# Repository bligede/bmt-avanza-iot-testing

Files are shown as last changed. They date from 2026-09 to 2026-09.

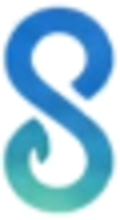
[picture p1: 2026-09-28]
web-argo/assets/mark.png

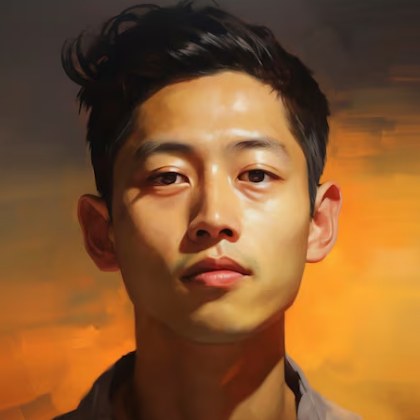
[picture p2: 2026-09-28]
web-argo/assets/driver.jpg

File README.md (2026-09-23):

# bmt-avanza-iot-testing

Bring-up firmware for the **Avanza CAN reading test**. ESP32-S3 + SN65HVD230,
WiFi hotspot, live web dashboard. Built with **PlatformIO**.

Fleet firmware lives in
[bligede/bmt-can-bus-telemetry](https://github.com/bligede/bmt-can-bus-telemetry).
This is a separate, focused diagnostic tool — not a subset of the product.

---

## The one rule

**The device is listen-only, permanently.** It reads the vehicle CAN bus and
never writes to it — no data frames, no remote frames, no ACK, no error frames.

Enforced in three independent places:

| Layer | Mechanism |
|---|---|
| Controller | `TWAI_MODE_LISTEN_ONLY`; `CanManager` refuses to start in any other mode |
| Compiler | `#pragma GCC poison` on the transmit entry points — a call fails to build |
| Release gate | `sh tools/check_listen_only.sh` |

Run the gate before any build that goes near a vehicle.

---

## Where the project documentation lives

`ProjectDocs/` is the handover layer: who decides, what was decided, the
environment map, current state, and what NOT to do. Start at
`ProjectDocs/agent-documentation/00-START-HERE.md`.

It **routes** to `docs/`; it does not duplicate it. The test reports, the
evidence and the procedures stay where they are, and so do the paths that
`project-mdt-tds` references.

---

## What this answers, and what it does not

| Question | |
|---|---|
| Can the device passively read a real vehicle CAN bus? | **this is the point** |
| Does listen-only hold on a live vehicle? | yes |
| Does WiFi hurt CAN acquisition? | measured — see below |
| Does the GNSS module work, and NmeaParser with it? | yes — first run on hardware |
| How hot does the enclosure actually get? | yes — the fleet's open thermal TODO |
| Are the fleet's odometer / SoC / speed CAN IDs found? | **no.** Wrong vehicle |
| Does the 4G + MQTT + TLS uplink work? | **no.** Not present at all |

Three modules get their first hardware run here, all of them on the fleet
project's *NOT TESTED* list: **`NmeaParser`** (21 unit tests, zero executions),
the **bit-banged DHT22 driver** (written from the datasheet, never run), and the
**fan hysteresis**. Retiring them costs nothing extra on this trip.

The thermal panel exists for a specific open question: `FAN_ON_TEMP` and
`FAN_OFF_TEMP` in the fleet firmware are placeholders marked *TODO — VALIDASI
TERMAL*, because nobody has measured an enclosure in a parked car in Bali sun.
The dashboard shows **both** the DHT22 enclosure reading and the SoC die
temperature; the gap between them is the number that decision needs.

> Avanza CAN IDs prove the **reading path**. They are **not** a signal map.
> Nothing found here may be copied into the fleet's `signals.cfg` — Toyota and
> Wuling identifiers have no relationship, and a plausible-looking wrong number
> is the worst failure mode a fleet dataset can have.

An Avanza is a petrol car: **there is no state of charge**, and unlike the fleet
EV it does have standard OBD-II PIDs. Neither fact helps the fleet; both are
recorded so nobody draws the wrong conclusion from an easy result here.

---

## Quick start

### 1. Open in VS Code

Install the **PlatformIO IDE** extension, then `File → Open Folder` on this
repository. PlatformIO reads `platformio.ini` and installs the ESP32 platform on
first build. No libraries to add — this project has **zero third-party
dependencies**.

### 2. Credentials

```sh
cp src/Secrets.h.example src/Secrets.h
```

Fill in the hotspot SSID and password. `src/Secrets.h` is git-ignored.

> **The ESP32-S3 radio is 2.4 GHz only.** A 5 GHz hotspot will never be found,
> and the symptom is an endless `CONNECTING → IDLE` loop. Android: *Hotspot
> settings → AP Band → 2.4 GHz*. iPhone: enable *Maximise Compatibility*.

### 3. Check the board

`platformio.ini` assumes an **8 MB** `esp32-s3-devkitc-1`. For a 4 MB board,
change two lines:

```ini
board_build.partitions  = partitions/avanza_test_4mb.csv
board_upload.flash_size = 4MB
```

### 4. Build, upload, monitor

| | PlatformIO toolbar | Command line |
|---|---|---|
| Build | ✓ | `pio run -e <vehicle>` |
| Upload | → | `pio run -e <vehicle> -t upload` |
| Monitor | 🔌 | `pio device monitor` |

**Pick the vehicle first.** Each vehicle under test has its own env at the end of
`platformio.ini`; the toolbar builds `default_envs`.

| Env | Vehicle | Bitrate | `UNIT_ID` |
|---|---|---|---|
| `hrv` | Honda HR-V 2023 | 500 kbps, measured | `HRV-TEST-01` |
| `gelora-e` | DFSK Gelora E | 500 kbps, **not yet measured** | `GELORAE-TEST-01` |
| `gelora-e-250k` | DFSK Gelora E | 250 kbps | `GELORAE-TEST-01` |

The env sets `UNIT_ID`, which goes into every capture header, and the folder the
identifier names are kept in (`/notes/<UNIT_ID>/`). Identifier numbers repeat
across makes, so one car's names must never appear against another car's IDs.
A build with no vehicle selected stops with an error instead of guessing.

If upload fails: hold **BOOT** (GPIO0), tap **RESET**, release BOOT, retry.

### 5. Verify before going near a vehicle

```sh
sh tools/check_listen_only.sh
```

Must print `LISTEN-ONLY GATE: PASS`. Do not flash a build that fails it.

---

## Wiring

| Function | Pin | Device |
|---|---|---|
| CAN TX | GPIO5 | SN65HVD230 `D` — never driven in listen-only |
| CAN RX | GPIO4 | SN65HVD230 `R` |
| GPS RX | GPIO18 | ← GY-GPS6MV2 TX |
| GPS TX | — | **not connected** — GPIO19 is USB_D− on the ESP32-S3. Firmware only listens to NMEA |
| DHT22 | GPIO15 | DATA |
| Fan | GPIO13 | → 330 Ω → IRLZ44N gate |
| LED red | GPIO21 | via resistor |
| LED green | GPIO47 | via resistor |
| Button | GPIO0 | momentary, active low — **RESERVED**, prints status |

The SN65HVD230 also needs 3V3 and GND from the ESP32.

Everything except CAN is optional. A missing GPS, an unwired DHT22 or no fan
clears its own reading and touches nothing else — CAN acquisition is unaffected.

| OBD-II | To |
|---|---|
| pin 6 | CANH |
| pin 14 | CANL |
| pin 5 | ESP32 GND |
| **pin 16** | **nothing** — power the ESP32 from USB |

LED common cathode to GND.

### The 120 Ω terminator — staged, not removed once

A CAN bus needs 120 Ω at each end, about **60 Ω across CANH–CANL**. Where those
come from changes between bench and vehicle:

| Stage | Termination source | Module's 120 Ω |
|---|---|---|
| **Bench**, two nodes | The two nodes *are* the two ends | **KEEP FITTED** |
| **Vehicle** | The car is already terminated at ~60 Ω | **REMOVE** |

Being listen-only does not exempt the receiver from being a properly terminated
node. Measure ~60 Ω across the bus in **both** cases before powering anything.

---

## Before connecting to the car

Ignition **off**, key removed. Measure OBD-II pin 6 to pin 14:

| Reading | Meaning | Action |
|---|---|---|
| ~60 Ω | CAN present, terminated | proceed |
| ~120 Ω | one terminator | record, proceed |
| **open** | **no CAN on these pins** | **stop** — see below |

An **Avanza Gen 1 (2003–2011)** may use K-line on pins 7/15 and have no CAN on
6/14 at all. The resistance check settles it in thirty seconds; use a different
vehicle rather than debugging firmware that is behaving correctly.

Record the model year.

---

## The failure that wastes an afternoon

**A healthy car can produce zero frames.**

On many vehicles the OBD-II port exposes a *diagnostic* CAN channel that stays
silent until a scan tool sends a request. This device is listen-only and never
sends anything. So a perfectly good Avanza can give you:

```
resistance 6–14 : 60 Ω     ✓ bus present
frames received : 0        ✗
```

That is not a broken device, a wrong bitrate, or bad wiring — it may simply be a
gateway that does not broadcast to the port.

**Prove the device on the bench first**, with a second CAN node transmitting.
Then "no frames" is a fact about the car rather than a mystery about the tool.
The bench test is not optional; it is what makes the vehicle result readable.

---

## Using it

Power up, open the serial monitor at 115200. Once WiFi connects:

```
[WIFI] Connected. IP 192.168.43.101, RSSI -52 dBm
[WIFI] Dashboard: http://192.168.43.101/
```

Open that URL on the phone.

### LED indicators

800 ms cycle. Highest-priority state wins.

**Red means something is broken. Red does NOT mean "waiting".**

| Pattern | Meaning | What to do |
|---|---|---|
| 🔴🟢 alternating | booting | wait ~0.5 s |
| 🔴 **solid** | filesystem dead | LittleFS would not mount |
| 🔴 **fast blink** | **CAN driver failed** | wiring, or `twai_driver_install` failed — check the log |
| 🟢 **heartbeat** (2 short flashes) | **CAN frames arriving** — the goal | nothing, this is success |
| 🟢 steady with a **brief red wink** | GPS is talking but has no fix yet | wait, or get sky view |
| 🟢 **fast blink** | WiFi connecting | wait, or check SSID/2.4 GHz |
| 🟢 **slow blink** | WiFi up, **no CAN frames yet** | normal on a bench with no bus attached |

A bench board with WiFi up and nothing on CANH/CANL shows the **slow green
blink**. That is the correct idle state, not a fault.

### Dashboard

| Panel | What matters |
|---|---|
| **Bus status** | the verdict sentence; `received` climbing; `missed` is the driver's own count of **frames** lost |
| **Identifiers** | every ID on the bus in ID order, latest bytes in **hex with decimal underneath**, bytes that just changed lit, silent IDs dimmed, an empty **Name** field beside each ID, ready to fill in and save — one view, no scrolling |
| **Signal probe** | pick an ID, start byte, width, byte order: the decoded value live, with a sparkline |
| **Health** | is the ESP32 keeping up — queue peaks, stack headroom per task, heap low-water, loop lag, CPU per core |
| **Capture** | frames written, operator markers, and the capture **files, downloadable** |
| **GNSS** | fix, satellites heard, strongest signal — and a sentence naming the fault |
| **Thermal** | DHT22 enclosure temp *and* SoC die temp, fan state |
| **Device** | unit, WiFi, wall clock, and what the status LED is saying |

Type a note into the Identifiers table while testing — "moves with the brake
pedal" — and press Enter. Notes are saved on the device under `/notes/`, **apart
from the captures**: a note is what somebody thinks an identifier is, and that is
kept separate from the evidence (D-015). Every edit is journalled with its time.

The Health verdict reads **Overworked** only on things that precede lost data: a
queue near full, a stack near its end, the heap near empty, frames being lost
right now. CPU load is shown but not trusted for it — see `SystemHealth.h` for why
the figure under-states load on this framework.

### Console

```
help              command list
status            full report
ids               distinct CAN IDs with counts
gps               GNSS fix, ground speed, UTC
env               DHT22 temperature and humidity
fan               fan state and thresholds
fan auto|on|off   fan mode
wifi              WiFi state and dashboard URL
capture file      raw frames to flash (default, on from boot)
capture off
ls                list capture files
cat <path>        print a capture — this is how you pull it off
clearcaptures
restart
```

Capture starts automatically at boot, so a session that only turns out to be
interesting halfway through has still been recorded.

### Pulling and analysing a capture

**Over WiFi (preferred):** the Capture panel lists every file on the device;
click one to download it. Take finished segments — the one marked *writing* still
lacks what sits in RAM. The notes journal is listed there too.

**Over the serial console:**

```
capture off
ls
cat /capture/can-000.log
```

**For the reverse-engineering skill** (`cansub-reverse-engineering`), convert to
webCAN CSV first:

```sh
python tools/capture_to_webcan.py can-003.log can-004.log -o captures/run-002.csv
```

It refuses to put files from two different boots on one timeline, and says so
when a capture has no wall-clock header. Operator markers go to
`run-002.markers.csv`.

For a quick known-value search without the skill:

```sh
python tools/can_find_value.py captures/avanza-....log --value 40 \
    --name speed --tolerance 1 --no-stable
```

The tool searches for a value you read off the dashboard across every plausible
field position, width, endianness and scale. **A candidate is a hypothesis, not
a mapping** — and on an Avanza it is a hypothesis about a Toyota, which the
fleet does not run.

---

## Known risk: WiFi versus CAN acquisition

Disclosed because it is real and unmeasured.

The ESP-IDF WiFi driver runs its own tasks at a **higher priority than the CAN
reader**, and depending on the core build may schedule them on **core 0** — the
core reserved for acquisition.

Mitigations in place: the TWAI hardware FIFO plus a 64-deep driver queue absorb
short preemption; the dashboard is the lowest-priority task on core 1; frames
reach it through a queue on core 1, so the reader only does one non-blocking
enqueue.

**None of that has been measured yet.** The Health panel now measures it — the
CAN driver queue peak, frames lost by the driver, and CPU per core. Treat it as an
acceptance criterion:

- [ ] Health → *Frames lost by driver* stays 0 with the dashboard being polled
- [ ] Health → *CAN driver queue* peak stays well under half
- [ ] `dropped` stays 0
- [ ] a 2-minute window with the dashboard open matches 2 minutes with it closed

If those counters move, record it. That finding matters more than a clean pass.

---

## Layout

```
platformio.ini            build config
src/
  main.cpp                setup + FreeRTOS tasks
  Config.h                every tunable
  Secrets.h.example       copy to Secrets.h
  CanBusSafety.h          the compile-time transmit ban
  CanManager.*            TWAI receive, listen-only locked
  GpsManager.* NmeaParser.*   GNSS fix, ground speed, UTC
  EnvironmentManager.*    DHT22 temperature and humidity
  FanManager.*            fan with hysteresis and dwell
  ButtonManager.*         GPIO0, reserved
  RawCanLogger.*          capture to serial and/or LittleFS
  WifiManager.*           non-blocking WiFi state machine
  WebDashboard.*          HTTP routes only
  StateJson.*             the JSON documents the page reads
  JsonWriter.h            bounded JSON writer, zero dependencies
  FrameRing.*             last frames, for /api/frames
  NotesStore.*            identifier notes, kept apart from captures
  SystemHealth.*          heap, stacks, queues, loop lag, CPU per core
  generated/WebAssets.h   GENERATED from web/ at build time — do not edit
  SerialConsole.*         technician console
  StatusLed.*             non-blocking LED patterns
  WatchdogManager.*       10 s task watchdog
  Logger.*                levelled console
web/                      the dashboard: index.html, app.css, app.js
hardware/                 PCB rev A: generator, KiCad schematic, BOM, netlist, verifier
partitions/               flash layouts
tools/
  check_listen_only.sh    release gate
  embed_web.py            web/ -> gzipped header, runs before every build
  capture_to_webcan.py    capture files -> webCAN CSV for the RE skill
  can_find_value.py       known-value search over a capture
captures/                 raw logs (git-ignored)
docs/RUN-PROCEDURE.md     how to run a controlled drive
docs/PHASE-2-DASHBOARD.md phase-2 plan, CEO questions, RE workflow
docs/evidence/            test artifacts
```

`CanBusSafety`, `Logger`, `StatusLed`, `WatchdogManager` and `WifiManager` are
copied from `bmt-can-bus-telemetry@7586b27` unmodified.

**Two are no longer identical, and this says so rather than pretend otherwise.**
The rule used to be "fix it in the fleet repo and re-copy". That repo is under a
feature freeze (its D-006), so both changes were made here and must be ported
back when the freeze lifts:

| File | Diverged in | What changed | Why |
|---|---|---|---|
| `RawCanLogger` | `fd386ba` | 4 KB RAM write buffer; segment header with unit, firmware, bitrate, boot epoch; `mark()`; queue-drop count | the writer fell behind the bus at ~1,300 frames/s (review F-05) |
| `CanManager` | Phase 2 dashboard | per-ID latest payload under a seqlock (`survey`, `seenIdSnapshot`); `driverCounters()` exposing the TWAI driver's own frame counts | the monitor table needs payloads; "missed" was counting alert events, not frames (review F-02) |

The listen-only mechanism itself is untouched in both: `TWAI_MODE_LISTEN_ONLY`,
the poison pragma and the release gate are exactly as in the fleet firmware.

---

## Evidence

Raw evidence is immutable after a test. `serial-log.txt` is the primary source;
`result.md` carries the interpretation and may be revised.

Save the **whole** serial session, from the first boot line — not just the
interesting part. Reset reason, init order, warnings, heap and startup timing
are what answer "was our hardware ever healthy?" when a later test goes wrong.

Record failures too. A folder saying FAIL with the log attached is worth more
than a missing one.

---

## Legal boundary

This device is **not** a legal measuring instrument. Its output must never be
used to calculate passenger fares.

## Classification

Internal — PT Bali Mikro Teknologi.

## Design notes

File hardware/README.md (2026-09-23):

# PCB BMT CAN logger, rev A

Satu papan untuk dua peran, dirakit dan disolder sendiri:

| Peran | Yang dipasang |
|---|---|
| **Perangkat uji** | semua, **kecuali** bagian bertanda `FLEET` |
| **Unit armada** | semua, termasuk bagian modem A7670C |

**Status: rancangan, belum pernah diproduksi.** Rangkaian sudah diperiksa secara otomatis
(lihat §7), tetapi berkasnya belum pernah dibuka di KiCad maupun EasyEDA. Keduanya belum
terpasang di mesin tempat berkas ini dibuat. Sebelum memesan PCB, kerjakan dulu daftar
di §8.

---

## 1. Berkas

| Berkas | Isi |
|---|---|
| `gen_schematic.py` | **sumber kebenaran**: seluruh rangkaian sebagai data. Ubah di sini, bukan di berkas hasil |
| `bmt-can-logger.kicad_sch` | schematic KiCad 7 hasil generator, untuk diimpor ke EasyEDA |
| `bmt-can-logger.kicad_pro` | berkas proyek minimal supaya KiCad membukanya sebagai proyek |
| `netlist.csv` | 37 net: nama net → `REF.pin`. Cadangan kalau impor gagal |
| `bom.csv` | daftar belanja: kolom `fit` = `ALL` atau `FLEET` |
| `schematic-preview.svg` | gambar schematic, cukup dibuka di browser |
| `verify_schematic.py` | membaca ulang `.kicad_sch` dan membuktikan isinya |
| `render_preview.py` | membuat `schematic-preview.svg` |

Setelah mengubah rangkaian:

```
python gen_schematic.py && python verify_schematic.py && python render_preview.py
```

---

## 2. Blok rangkaian

```
 12 V ACC ─ J1 ─ F1 PTC ─┬─ D1 1N5822 ─ VIN_P ─┬─ U1 LM2576HV-5.0 ─ +5V ─┬─ D3 ─ DevKit 5V
 (fuse tap, 3 A)         │                     │                         ├─ U3 VCC (CAN)
                         D2 1.5KE27A           │                         ├─ GPS
                         (surge / polaritas)   │                         └─ kipas (JP3)
                                               └─ U2 LM2576HV-ADJ ─ +4V0 ─ JP1 ─ modem   [FLEET]

 OBD-II 6/14/5 ─ J2 ─ D4 ESD ─ U3 TJA1051T/3 (S = HIGH → Silent) ─ RXD ─ GPIO4
                         └ R5 120 R ─ JP2 (bench saja)

 DevKit 3V3 ─ U3 VIO, DHT22, pull-up        GPIO18 ← GPS    GPIO15 ↔ DHT22
 GPIO13 → Q1 kipas    GPIO21/47 → LED     GPIO0 ← tombol
 GPIO16/17 ↔ Q3/Q4 (1,8 V ↔ 3,3 V) ↔ modem    GPIO14 → Q2 → PWRKEY     [FLEET]
```

Semua GPIO sama dengan firmware yang sudah jalan. **Firmware uji tidak perlu diubah.**

---

## 3. Keputusan rancangan dan alasannya

| Keputusan | Alasan |
|---|---|
| **TJA1051T/3, pin S diikat ke 3V3** (bukan SN65HVD230) | Pada mode Silent, pemancar transceiver **mati di dalam chip** (datasheet NXP §7.1.2). Tidak ada jumper, tidak ada GPIO, tidak ada bug firmware yang bisa menyalakannya. Ini lapis keempat jaminan listen-only, dan satu-satunya yang berupa hardware. SN65HVD230 tidak punya mode diam |
| **J2 hanya punya 3 kutub: CANH, CANL, GND** | OBD-II pin 16 tidak boleh disambung (fleet `01-PINOUT`, Blueprint §5.2). Konektornya tidak punya tempat untuk pin 16, jadi tidak ada yang bisa salah sambung |
| **Catu dari fuse tap ACC** lewat J1, sekring blade 3 A di kabel | Sumber terpisah dengan sekring dan proteksi sendiri, sesuai aturan pin 16. ACC mati saat kunci dicabut, jadi alat tidak menguras aki saat parkir (F-15) |
| F1 PTC 1,6 A / 72 V + D2 TVS 1.5KE27A + D1 Schottky | Lonjakan tegangan dijepit maksimum 37,5 V. Kalau polaritas terbalik, D2 menghantar sehingga F1 memutus, dan D1 memblokir |
| **LM2576HV** (TO-220, input sampai 60 V) | Kaki besar, mudah disolder, dan tahan di atas batas jepit TVS 37,5 V. Modul buck murah (MP1584 maks 28 V) tidak tahan |
| **D3** antara +5V dan pin 5V DevKit | Espressif menyebut catu USB dan catu pin 5V *saling eksklusif*. D3 mencegah 5 V dari USB laptop mengalir balik ke papan saat keduanya tersambung |
| Modem lewat **Q3/Q4 BSS138** | UART A7670 bekerja di **1,8 V** (manual hardware SIMCom). Menyambungnya langsung ke GPIO 3,3 V akan merusaknya |
| **C6 2200 µF** tepat di J6 | Modem menarik hingga 2 A saat memancar. Tanpa kapasitor ini modem me-reset sendiri (fleet `01-PINOUT`) |
| **JP1** memilih catu modem 4,0 V atau 12 V | Modul A7670C polos butuh VBAT 3,4–4,2 V. Papan breakout umumnya punya regulator sendiri dan butuh 5–12 V. Belum pasti papan mana yang dibeli |
| Semua komponen THT, kecuali U3 (SOIC-8), D4, Q3, Q4 (SOT-23) | Disolder tangan. SOIC-8 dan SOT-23 masih bisa disolder dengan solder biasa. Tidak ada versi THT dari TJA1051 maupun PESD2CAN |
| IRLZ44N dan R 330 Ω untuk kipas | Sama dengan prototipe yang sudah terbukti jalan |

---

## 4. Membawanya ke EasyEDA

Pakai **EasyEDA Pro** (pro.easyeda.com), login dengan akun Google Anda.

1. File → Import → **KiCad**. Pilih `bmt-can-logger.kicad_sch`, atau zip seluruh folder
   `hardware/` lalu impor zip-nya.
2. Periksa hasilnya terhadap `schematic-preview.svg`: jumlah komponen **61**, jumlah net
   **37**.
3. **Footprint.** Nama footprint di schematic memakai nama pustaka KiCad. EasyEDA bisa saja
   tidak mengenalinya. Kalau kosong, pasang footprint per komponen dari kolom `footprint`
   di `bom.csv`. Cara paling cepat: cari part-nya di pustaka LCSC EasyEDA dengan nama MPN,
   misalnya `TJA1051T/3`, `LM2576HVT-5.0`, `1N5822`.
4. Design → Update/Convert to PCB.

**Kalau impor gagal:** gambar ulang schematic di EasyEDA dari `netlist.csv`. Isinya 37
baris, masing-masing satu net dengan semua pin yang tersambung. Kemungkinan besar
pekerjaannya satu sampai dua jam.

Proses impor ini **belum pernah dicoba**. Kalau ada pesan error, kirimkan pesannya ke saya.

---

## 5. Aturan tata letak PCB

**Papan:** 2 lapis, 1,6 mm, tembaga 1 oz (2 oz lebih baik untuk jalur modem). Sekitar
100 × 80 mm. Empat lubang M3 di sudut, 4 mm dari tepi.

| Bagian | Aturan |
|---|---|
| **Soket DevKit J10/J11** | jarak antar-baris **22,86 mm (900 mil)** dari pusat ke pusat, pitch 2,54. Angka ini hasil hitungan dari gambar dimensi Espressif, jadi **ukur dengan jangka sorong di DevKit Anda sebelum memesan** |
| **Antena ESP32** | ujung antena DevKit (sisi yang berlawanan dengan USB) harus menjorok keluar tepi PCB, atau area di bawahnya bebas tembaga di kedua lapis |
| **Buck U1/U2** | kapasitor input, U, dioda catch, dan L dirapatkan. Loop dioda catch dibuat sekecil mungkin. Letakkan jauh dari GPS dan antena |
| **Lebar jalur** | 12 V input dan jalur modem (+4V0, MODEM_PWR, GND-nya) ≥ 1,5 mm. +5V ≥ 1,0 mm. Sinyal 0,3 mm |
| **CAN** | CANH/CANL dirutekan berpasangan dan pendek: J2 → D4 → U3. D4 di dekat J2 |
| **U3** | C8 di pin 3 (VCC), C9 di pin 5 (VIO), masing-masing kurang dari 5 mm |
| **Modem** | C6 menempel pada J6. Jalur GND modem langsung ke pour GND, bukan lewat jalur tipis |
| **GND** | pour di kedua lapis, dijahit via setiap ±10 mm |
| **Silkscreen** | `JP2: OPEN DI MOBIL` · `J2: 6=CANH 14=CANL 5=GND, TANPA PIN 16` · polaritas J1 `+12V ACC / GND` · `JP5: OPEN` · penanda `FLEET` di komponen modem |

---

## 6. Menyolder dan menguji, tanpa mobil dulu

**Catatan penting:** transceiver CAN mendapat 5 V dari buck, bukan dari USB. **USB saja
tidak cukup.** Di meja kerja pun papan butuh 12 V, dari power supply bench.

Urutan menyolder: yang paling pendek dulu. Resistor dan dioda, lalu U3, D4, Q3, Q4 (SMD),
lalu soket, kapasitor, konektor, U1/U2, dan terakhir kapasitor elektrolit besar.

Pengujian bertahap. Pakai power supply bench **12 V dengan batas arus 300 mA**, dan
**DevKit belum dipasang**:

| # | Uji | Lulus kalau |
|---|---|---|
| 1 | arus diam tanpa DevKit | < 30 mA |
| 2 | TP1 (VIN_P) | ± 11,5 V (12 V dikurangi drop D1) |
| 3 | TP3 (+5V) | 4,8–5,2 V |
| 4 | tanpa DevKit, ukur J4 pin 1 | 0 V. 3V3 berasal dari DevKit, jadi ini normal |
| 5 | pasang DevKit, nyalakan | J4 pin 1 = 3,3 V. Firmware boot, dashboard muncul |
| 6 | colok USB laptop bersamaan | tetap stabil. TP3 tidak naik |
| 7 | bench CAN dua node, **JP2 tertutup** | frame diterima seperti di prototipe |
| 8 | bench CAN, node pengirim hanya punya papan ini sebagai lawan | node pengirim melaporkan **ACK error**. Itu **bukti** pemancar U3 memang mati: papan ini tidak bisa mengakui frame |
| 9 | **[FLEET]** JP1 di posisi 1-2, **modem belum dipasang** | TP4 = 3,85–4,05 V. **Jangan lanjut kalau di atas 4,2 V** |
| 10 | **[FLEET]** pasang modem, JP5 OPEN | modem menyala lewat PWRKEY (GPIO14) atau tombol di papannya |

Baru setelah semuanya lulus: ke mobil. Ikuti `docs/RUN-PROCEDURE.md`. Ukur hambatan
OBD 6–14 dengan kunci kontak mati, dan **buka JP2**.

---

## 7. Apa yang sudah dibuktikan, dan dengan cara apa

`verify_schematic.py` tidak memakai generator sama sekali. Ia mem-parse `.kicad_sch`
sendiri, membangun ulang semua sambungan dari koordinat (ujung pin, kawat, label,
tanda no-connect), lalu:

- mencocokkan hasilnya dengan `netlist.csv`: **187 pin, 160 tersambung, 27 sengaja
  tidak dipakai**;
- gagal kalau ada pin yang tidak tersambung sekaligus tidak ditandai, atau net yang
  hanya punya satu sambungan;
- memeriksa 12 aturan keselamatan satu per satu, antara lain: U3 pin S di 3V3; J2 tidak
  menyentuh jalur catu apa pun; GPIO19/20 (USB) kosong; modem hanya dicatu lewat JP1.

Pemeriksa itu sendiri sudah diuji dengan tiga kesalahan yang disengaja: label yang salah,
tanda no-connect yang hilang, dan kawat yang bergeser 1,27 mm. **Ketiganya tertangkap.**

Fakta datasheet yang dipakai sudah dicocokkan dengan sumber pabrikan: pinout DevKitC-1
dan jarak barisnya (Espressif), TJA1051 (NXP), LM2576HV (TI), MF-RX160/72 (Bourns),
1.5KE27A (Littelfuse), PESD2CAN (Nexperia), dan A7670 (manual hardware SIMCom, dari salinan
Waveshare).

**Yang belum dibuktikan:** berkas ini belum pernah dibuka di KiCad atau EasyEDA, belum ada
ERC dari tool EDA, dan belum ada PCB yang dibuat.

---

## 8. Wajib dicek sebelum memesan PCB

1. **Papan modem yang akan dibeli.** Cocokkan urutan pin J6 dengan papan itu, lalu
   tentukan posisi JP1 (4 V untuk VBAT modul polos, atau 12 V untuk breakout yang punya
   regulator) dan JP4 (tutup hanya kalau UART papannya 3,3 V dan tidak punya pin VREF).
   Ubah `J6` di `gen_schematic.py` bila perlu, lalu jalankan ulang generator.
2. **Jarak baris soket DevKit**: ukur DevKit Anda. Nilai 22,86 mm adalah hasil hitungan.
3. **Urutan kaki LED dua warna** yang dibeli. Rancangan ini menganggap R–K–G, dengan
   katoda di tengah.
4. **Tegangan kipas**: posisi JP3 menentukan 5 V atau 12 V.
5. **Induktor L1/L2**: 100 µH dengan arus saturasi ≥ 3 A. Ukur diameter dan jarak kakinya,
   lalu pilih footprint yang cocok. Kolom footprint di BOM sengaja dikosongkan untuk
   komponen ini.
6. **JP5 (AUTO-ON) tetap OPEN** sampai terbukti di modul yang sebenarnya. Manual A7670
   tidak menjamin PWRKEY boleh diikat ke GND terus-menerus.

## 10. Yang harus masuk rev B: slot microSD

Pengujian 22 Sep 2026 menunjukkan alat **kehilangan frame justru saat merekam**:
4,9 % di Gelora E, 22 sampai 26 % di Honda HR-V. Sebabnya bukan kecepatan CPU,
melainkan letak rutin interupsi CAN di flash. Saat flash ditulis, cache instruksi
mati, interupsi berhenti, dan FIFO controller meluap. Rinciannya di
[`docs/evidence/00-umum/frame-loss.md`](../docs/evidence/00-umum/frame-loss.md).

Menulis ke **kartu microSD lewat SPI tidak menyentuh flash internal**, jadi
interupsi tetap jalan. Tambahan yang diperlukan di rev B:

| Bagian | Keterangan |
|---|---|
| Soket microSD | mode SPI sudah cukup |
| Empat GPIO | MISO, MOSI, SCK, CS. Masih banyak yang bebas di header DevKit |
| Pull-up 10 kΩ pada CS dan MISO | mencegah pin mengambang saat kartu belum siap |
| Kapasitor 10 µF dekat soket | kartu SD menarik arus berdenyut saat menulis |

Nilai tambahnya ganda: kehilangan frame hilang, dan batas rekaman 12 MB naik
menjadi sebesar kartunya.

---

## 9. Dampak ke firmware dan repo armada

- **Firmware uji:** tidak ada perubahan. Semua pin sama.
- **Firmware armada (dibekukan, D-006):** tidak wajib diubah. `MODEM_PWRKEY_PIN` bisa
  menjadi `14` kelak, kalau PWRKEY dikendalikan lewat Q2. Dokumen armada `01-PINOUT`
  masih menyebut SN65HVD230. Transceiver di papan ini berbeda, tetapi driver TWAI tidak
  terpengaruh. Catat perbedaan ini saat freeze dibuka.
- **Batas yang tidak ikut berubah:** papan ini tetap listen-only. Mode Silent di U3
  melengkapi mode `TWAI_MODE_LISTEN_ONLY` di firmware, bukan menggantikannya.

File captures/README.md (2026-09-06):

# captures/

Raw CAN captures pulled off the device. The `.log` files themselves are
git-ignored — they are large and per-vehicle. What belongs in git is the
finding, not the raw bus traffic.

## Naming

```
avanza-<year>-<plate-or-vin6>-<yyyymmdd>-<hhmm>-<what>.log
```

Example:

```
avanza-2016-B1234XY-20260824-1030-ignition-on-stationary.log
avanza-2016-B1234XY-20260824-1105-driving-40kmh.log
```

Put the observed dashboard reading in the filename. A capture whose dashboard
value nobody wrote down is nearly worthless later.

## Pulling one off the device

```
capture off
ls
cat /capture/can-000.log
```

Save the console output here.

## Searching one

```sh
python ../tools/can_find_value.py <file> --value 40 --name speed \
    --tolerance 1 --no-stable
```

Remember: an Avanza candidate is a hypothesis about a **Toyota**. The fleet runs
a Wuling EV. Nothing found here transfers.

## Safety

Capturing while driving is a **two-person** job. One drives, one operates.

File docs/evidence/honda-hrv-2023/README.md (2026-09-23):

# Honda HR-V 2023

Mobil penumpang bermesin bensin. Kendaraan uji pertama, dipakai untuk membuktikan bahwa
alat ini bisa membaca bus kendaraan sungguhan.

| | |
|---|---|
| Env PlatformIO | `hrv` |
| UNIT_ID | `HRV-TEST-01` |
| Bitrate | **500 kbps**, terukur |
| Bentuk identifier | 11-bit standard |
| Kepadatan bus | sekitar 1.000 frame per detik, jauh lebih padat daripada Gelora E |

## Sesi

| Run | Tanggal | Kondisi | Isi | Berkas |
|---|---|---|---|---|
| `hrv-001` | 8 Sep 2026 | kendaraan hidup | 194.219 frame, 40 identifier | [hrv-001.md](hrv-001.md) |

Kandidat sinyalnya terpisah di [hrv-001-candidates.md](hrv-001-candidates.md), karena
kandidat adalah tafsiran dan harus bisa direvisi tanpa menyentuh dokumen asal-usulnya.

Rekamannya ditarik 20 September 2026 dan keutuhannya diperiksa: 34 berkas, seluruh 34
sidik jari SHA-256 cocok, dan dua kali unduh ulang menghasilkan berkas yang identik.

## Status pemetaan

**Kandidat, belum satu pun terbukti.** Seluruh nilai diambil tanpa sesi sambil berjalan,
jadi statusnya sama persis dengan status Gelora E sebelum 23 September: cocok di atas
kertas, belum pernah diadu dengan nilai yang bergerak.

Untuk menaikkannya, kendaraan ini butuh satu kali uji jalan mengikuti
`docs/PROSEDUR-TEST-JALAN.md`.

## Yang perlu diperhatikan kalau sesi berikutnya jadi

Bus HR-V sekitar 1.000 frame per detik, jadi kehilangan frame saat merekam ke flash
internal mencapai **22 sampai 26 persen**, jauh lebih buruk daripada 14,8 % pada Gelora
E. Sesi berikutnya **wajib** memakai aliran WiFi dengan perekaman flash dijeda. Lihat
[../00-umum/frame-loss.md](../00-umum/frame-loss.md).

## Batas pemakaian

HR-V adalah mobil bensin. **Tidak ada state of charge**, dan tidak ada satu pun besaran
baterai traksi. Armada memakai kendaraan listrik Wuling, jadi identifier di sini tidak
punya hubungan apa pun dengan armada. Yang dibuktikan kendaraan ini adalah **jalur
bacanya**, bukan peta sinyalnya.

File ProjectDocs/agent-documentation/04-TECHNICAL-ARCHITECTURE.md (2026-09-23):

# 04: Arsitektur teknis

## Peta environment dan cara menjalankan

Project ini tidak punya environment server. Yang setara dengan "environment" di sini
adalah **kendaraan yang sedang diuji**, karena identitas kendaraan ditetapkan saat build
(D-002).

| Env PlatformIO | Kendaraan | Bitrate | UNIT_ID |
|---|---|---|---|
| `hrv` | Honda HR-V 2023 | 500 kbps | `HRV-TEST-01` |
| `gelora-e` | DFSK Gelora E | 500 kbps | `GELORAE-TEST-01` |
| `gelora-e-250k` | DFSK Gelora E | 250 kbps, yang benar | `GELORAE-TEST-01` |

`default_envs` di `platformio.ini` menentukan mana yang dipakai kalau `-e` tidak
disebutkan. Nilainya sekarang `gelora-e`.

```
pio run -e gelora-e-250k                 build
pio run -e gelora-e-250k -t upload       flash lewat USB
pio device monitor                       serial, 115200
sh tools/check_listen_only.sh            gate rilis, jalankan sebelum ke kendaraan
```

Pembaruan firmware **hanya lewat USB**. OTA dibatalkan, lihat D-004.

### Port dan alamat saat alat menyala

| Apa | Di mana |
|---|---|
| Dashboard web | port 80, di alamat IP yang dicetak alat ke serial saat boot |
| Aliran frame langsung | port 3333, TCP, satu penerima pada satu waktu |
| Serial | 115200, tanpa filter |

Alamat IP alat **berubah tiap jaringan**. Pada sesi 22 Sep alamatnya `192.168.100.41`,
pada sesi 23 Sep lewat hotspot HP alamatnya `10.215.81.4`. Jangan menghafal alamat, baca
dari serial atau dari header dashboard.

### Endpoint dashboard

| Endpoint | Guna |
|---|---|
| `GET /api/state` | seluruh status alat, termasuk penghitung frame hilang |
| `GET /api/frames` | frame terakhir yang terlihat |
| `GET /api/captures`, `/api/capture` | daftar dan isi berkas rekaman |
| `POST /api/note`, `GET /api/notes` | nama untuk sebuah identifier, disimpan terpisah dari rekaman |
| `POST /api/mark` | menandai bahwa sesuatu terjadi pada suatu saat |
| `POST /api/sink` | menjeda atau melanjutkan perekaman ke flash |
| `POST /api/clear` | menghapus rekaman, wajib menyertakan UNIT_ID sebagai konfirmasi |

### Lokasi rahasia

Kredensial WiFi ada di **`src/Secrets.h`**, yang di-gitignore dan tidak pernah
di-commit. Templat tanpa nilai ada di `src/Secrets.h.example` dan berisi dua nama:
`WIFI_SSID` dan `WIFI_PASS`.

Jangan menulis kredensial ke `ProjectDocs/`, ke `docs/`, ke pesan commit, atau ke konsol
serial. Token GitHub pernah bocor ke keluaran terminal pada 22 Sep 2026 karena kutip
perintah yang keliru di PowerShell, dan token itu harus dicabut. Kejadian itu tercatat di
`09-TEMUAN-EVALUASI-PROSES.md`.

## Perangkat keras

| Bagian | Pilihan |
|---|---|
| Papan | ESP32-S3-DevKitC-1 N16R8 |
| Transceiver CAN | SN65HVD230 |
| Sambungan kendaraan | kabel ke konektor OBD-II, pin 6 dan 14 |
| Sensor tambahan | GNSS, DHT22, kipas, LED, tombol |
| Framework | arduino-esp32 2.0.17 lewat PlatformIO |

Rancangan papan ada di `hardware/`, dibangkitkan dari satu berkas sumber tunggal
`hardware/gen_schematic.py` dan diperiksa ulang oleh `hardware/verify_schematic.py`.

Unit armada menambahkan modem A7670C. Itu **bukan** bagian dari alat uji ini.

## Pembagian tugas di dalam firmware

| Inti | Tugas |
|---|---|
| Core 0 | pembaca CAN, satu-satunya tugas di sana |
| Core 1 | penyimpanan, WiFi, dashboard, sensor, housekeeping |

Pemisahan itu disengaja: pembaca CAN tidak boleh menunggu apa pun. Aliran frame ke
laptop dipanggil dari tugas penyimpanan saja, satu pemilik, karena versi pertama yang
memanggilnya dari dua tugas membuat alat reboot begitu bus ramai.

## Organisasi kode

| Lokasi | Isi |
|---|---|
| `src/` | firmware. `CanManager`, `RawCanLogger`, `FrameStream`, `WebDashboard`, `NotesStore`, `WifiManager` |
| `web/` | sumber dashboard, ditanam ke firmware oleh `tools/embed_web.py` saat build |
| `tools/` | program bantu di laptop, Python dan satu skrip shell |
| `hardware/` | pembangkit dan pemeriksa skematik |
| `docs/` | prosedur, laporan pengujian, dan bukti |
| `captures/` | rekaman mentah, tidak ikut repositori |
| `partitions/` | tata letak partisi flash |

### Jalur data dan berkas

```
kendaraan (OBD-II pin 6/14)
   -> transceiver -> controller TWAI, listen-only
   -> antrean di RAM
   -> salah satu dari dua tujuan:
        a. flash internal -> captures/ di laptop lewat tools/fetch_captures.py
        b. TCP port 3333 -> langsung ke captures/ lewat tools/stream_capture.py
   -> tools/capture_to_webcan.py  -> CSV untuk analisis
```

Jalur (a) kehilangan sekitar 15 % frame dan dibatasi 12 MB. Jalur (b) tidak kehilangan
apa pun di sisi alat, tetapi bergantung pada kualitas WiFi. Lihat D-003.

### Aturan penempatan berkas

```
kode->src/ dan tools/ · masukan->captures/ · hasil analisis->docs/evidence/ · build->.pio/ (gitignored)
```

Berkas rekaman tidak pernah berada satu folder dengan program yang membacanya, dan tidak
pernah disunting setelah tes.

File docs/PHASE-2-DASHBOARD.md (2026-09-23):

# Fase 2 — dashboard web untuk memecahkan ID ECU

Rencana dua minggu dan catatan apa yang sudah dibangun. Mulai 13 September 2026.

## Masukan CEO BMT (dicatat apa adanya)

> tambahkan satu kolom input sebagai catatan saat nanti testing (diisi pada saat testing
> sebagai note dalam mengenali ID yang dikeluarkan oleh ECU)
> apa butuh library tinygsm? buat kode yang clean architectur, maintenable, modular
> tampilkan penggunaan memory internal di esp32 (mengetahui apa esp32 dalam performa yang
> baik ataukan overwork?)
> interface lcd apa bisa mengoutputkan html?
> apa bisa esp32 berkomunikasi dengan payment gateway?
> cari hmi android yang kompatibel dengan esp32
> fase 2 minngu kedepan, fokus di aplikasi via dashboard web, tampilkan dari data hex ke
> desimal, tabel jangan discroll agar mudah memantau data keseluruhan dalam 1 tampilan
> gunakan reverse engineering skill untuk ememcahkan kode id dan nilali hes dari ecu

---

## 1. Yang sudah dibangun

### Tabel identifier — satu tampilan, tanpa scroll

- Setiap ID di bus satu baris, **urut ID** — tidak berpindah-pindah saat hitungan berubah,
  jadi mata hafal letaknya.
- Byte 0–7 ditampilkan **hex di atas, desimal di bawah**.
- Byte yang berubah dalam 2 detik terakhir **menyala hijau**. Byte pencacah bergulir
  (biasanya byte terakhir) akan menyala terus — itu justru cara mengenalinya.
- ID yang diam lebih dari 2 detik **diredupkan**.
- Laju per ID dalam Hz, dihitung di jendela ±3 detik supaya ID 1 Hz tidak meloncat 0–2.
- Di layar ≥1280 px tabel dibagi **dua kolom berdampingan**: 40 ID muat dalam satu layar
  1440 px. Di HP tabel bisa digeser ke samping di dalam panelnya, tidak pernah atas-bawah.

### Kolom nama per ID, tepat di sebelah ID

- Kolom **Name** kosong dan siap diisi, letaknya persis di kanan kolom ID, sebelum Hz dan
  byte, sehingga terbaca berpasangan dengan ID-nya.
- Ketik di baris ID-nya, tekan Enter. Tersimpan di perangkat, bingkai hijau = tersimpan,
  merah = gagal (arahkan kursor untuk alasannya).
- Perangkat mengembalikan teks yang **benar-benar disimpan** (dipangkas, maks 60 byte
  UTF-8), dan kolom menampilkan itu — catatan tidak pernah tampak tersimpan dalam bentuk
  yang tidak disimpan.
- Disimpan di `/notes/ids.tsv`, dan setiap perubahan dicatat di `/notes/journal.log`
  beserta waktunya.
- **Sengaja tidak ditulis ke berkas capture.** Catatan adalah tafsiran, bukan bukti;
  keduanya dipisah (D-015). Tebakan yang salah bisa dikoreksi tanpa menyentuh rekaman run.

### Panel Health — ESP32 sehat atau kewalahan?

| Meter | Artinya |
|---|---|
| CAN driver queue | antrean frame di driver TWAI, puncak sejak boot |
| Capture queue | antrean frame menunggu penulis flash, puncak sejak boot |
| Frames lost by driver | `rx_missed_count` + `rx_overrun_count` — **frame**, bukan kejadian alert |
| Task stacks | tiap task: seberapa dekat pernah ke ujung stack-nya |
| Heap in use / low-water | pemakaian heap sekarang, dan titik terendahnya sejak boot |
| Loop lag | housekeeping tidur 50 ms; berapa lama jeda nyatanya |
| Core 0 / Core 1 | beban CPU per core, **perkiraan** |
| Flash filesystem, firmware image | ruang tersisa |

Verdict **Healthy / Tight / Overworked** hanya memakai angka yang bergerak *sebelum* data
hilang. Beban CPU ditampilkan tapi tidak dipakai untuk verdict: framework ini
(arduino-esp32 2.0.17) tidak menyertakan FreeRTOS run-time stats di varian sdkconfig mana
pun, jadi beban diukur lewat idle hook per core — dan cara itu **meremehkan** beban.

Kerugian yang terjadi *sekarang* dibedakan dari yang terjadi *tadi*: satu kejadian di
awal boot tidak membuat verdict merah selamanya.

### Berkas capture bisa diunduh lewat WiFi

Panel Capture menampilkan semua berkas di perangkat; klik untuk mengunduh. Tidak perlu
lagi `cat` lewat konsol serial di port FTDI.

### Arsitektur yang lebih rapi

`WebDashboard.cpp` dulu 1.084 baris: HTML, CSS, JavaScript, semua penyusun JSON, dan rute
dalam satu berkas. Mengubah satu kolom tabel berarti mengedit HTML di dalam string C++.

| Modul | Satu tanggung jawab |
|---|---|
| `web/index.html`, `app.css`, `app.js` | halaman, sebagai berkas web biasa |
| `tools/embed_web.py` | web/ → header gzip, otomatis sebelum setiap build |
| `WebDashboard` | rute HTTP saja |
| `StateJson` | bentuk dokumen JSON |
| `JsonWriter` | penulis JSON berbatas, nol dependensi |
| `NotesStore` | catatan per ID |
| `SystemHealth` | memori, stack, antrean, CPU |
| `FrameRing` | jejak frame mentah untuk `/api/frames` |

Halaman kini 57,8 KB → **19,5 KB gzip** di flash. Build tanpa warning pada `-Wall -Wextra`.

---

## 2. Dua koreksi yang ikut ditemukan

**"missed" menghitung kejadian, bukan frame** (review F-02). Angka lama menghitung alert
`RX_QUEUE_FULL`; satu alert bisa berarti banyak frame hilang. Driver TWAI punya penghitung
frame sendiri (`rx_missed_count`, `rx_overrun_count`), dan itulah yang sekarang ditampilkan
sebagai *missed*.

**Klaim "disalin tanpa perubahan" di README sudah tidak benar.** `RawCanLogger` diubah di
`fd386ba`, `CanManager` di fase ini. Repo armada sedang dibekukan, jadi keduanya tidak bisa
"diperbaiki di sana lalu disalin ulang". README sekarang menyatakan divergensinya dan apa
yang harus dipindahkan balik.

---

## 3. Alur memecahkan ID dengan skill reverse engineering

Skill `cansub-reverse-engineering` membaca **webCAN CSV** dan menyelaraskan rujukan lewat
epoch timestamp.

```
1. Unduh segmen capture yang sudah selesai dari panel Capture
2. python tools/capture_to_webcan.py can-003.log can-004.log -o captures/run-002.csv
3. Serahkan run-002.csv ke skill:
     survey     -> ID mana yang bergerak, byte mana pencacah/checksum
     correlate  -> dibutuhkan RUJUKAN (lihat di bawah)
     bitsearch  -> start bit, panjang, endianness
     build_dbc  -> skala, offset, jadi DBC
     verify
```

**Survei bisa langsung jalan** pada rekaman apa pun. **Korelasi butuh rujukan** — deret
nilai fisik yang diketahui pada waktu yang sama:

| Rujukan | Status |
|---|---|
| Kecepatan GNSS | antena mati |
| PID OBD-II | tidak mungkin — butuh mengirim request, melanggar listen-only |
| **Video panel instrumen** (mode VISION skill) | **jalur utama** — wajib direkam di run berikutnya |

### Soal foto panel instrumen HR-V (8 Sep): angka mana yang terekam?

**Terjawab pada 20 Sep 2026.** Rekaman penuh ditarik dari flash perangkat lewat WiFi
sebelum perangkat di-flash ulang: 34 berkas, 8,8 MB, satu run utuh 3 menit 23 detik.

| Angka di panel | Hasil |
|---|---|
| Odometer **069620 km** | `0x294`, byte 3-5 big-endian, di 100% frame ID itu |
| Suhu luar **29 °C** | `0x324`, byte 0, dengan rumus `°C = nilai - 40` |
| Trip A **1459,6 km** | tidak ada di bus ini |

Perkiraan lama bahwa rekaman hanya memuat "sekitar separuh frame" ternyata terlalu
pesimistis: ID berperiode 10 ms tercatat 78 Hz, bukan 100 Hz, jadi kehilangannya sekitar
22 sampai 26 persen dan merata di semua ID.

Rinciannya: [`docs/evidence/honda-hrv-2023/hrv-001.md`](evidence/honda-hrv-2023/hrv-001.md) untuk asal-usul dan
keutuhan data, [`hrv-001-candidates.md`](evidence/honda-hrv-2023/hrv-001-candidates.md) untuk kandidat
sinyal dan cara membuktikannya. Keduanya masih hipotesis sampai diuji sambil kendaraan
bergerak.

---

## 4. Jawaban untuk pertanyaan CEO

### Perlu TinyGSM?

**Tidak.** Modul A7670C punya stack MQTT, HTTP, dan TLS sendiri; firmware armada memakainya
lewat perintah AT, tanpa pustaka. Dukungan A76xx di TinyGSM upstream juga tidak sematang
SIM7600. Arsitektur berlapis yang diminta sudah dipakai di sana — transport AT terpisah dari
protokol — dan kini diterapkan di lapisan web firmware uji.

### Bisakah LCD menampilkan HTML?

**Panel ESP32-S3 + LVGL: tidak.** Tidak ada mesin browser; LVGL menggambar widget sendiri,
jadi seluruh tampilan harus ditulis ulang dalam C.

**HMI Android: ya.** WebView menampilkan dashboard yang sudah ada **tanpa ditulis ulang**.
Itu argumen terkuat untuk jalur Android.

### Bisakah ESP32 berkomunikasi dengan payment gateway?

**Bisa secara teknis, dan jangan dilakukan.** API payment gateway diautentikasi dengan
*server key*. Kunci yang disimpan di perangkat dalam mobil bisa dibaca dari flash, dan siapa
pun yang memilikinya bisa membuat transaksi atau refund atas nama BMT.

Susunan yang benar: **perangkat → server TDS → payment gateway.** Server memegang kunci dan
membuat QRIS dinamis; perangkat hanya menampilkan QR dan menerima status "sudah dibayar" dari
server. Webhook dari gateway juga harus diterima server publik — perangkat di kendaraan tidak
bisa menerimanya. Pembayaran kartu butuh perangkat bersertifikasi, bukan rakitan.

### HMI Android yang kompatibel dengan ESP32

Ada kategori produk yang namanya persis sama dengan proyek ini: **MDT Android untuk armada**.

| Produk | Yang relevan |
|---|---|
| [Waysion V7S](https://www.waysion.com/v7s-rugged-android-tablet/) | Android 14, **9–36 V DC**, **sensor ACC kontak**, RS232, RS485, dual CAN, IP65 |
| [Topicon MDT765](https://www.topicon.hk/products-detail/en/mobile-data-terminal-mdt765.html) | MDT 7" untuk bus/truk, RS232, IP67 |
| [PaceBlade MDT-770](https://www.paceblade.eu/paceblade-mdt-770) | 7", input 12 V, NFC, WiFi ac |
| [K71 (Kcosit)](https://www.kcosit.com/In-Vehicle-Tablet-Fleet-Management-p4243217.html) | i.MX 8M Mini, 1280×800, RS232, CAN, IP67 |
| [DWIN DMG12800T070_34WTC](https://www.dwin-global.com/7-inch-android-intelligent-display-model-dmg12800t070-34wtc-product/) | layar pintar Android 7" industri, dari produsen layar serial |

Panel industri umum seperti [Geekland 7" Android](https://geekland.co/product/7-android-poe-industrial-panel-pc-hmi-with-rs232-485/)
juga ada, tapi dirancang untuk dinding dengan PoE — bukan untuk catu daya kendaraan.

**Cara menyambungkannya ke ESP32:**

- **WiFi** — paling sederhana. MDT membuka dashboard perangkat di WebView. Nol kode baru.
- **RS232** — **jangan disambung langsung ke GPIO ESP32.** RS232 berayun ±12 V; ESP32 hanya
  tahan 3,3 V. Wajib lewat transceiver seperti MAX3232.
- **RS485** — lewat transceiver 3,3 V seperti SP3485.

Sensor ACC kontak di kelas produk ini sekaligus menjawab temuan F-15 (kuras aki saat
parkir): layar ikut mati bersama kunci kontak.

**Ini membuka ulang D-005** di `project-mdt-tds`, yang mengunci panel ESP32-S3 + LVGL.
Keputusannya ada di CEO. Rekomendasi saya: arah CEO — HTML, HMI Android, pembayaran —
lebih cocok dengan MDT Android daripada panel LVGL. Harganya lebih mahal per unit, tetapi
memberi tampilan HTML tanpa tulis ulang, catu 9–36 V, sensor kontak, IP65, dan 4G/GPS/NFC
bawaan. Satu syarat tetap berlaku: **perekam CAN tetap perangkat terpisah** (D-001),
walaupun MDT-nya punya port CAN sendiri — jaminan listen-only hidup di perekam.

---

## 5. Rencana dua minggu

| Minggu | Pekerjaan | Selesai kalau |
|---|---|---|
| 1 | Flash firmware fase 2; verifikasi di bench | Health = Healthy dengan dashboard terbuka; `Frames lost by driver` tetap 0 |
| 1 | Tarik capture HR-V lama dari flash, konversi, jalankan survei skill | daftar ID dengan pencacah/checksum teridentifikasi |
| 1 | Cari odometer 69620 km di capture penuh | ketemu, atau tercatat "tidak ada di bus pin 6/14" |
| 2 | Run terkendali HR-V sesuai `docs/RUN-PROCEDURE.md`, **dengan video kluster** | capture + video + catatan per ID terkumpul |
| 2 | Korelasi kecepatan dan RPM lewat mode VISION skill | kandidat sinyal dengan start bit, panjang, skala, offset |
| 2 | Keputusan CEO: MDT Android atau panel ESP32-S3 | dicatat sebagai keputusan di `project-mdt-tds` |

Yang **tidak** ada di rencana ini: memasukkan ID apa pun ke `signals.cfg` armada. Kandidat
dari HR-V adalah hipotesis tentang Honda sampai divalidasi terhadap rujukan independen, dan
armada bukan Honda.

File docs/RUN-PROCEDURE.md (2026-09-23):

# Capture run procedure — CAN bring-up

Applies to the diagnostic firmware in this repository, listen-only, on any vehicle
whose CAN bus is confirmed present at OBD-II pins 6 and 14 (60 ohm across them).

This is a PER-VEHICLE procedure, and it repeats. Every new vehicle type gets its own
run, its own UNIT_ID, and its own signal profile. Nothing carries across: an identifier
decoded on one vehicle means nothing on another.

Written after the first successful bus contact on a Honda HR-V 2023,
8 September 2026: 40 identifiers, 900–1,282 frames/s, 0 dropped, 0 missed.

---

## 1. Why this is scripted, and not just a drive

A recording of somebody driving normally is close to useless. Forty identifiers
change at once, every byte moves, and nothing in the file says which change
belongs to which cause. You end up with a large correlated mess.

What makes a capture analysable is the opposite: **one thing changes, everything
else stays still, and you know exactly when.** Blueprint §9.1's known-value
method needs a value you can state with certainty and a window in which it was
true. The whole procedure below exists to manufacture those windows.

Three rules follow from that, and they matter more than the phase list:

1. **Separate every action with about ten seconds of doing nothing.** The quiet
   gap is what makes the changed bytes stand out from the counters.
2. **Hold values, do not sweep through them.** A speed held at 40 km/h for ten
   seconds is trivial to find. A speed sweeping past 40 km/h is not.
3. **Say what you are doing, out loud, on camera.** The video is the annotation
   track. Without it the capture is unlabelled data.

---

## 2. Clear these before the run

The run is wasted if any of these is still open.

- [ ] **Capture writer keeps up.** The Capture panel must NOT show *"Written is
      behind received"*, and `Dropped before writing` must read 0. Fixed on
      9 Sep 2026 (frames staged in a 4 KB buffer, queue 256 -> 1024), but
      **verify it on the actual bus before trusting it** — the fix has not yet
      met 1,300 frames/s in a vehicle.
- [ ] **The firmware was flashed with this vehicle's env** (`pio run -e gelora-e
      -t upload`, for example). The dashboard header shows the `UNIT_ID`; check it
      names the vehicle in front of you before the run starts, never after
      (D-015). It goes into every capture header and selects the notes folder.
- [ ] **Flash has room for the run.** Since 22 Sep a new boot continues after
      the highest existing segment instead of reopening `can-000`, and capture
      stops cleanly when the flash runs out instead of failing mid-write. So old
      files no longer corrupt a new run, but they still take its space: the
      HR-V run of 8 Sep filled 8.8 MB in 3.4 min (about 43 kB/s). Once the old
      captures are archived off the laptop too, run `clearcaptures` on the
      serial console. The capture budget is logged at boot.
- [ ] **Old captures archived and verified.** The HR-V run was pulled on 20 Sep
      (`docs/evidence/honda-hrv-2023/hrv-001.md`): 34 files, all 34 SHA-256 digests matched the
      device. Pull with `tools/fetch_captures.py` over WiFi. **Never through the
      serial console** — it corrupted a first attempt, returning files larger than
      the originals, padded with zero bytes.
- [ ] **Vehicle change is logged** in `03-DECISIONS-LOG.md` and accepted by the
      Project Leader. The Avanza 2009 has no CAN at OBD-II (pins 6↔14 measured
      open, drifting ~22.5 kΩ); the test vehicle is now a Honda HR-V 2023.
- [ ] **Battery/power for the device** is sorted for the full run length.

### GNSS is currently unavailable

The module streams valid NMEA but hears no satellites — `Sky: in view / heard`
reads `0 / 0`. That is the antenna, and it means **the vehicle's own speed
signal has no independent reference on board**, which is exactly what §9.1 asks
for.

Substitute for it, do not skip it:

- Run a **GPS logger app on a second phone**, exporting timestamped speed.
- And/or **film the instrument cluster**, which gives speed, tachometer,
  odometer and fuel on one synchronised track.

Filming the cluster is the stronger of the two and is required regardless.

**And the video is now machine-readable.** The `cansub-reverse-engineering` skill
installed on 9 Sep 2026 has a VISION mode that OCRs an instrument-cluster video into a
reference series, then correlates it against the CAN log to find the ID, start bit,
length, endianness, scale and offset. That turns the cluster video from an annotation
track a human reads into the reference signal the search runs against — which matters
more than usual while the GNSS antenna is dead. Frame the cluster so the speedometer
digits are legible and stay in frame; a shaky or glare-washed video costs the whole run.

---

## 3. People, and why two are needed

| Role | Does |
|---|---|
| **Driver** | Drives. Nothing else. Does not touch the phone. |
| **Operator** | Films the cluster, calls each action aloud, watches the dashboard, keeps the run sheet. |

Do not attempt this alone. Phases A–D can be done stationary by one person;
phase E cannot.

**Equipment:** device powered and connected to the phone hotspot; dashboard open
on the operator's phone; a second phone filming the instrument cluster; a written
run sheet; a pen.

---

## 4. The sync marker — do this first, every run

The capture timestamps are `millis()` since boot. The video is wall clock. They
have to be tied together or the annotation cannot be applied.

**With the camera already rolling and pointed at the cluster:**

> Press the brake pedal five times, fast and distinctly.

That produces an unmistakable five-pulse signature in the data and an
unmistakable five-flash of the brake lamp on the video. It is the clapperboard.
Every later timestamp is measured from it.

Say the wall-clock time aloud as you do it.

---

## 5. Phases

Announce each action aloud before doing it. Wait the stated gap afterwards.

### A — Resting baseline. Ignition ON, engine OFF. 60 s.

Do **absolutely nothing**. No touching anything.

This is the most valuable minute of the run and the easiest to skip. Everything
that changes here changes on its own: heartbeats, rolling counters, alive
signals. Later, anything that moved during phase A can be **ruled out** as a
candidate for a signal you care about. Without this you will chase counters for
hours.

### B — Isolated discrete actions. Engine OFF. 10 s gap after each.

Each of these flips one thing, and is trivial to spot in a diff:

1. Steering wheel fully left → return to centre
2. Steering wheel fully right → return to centre
3. Brake pedal: three distinct presses
4. Headlights on → off
5. Left indicator on → off
6. Right indicator on → off
7. Driver door open → close
8. Driver seatbelt unbuckle → buckle
9. Parking brake engage → release

### C — Engine start. Idle, stationary. 60 s.

Start the engine and leave it idling, untouched.

Expect new identifiers to appear and the identifier count to rise. Note the new
count on the run sheet.

### D — Throttle without motion. Transmission in P or N. 10 s gap after each.

1. Raise to ~2,000 rpm, hold 5 s, release
2. Raise to ~3,000 rpm, hold 5 s, release
3. Raise to ~4,000 rpm, hold 5 s, release

Read the tachometer aloud at each hold. RPM is an analogue value you can state
precisely, the vehicle is not moving, and almost nothing else is changing — the
best conditions in the whole run for solving a 16-bit scaled field.

### E — Speed plateaus. On a quiet road. This is the core of the run.

Hold each speed steady for a full **10 seconds** and call it aloud.

| Step | Target | Hold |
|---|---|---|
| 1 | 20 km/h | 10 s |
| 2 | 0 (stopped) | 10 s |
| 3 | 40 km/h | 10 s |
| 4 | 0 (stopped) | 10 s |
| 5 | 60 km/h | 10 s |
| 6 | 0 (stopped) | 10 s |

Three separate plateaus is deliberate. Two known points are the minimum needed
to solve a candidate for both scale and offset; the third one checks the answer
rather than fitting it. Stopping fully between them gives a clean zero, which
pins the offset directly.

If the road allows only lower speeds, use 20 / 30 / 40. Spacing matters more
than the absolute numbers.

### F — Odometer leg.

1. Photograph the odometer. Read it aloud.
2. Drive a measured distance — 2 km is what §9.1 suggests.
3. Stop. Photograph the odometer again. Read it aloud.

The before and after readings are two known values of the same field, taken far
enough apart that no counter can imitate the difference.

### G — Close out.

1. Engine off, ignition off, camera still rolling for 10 s.
2. Stop the video.
3. Note the final frame count, identifier count, dropped, missed and bus errors
   from the dashboard, and photograph that panel.
4. Pull the capture file off the device before powering down.

---

## 6. Evidence handling

Per D-015: **raw evidence is not edited after a test, and failures are never
deleted.** A run that went wrong is still evidence — it is labelled as such, not
discarded.

Each run gets its own directory under `docs/evidence/`:

```
docs/evidence/RUN-00N/
  serial-log.txt        raw, immutable
  can-0NN.log           the capture pulled off flash
  cluster.mp4           the instrument-cluster video
  gps-track.gpx         phone GPS log, if used
  run-sheet.md          times, actions, observed values
  dashboard-end.jpg     final counters
  NOTES.md              engineer interpretation — SEPARATE from the raw files
```

**Raw evidence ≠ engineer interpretation.** Interpretation goes in `NOTES.md`
and nowhere else.

The device restarted between the two photographs taken on 8 September — the
identifier counts decreased, which only a reboot can do. Those are therefore two
separate runs, not one, and must be recorded as such.

### Run sheet template

```
RUN-00N   vehicle: Honda HR-V 2023   date: ____  start (wall clock): ____
device UNIT_ID: ______   firmware: ______   bitrate: 500 kbps

sync marker (5 brake presses) at wall clock: ______

phase  t+      action                          observed value
A      00:00   resting baseline, 60 s          IDs seen: ___
B      01:00   steering full left              -
B      01:15   steering full right             -
...
D      __:__   hold 2000 rpm                   tacho reads: ____
E      __:__   hold 20 km/h                    speedo reads: ____
F      __:__   odometer before                 ____ km
F      __:__   odometer after                  ____ km

end: received ____  identifiers ____  dropped ____  missed ____  bus errors ____
capture file: ____  size ____  written vs received: ____
```

---

## 7. After the run

Order matters — §9.1 puts speed first, because it is the only signal with an
independent reference, and a correct speed decode simultaneously proves the
wiring and the bitrate.

1. **Speed**, using the phase E plateaus. Search for the plateau values.
   Cross-check against the video and the phone GPS track.
2. **RPM**, using the phase D holds.
3. **Odometer**, using `tools/match_dashboard.py` with the phase F readings. It
   tries every byte position, width, endianness and 12-bit field across all
   identifiers at once:

   ```
   python tools/match_dashboard.py captures/<run> --value <km on the cluster>        --scales 1 0.1 0.01 --label "odometer km"
   ```

   **Two candidates are already waiting for this run to confirm or kill them**
   (`docs/evidence/honda-hrv-2023/hrv-001-candidates.md`):

   | Candidate | Confirmed if |
   |---|---|
   | `0x294` bytes 3-5 big-endian = odometer km | it rises by exactly 2 over the 2 km leg |
   | `0x324` byte 0 minus 40 = outside temperature °C | it tracks the cluster between a cool morning and a hot afternoon |

   Both were matched against a stationary capture, where nothing moved. A field
   that merely held the right number proves nothing until it moves with it.
4. **Discrete signals** from phase B, by diffing the quiet gaps against the
   action windows.

A candidate is not a signal until it has been confirmed against a second,
independent observation. Until then it is a hypothesis.

**No identifier discovered here goes into the fleet `signals.cfg` without that
confirmation.** These are Honda identifiers on a test vehicle; the fleet is a
different platform entirely.

### Name the identifiers while you are in the car

The dashboard's identifier table carries an empty **Name** field immediately right
of each ID. Fill it in during the run, the moment something is noticed: "moves
with the brake pedal", "climbs with speed". Press Enter and it is stored on the
device, in `/notes/<UNIT_ID>/ids.tsv`, with every change journalled to
`/notes/<UNIT_ID>/journal.log`. Each vehicle has its own folder: a name typed
against `0x294` on the HR-V does not appear against `0x294` on another car.

Notes are deliberately kept out of the capture files (D-015): a note is what
somebody thinks an identifier is, the capture is what the bus actually said. A
wrong guess is corrected without touching the evidence.

### The live probe

The signal probe is flashed and live on the device, so a second short drive can
confirm a candidate in the car rather than at a desk: select the identifier, set the start
byte, width and byte order, and watch the number while the driver calls out the
speedometer. It samples rather than captures, so the file on flash remains the
record — but it turns a one-hour desk loop into a ten-second one.

---

---

## 7b. DFSK Gelora E: what is different about an electric van

Everything above still applies. These are the additions.

**Before connecting**

- **Flash the `gelora-e` env.** The header must read `GELORAE-TEST-01`.
- **Vehicle fully OFF, not READY**, when connecting and disconnecting. On an EV,
  "engine off" is not a state; READY is the equivalent of a running engine.
- **Never go near the orange high-voltage cabling.** The OBD-II port is on the
  12 V side and is all this test touches.
- **Measure pins 6-14 with the vehicle off**, as always: about 60 ohm means a bus
  is there. Also measure **3-11 and 12-13**, only with the meter. Some makes put
  a second CAN bus on those pins. This harness reads 6/14 only, but knowing a
  second bus exists changes what to try next.

**Bitrate**

**Measured on 22 Sep 2026: the Gelora E runs at 250 kbps**, so flash
`gelora-e-250k`. At 500 kbps it produced 1,579,745 bus errors in 378 s and not
one frame, which is exactly what the dashboard's "Wrong bitrate, most likely"
is there to catch. Its identifiers are all 29-bit extended, J1939-style.
Results: [`docs/evidence/dfsk-gelora-e/gelora-001.md`](evidence/dfsk-gelora-e/gelora-001.md).

**The OBD port may be silent, and that is a finding**

Many recent vehicles put a gateway between the OBD-II port and the internal
buses, and the gateway only answers a diagnostic request. This device never
sends one: it is listen-only, permanently. If the port is silent with the
vehicle READY, record the silence with photos and the 6-14 resistance, and stop.
Do not look for a way to make the device transmit.

**What to film on the cluster, beyond the odometer**

An EV cluster carries the signals the fleet actually needs, which the HR-V
could not show:

| Reading | Why it matters |
|---|---|
| **Battery %** (SoC) | first in the fleet's signal order (Speed, SoC, Odometer, Ignition) |
| Range estimate, km | moves with SoC; a second reference for it |
| **READY** lamp, gear P/R/N/D | the EV equivalent of ignition |
| Speed | the only signal with a GNSS cross-check, once the antenna works |
| Power / regen gauge, if shown | a signed value: negative while regenerating |

Film the cluster for the **whole** run, starting with the sync marker (§4).
Without that video every candidate stays a guess.

**This is still not the fleet vehicle.** The fleet runs Wuling EVs. Whatever is
found on the Gelora E is a fact about DFSK, and goes nowhere near the fleet
`signals.cfg`.

## 8. Safety

- The device is **listen-only**, enforced three ways and verified by
  `tools/check_listen_only.sh` on every build. It cannot transmit to the bus.
- The **driver drives**. Phone, dashboard and run sheet belong to the operator.
- Phases A–D belong in a stationary parking space. Only phase E and F need road.
- Route the OBD-II cable so it cannot reach the pedals.
- Abort the run rather than chase a number. The capture can be repeated; the
  vehicle and the people in it cannot.

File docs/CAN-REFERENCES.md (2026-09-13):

# Rujukan CAN, dan apa yang berubah karenanya

Sumber: masukan rekan-rekan BMT, 8–9 September 2026, setelah sesi bring-up pertama.
Berkas mentahnya di `feedback/`.

Berkas ini bukan daftar tautan. Bagian yang penting adalah kolom terakhir setiap tabel:
**apa yang berubah di kode kita**. Rujukan yang tidak mengubah apa pun dicatat sebagai
rujukan saja, dan dikatakan begitu.

---

## 1. Dekode bus

| Rujukan | Isi | Untuk kita |
|---|---|---|
| [opendbc](https://github.com/commaai/opendbc) | kumpulan DBC + parser + API per merek | rujukan utama bentuk akhir; **tidak ada Wuling/SGMW** |
| [cantools](https://github.com/eerimoq/cantools) | parse DBC, decode frame jadi nilai fisik | dipakai di laptop untuk validasi sebelum logika masuk firmware |
| [awesome-automotive-can-id](https://github.com/iDoka/awesome-automotive-can-id) | indeks CAN ID + payload per merek | **Wuling, Baojun, SGMW belum ada di daftarnya** |
| [awesome-canbus](https://github.com/iDoka/awesome-canbus) | indeks tool, hardware, dokumentasi format DBC | rujukan |

**Konsekuensi yang harus disadari sejak sekarang.** Kalau armada Baswara berbasis Wuling
atau SGMW, tidak ada DBC rujukan yang bisa dipinjam. Kita membangunnya dari nol, dan
itu bukan kemunduran — hanya perlu masuk perkiraan waktu sejak awal, bukan ditemukan di
tengah jalan.

## 2. Membongkar sendiri

[can-bus-reverse-engineering-skills](https://github.com/CSS-Electronics/can-bus-reverse-engineering-skills)
(CSS Electronics, MIT) — alur kerja dari log CAN mentah ke DBC: cari CAN ID, start bit,
panjang, endianness, scale, offset, lalu verifikasi.

**Sudah dipasang sebagai skill Claude** di mesin ini, 9 Sep 2026, tiga skill:
`cansub-knowledge`, `cansub-reverse-engineering`, `combine-dbc`.

Tiga mode kerjanya, dan yang ketiga mengubah nilai prosedur run kita:

- **OFFLINE** — decode dari log yang sudah ada, memakai rujukan yang bisa didekode
  terpisah: PID OBD-II, atau kecepatan GNSS.
- **LIVE** — tangkap dari antarmuka CANsub dengan rujukan yang disuplai manusia.
- **VISION** — log CAN plus **video panel instrumen**, lalu skrip OCR lokal mengubah
  angka di layar jadi deret rujukan.

Mode VISION itu penting. `docs/RUN-PROCEDURE.md` sudah mewajibkan merekam video kluster
instrumen sebagai trek anotasi yang dibaca manusia. Ternyata video itu bisa dibaca mesin
juga, dan berubah dari catatan pendukung menjadi **sumber rujukan utama** — terutama
selagi antena GNSS mati dan kecepatan belum punya pembanding independen di perangkat.

Alurnya sejalan dengan `docs/RUN-PROCEDURE.md` dan dengan `tools/can_find_value.py`.

## 3. Kasus Wuling / SGMW

| Rujukan | Catatan |
|---|---|
| [opendbc-byd](https://github.com/BYDcar/opendbc-byd) | bukan Wuling, tapi contoh bentuk akhir yang dituju |
| [Utas XDA Wuling/Baojun/MG/SGMW](https://xdaforums.com/t/hacking-wip-wuling-baojun-mg-sgmw-vehicles.4714034/) | fokus head unit Android, bukan DBC — komunitas terdekat yang ada |

**Catatan penulis opendbc-byd yang layak dijadikan ekspektasi:** replay `candump` tidak
direspons kendaraan, kemungkinan port OBD-II difilter.

Itu sejalan dengan temuan kita sendiri pada Avanza 2009: pin 6↔14 terukur terbuka
(~22,5 kΩ, merayap), tidak ada CAN di OBD-II sama sekali. **Port OBD-II bukan jaminan
akses ke bus internal**, dan itu berlaku baik untuk membaca maupun menulis.

---

## 4. Jebakan decoding — dan status kita di masing-masing

Ini bagian yang paling berharga dari seluruh masukan. Tabelnya dibaca sebagai daftar
periksa, bukan bacaan.

| Jebakan | Isi | Status kita |
|---|---|---|
| **Byte order** | keliru Intel lawan Motorola menghasilkan angka yang **terlihat masuk akal tapi salah**, bukan crash | probe punya pilihan big/little-endian ✓ |
| **Signed value** | two's complement; dibaca unsigned, −5 jadi 251 | probe punya kotak centang `signed` ✓ |
| **Multiplexed signal** | satu CAN ID membawa isi berbeda tergantung nilai byte multiplexor | **BELUM DITANGANI** — lihat di bawah |
| **Timestamp** | ambil saat frame diterima kernel, bukan saat JSON sampai di browser | `rx_millis` diambil di task penerima ✓ |
| **Rate** | mendorong ribuan frame/detik ke WebSocket membekukan tab; agregasi di gateway, 10–30 Hz untuk tampilan, full-rate ke disk | halaman polling 2 Hz, kirim 60 frame terakhir; full-rate ke flash ✓ |
| **Keamanan** | CAN tanpa autentikasi; kalau gateway bisa menulis, siapa pun yang menembus web app bisa menulis ke bus | listen-only tiga lapis + gate build ✓, **pemutusan TX fisik belum** (F-13) |

### Byte order: kita sudah pernah kena kelas cacat ini

"Angka yang terlihat masuk akal tapi salah, bukan crash" persis menggambarkan bug DHT22
pada 9 Sep 2026: frame `04 E0 02 73 59` **lolos checksum** dan terbaca 124,0 %RH serta
62,9 °C, karena tertangkap tergeser satu bit.

Pelajarannya sama untuk CAN: **pemeriksaan struktural yang lolos tidak membuktikan
penafsirannya benar.** Kandidat sinyal butuh pemeriksaan kewajaran yang terpisah dari
pemeriksaan integritas, dan validasi terhadap pengamatan independen.

### Multiplexed signal: celah nyata di pengintai sinyal

Pengintai sinyal di dashboard mengasumsikan satu CAN ID selalu membawa tata letak yang
sama. Kalau ID yang diintai ternyata multiplexed, angkanya akan **berubah-ubah tanpa pola
yang masuk akal** — dan itu akan terbaca sebagai "byte ini bukan sinyalnya", padahal
sinyalnya ada dan cuma muncul saat byte multiplexor bernilai tertentu.

Gejala yang membedakan: nilai melompat antara beberapa rentang yang berbeda jauh, bukan
bergerak halus. Kalau itu terlihat, curigai multiplexing dan pindah ke `cantools` di
laptop — parser manual umumnya tidak menanganinya.

Belum diperbaiki. Dicatat supaya tidak salah didiagnosis saat muncul.

---

## 5. Bentuk sistem: decode sekali di gateway

Prinsip dari masukan yang sama, dan ini mengikat rancangan MDT-TDS:

> Browser tidak punya akses ke CAN, dan tidak akan pernah punya. Polanya selalu: gateway
> membaca frame, mengubahnya jadi JSON, lalu mendorongnya. Klien web dan Flutter cuma dua
> ujung yang identik.

Dan peringatan yang menyertainya: **jangan menduplikasi decoding DBC di klien.** Decode
sekali di gateway, sisakan klien sebagai penerima. Mem-parsing bit di dua bahasa berarti
dua tempat untuk salah membaca byte order, dan bugnya tidak akan muncul sampai ada sinyal
Motorola.

Yang dikirim ke klien adalah nilai yang sudah jadi:

```json
{"ts": 1757310000.412, "msg": "EngineData", "sig": {"rpm": 1520.5, "coolant": 87}}
```

Hex mentah disimpan untuk satu tampilan debug terpisah, bukan dijadikan format utama.

**Berlaku langsung untuk MDT:** panel ESP32-S3 tidak mendekode apa pun. Ia menerima nilai
jadi. Dicatat sebagai D-006 di `project-mdt-tds`.

**Koreksi 12 Sep 2026 (D-008 di `project-mdt-tds`):** untuk telemetri hidup, "gateway" di
sistem kita adalah **perangkat di kendaraan itu sendiri**, bukan server. Frame mentah sekitar
400 kali lebih besar daripada nilai terdekode dan tidak bisa dialirkan lewat seluler, jadi
perangkat mendekode memakai profil `signals.cfg` yang dihasilkan dari pustaka DBC di server,
sedangkan server mendekode frame mentah dari rekaman massal. Dua decoder itu dijaga uji
golden-file. Prinsip bahwa klien tidak mendekode tetap berlaku utuh.

---

## 6. Perangkat keras: Raspberry Pi + SocketCAN

Masukan menyebut Raspberry Pi plus SocketCAN sebagai yang paling umum di production
kecil, dengan `ip link set can0 up type can bitrate 500000`, lalu `candump` dan
`cansniffer`.

**Kita tidak pindah.** Alat yang ada sudah membaca 40 identifier pada 1.282 frame/detik
dengan nol dropped dan nol missed di kendaraan sungguhan. Tidak ada masalah yang
diselesaikan dengan berpindah platform, dan berpindah berarti membuang jaminan
listen-only yang sudah ditegakkan tiga lapis plus gate build.

Yang layak dipinjam bukan perangkat kerasnya melainkan perkakasnya: keluaran kita
sebaiknya bisa dikonversi ke format `candump` supaya `python-can`, `cantools`, dan
SavvyCAN bisa membacanya langsung.

Satu catatan operasional dari sana yang berlaku untuk kita juga: **bitrate salah membuat
interface masuk bus-off, dan keluarannya terlihat kosong — bukan error yang jelas.**
Persis kelas cacat yang sama dengan tabel identifier yang kehilangan 47 persen data tanpa
tanda apa pun.

---

## 7. Alat ini untuk banyak jenis kendaraan, bukan hanya Baswara

Arahan operator, 9 Sep 2026. Ini mengubah beberapa hal yang sebelumnya aman diasumsikan.

### Bitrate bukan lagi konstanta yang bisa diabaikan

`CAN_DEFAULT_BITRATE` ditetapkan saat kompilasi, dengan komentar di `Config.h` yang
berbunyi *"Decide on the bench, flash once."* Itu masuk akal untuk satu armada. Untuk alat
yang akan bertemu banyak kendaraan, ia jadi jebakan: kebanyakan mobil 500 kbps, tetapi
banyak kendaraan lama dan bus bodi memakai 250 kbps.

**Yang sudah diperbaiki (9 Sep 2026):** dashboard kini membedakan keduanya. Bus error yang
naik sementara tidak ada frame yang terdekode adalah tanda khas **bitrate salah** —
controller mendengar transisi yang tidak bisa ia bingkai. Nol frame dengan nol bus error
berarti tidak ada yang tersambung. Sebelum ini keduanya terbaca sama persis: *"No frames
yet"*, dan kendaraan 250 kbps tampak identik dengan konektor yang tidak dicolok.

**Yang belum diputuskan:** apakah bitrate boleh diganti saat berjalan, atau tetap
flash-per-kendaraan. Komentar di `Config.h` melarang penggantian runtime dengan alasan
yang belum saya verifikasi. Ini keputusan, bukan pekerjaan — jangan diubah sepihak.

### Identifikasi kendaraan tanpa melanggar listen-only

Alat multi-kendaraan harus tahu ia sedang menempel di kendaraan apa, supaya profil sinyal
yang benar dipakai. Tiga jalan, dan hanya dua yang boleh:

| Cara | Bisa dipakai? |
|---|---|
| Ditetapkan manual per unit (`UNIT_ID` + profil) | ya, sudah ada sebagian |
| **Sidik jari CAN** — himpunan identifier dan DLC yang terlihat | ya, dan **pasif** |
| Baca VIN lewat OBD-II | **tidak** — butuh mengirim request, melanggar listen-only |

Sidik jari CAN adalah cara openpilot mengenali kendaraan, dan cocok sempurna dengan alat
yang hanya mendengar: himpunan identifier pada sebuah bus cukup khas untuk membedakan
model. Kita sudah merekam himpunan itu — `unique_ids_seen` beserta tabel identifier —
jadi bahannya ada, tinggal disimpan sebagai profil.

### Prosedur run jadi berulang, bukan sekali

`docs/RUN-PROCEDURE.md` ditulis untuk satu kendaraan uji. Dengan cakupan baru, ia menjadi
**prosedur per kendaraan**: setiap jenis kendaraan baru butuh run-nya sendiri, dengan
`UNIT_ID` dan header capture yang menyebut kendaraan itu, dan hasilnya jadi profil
tersendiri.

### Satu risiko yang sekarang punya nama

Identifier dari satu kendaraan **tidak boleh bocor ke profil kendaraan lain**. `0x1A6` di
Honda HR-V tidak berarti apa-apa di Wuling. Aturan lama berbunyi "jangan mengarang CAN
ID"; aturan itu sekarang bertambah: **jangan memakai ulang ID lintas kendaraan.** Setiap
profil berdiri sendiri sampai divalidasi sendiri.

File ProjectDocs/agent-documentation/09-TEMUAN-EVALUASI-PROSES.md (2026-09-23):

# 09: Temuan dan evaluasi proses

Diisi **saat temuan muncul**, bukan di akhir project.

**Aturan penanda panen.** Tiap entri baru diakhiri `[belum dipanen]`. Penanda itu antrean,
bukan hiasan: panen mengubahnya jadi `[dipanen -> <tujuan>, YYYY-MM-DD]` setelah rutenya
selesai. Isi entri **tidak pernah disunting** saat ditandai, penanda hanya ditambahkan.

---

## A. Temuan proses

**A-1. Bug yang hanya muncul di kendaraan sungguhan.** Aliran frame lewat WiFi lolos
seluruh pengujian di meja, lalu membuat alat reboot detik itu juga saat bus kendaraan
ramai. Penyebabnya dua tugas memindahkan buffer yang sama. Di meja bus terlalu sepi untuk
memunculkannya. Pelajarannya: untuk kode yang menyentuh jalur akuisisi, pengujian di meja
adalah penyaring, bukan bukti. `[belum dipanen]`

**A-2. Penghitung yang tidak bisa menunjukkan kegagalan yang seharusnya ia tangkap.**
Layar perekam di laptop menampilkan "drops 0" sepanjang satu sesi yang sebenarnya
kehilangan 3.090 frame, karena penghitung itu hanya melihat putus sambungan di sisi
laptop. Pelajarannya: setiap penghitung harus diuji dengan pertanyaan "kalau hal yang
ingin kutangkap terjadi, apakah angka ini bergerak?" `[belum dipanen]`

**A-3. Bukti lebih kuat kalau tidak melibatkan manusia.** Satuan kecepatan diputuskan
dengan mengadu kecepatan terhadap odometer di bus yang sama, dan itu selesai dalam satu
perhitungan. Dua puluh tiga laporan kecepatan yang diketik pengemudi sambil menyetir
hanya mencapai korelasi 0,72 dan tidak memutuskan apa pun. `[belum dipanen]`

**A-4. Rujukan keputusan tanpa nama repositori.** Tiga repo BMT masing-masing punya deret
`D-XXX`, dan `D-006` sudah berarti dua hal berbeda. Rujukan di dalam kode repo ini
sebagian besar menyebut nomor telanjang. Aturannya sudah ditulis di `03-DECISIONS-LOG.md`,
tetapi rujukan lama belum diperbaiki. `[belum dipanen]`

**A-5. Prosedur yang lahir dari kesalahan lebih berguna daripada prosedur yang lahir dari
bayangan.** `docs/PROSEDUR-TEST-JALAN.md` ditulis sebelum uji jalan, lalu dua butir
termahalnya justru ditambahkan **setelah** uji jalan, yaitu jarak laptop dan cara merekam
referensi kecepatan. Keduanya tidak terbayangkan sebelum dialami. `[belum dipanen]`

**A-6. Rekaman yang ada tetapi tidak pernah didokumentasikan.** `gelora-002` dan
`gelora-003`, masing-masing 216.454 dan 200.389 frame dari 22 September malam, tersimpan
di `captures/` tanpa satu pun dokumen bukti. Sebagian angkanya sudah dipakai di
`frame-loss.md`, jadi rekaman itu **bukan sampah**, hanya tidak punya jejak. Baru
ketahuan saat mengarsipkan dokumentasi per kendaraan. Pelajarannya: menghitung berkas di
`captures/` lawan dokumen di `docs/evidence/` adalah pemeriksaan murah yang menangkap
hutang semacam ini. `[belum dipanen]`

## B. Temuan teknis

**B-1. Interupsi CAN di flash.** `CONFIG_TWAI_ISR_IN_IRAM is not set` pada arduino-esp32
2.0.17 membuat setiap penulisan flash mematikan cache instruksi dan controller kehilangan
frame. Terukur 14,8 % melawan 0,0 %. Ini sifat framework, bukan bug kode, dan berlaku
untuk project ESP32 mana pun yang menulis flash sambil menerima CAN. `[belum dipanen]`

**B-2. `WiFiClient::availableForWrite()` tidak pernah diimplementasikan di ESP32.** Ia
mewarisi nilai 0 dari kelas `Print`, sehingga kode yang menunggunya tidak akan pernah
mengirim apa pun. Jalan keluarnya `::send(fd, ..., MSG_DONTWAIT)` langsung.
`[belum dipanen]`

**B-3. `ENOMEM` dari lwIP berarti "coba lagi", bukan "sambungan mati".** Memperlakukannya
sebagai fatal membuat alat menyambung ulang 338 kali dalam 30 detik dan kehilangan
sekitar 40 % bus, sementara penghitung drop ikut nol setiap sambungan baru. Hanya `EPIPE`,
`ECONNRESET`, `ENOTCONN`, dan `EBADF` yang benar-benar mengakhiri sesi. `[belum dipanen]`

**B-4. Transfer berkas lewat serial merusak data secara diam-diam.** Percobaan menarik
rekaman lewat `cat` di serial menghasilkan berkas yang lebih besar dari aslinya, berisi
deretan NUL dan baris yang terduplikasi separuh. HTTP lewat WiFi tidak bermasalah.
Berkas rusak itu sengaja disimpan sebagai bukti. `[belum dipanen]`

**B-5. `.gitignore` yang menyebut pola berkas, bukan folder.** `captures/*.log` membuat
8,8 MB bukti nyaris ikut ter-commit karena berkas lain di folder itu tidak tercakup.
`captures/**` dengan pengecualian eksplisit untuk lembar run adalah bentuk yang benar.
`[belum dipanen]`

## C. Cara melapor

**C-1. Menyatakan lubang di muka membuat sisanya bisa dipercaya.**
`docs/evidence/dfsk-gelora-e/gelora-004.md` menempatkan "14,9 % waktu tidak terekam" di bagian atas,
sebelum satu pun temuan disajikan, dan menjelaskan kenapa tiap bukti tetap tahan terhadap
lubang itu. Laporan yang menyembunyikan kelemahannya sendiri tidak bernilai.
`[belum dipanen]`

**C-2. Menurunkan status sebuah temuan adalah bagian dari laporan, bukan aib.** Suhu
controller naik jadi kandidat saat kendaraan diam, lalu diturunkan kembali jadi dugaan
setelah 47 menit berkendara tidak mengubahnya. Penurunan itu ditulis sejelas
kenaikannya. `[belum dipanen]`

## D. Yang sudah bekerja baik

**D-1. Penegakan aturan oleh mesin, bukan oleh prosa.** Gate listen-only menggagalkan
build, bukan menegur. Dalam tiga sesi kendaraan, aturan itu tidak pernah sekali pun
terlanggar. `[belum dipanen]`

**D-2. Satu sumber kebenaran untuk skematik.** `hardware/gen_schematic.py` membangkitkan
skematik, netlist, dan BOM dari satu berkas data, lalu `verify_schematic.py` membaca
hasilnya kembali dengan parser terpisah dan memeriksa 12 aturan keselamatan. Diuji dengan
tiga cacat yang sengaja disuntikkan, ketiganya tertangkap. `[belum dipanen]`

**D-3. Bukti terpisah dari tafsiran.** Aturan D-015 repo armada terbukti berharga saat
sebuah tafsiran harus dikoreksi: rekaman tidak perlu disentuh sama sekali.
`[belum dipanen]`

## E. Usulan untuk project berikutnya

**E-1. Slot microSD sejak papan pertama.** Menulis ke SD lewat SPI tidak mematikan cache
instruksi. Itu menyelesaikan kehilangan frame dan batas 12 MB sekaligus, tanpa menyentuh
framework. Rev A belum difabrikasi, jadi masih sempat. `[belum dipanen]`

**E-2. Rekam video panel instrumen sebagai referensi standar.** Sekali di awal, tunjukkan
jam laptop ke kamera supaya video dan rekaman bisa disejajarkan. Lebih murah daripada
orang kedua yang mengetik angka, dan jauh lebih akurat. `[belum dipanen]`

**E-3. Jadikan "adu dua sinyal di bus yang sama" sebagai kriteria penerimaan baku.**
Kecepatan melawan odometer memutuskan satuan tanpa referensi eksternal. Pola yang sama
berlaku di kendaraan lain: cari dua besaran yang secara fisika harus konsisten.
`[belum dipanen]`

## F. Catatan terbuka

**F-1. Token GitHub bocor ke keluaran terminal, 22 Sep 2026.** Kutip perintah yang keliru
di PowerShell membuat kredensial tercetak apa adanya. Token itu milik akun `wira97-tech`
dan harus dicabut di pengaturan akun. Jalur push sekarang memakai kredensial bernama dan
keluarannya disaring. Perlu dipastikan token lama benar-benar sudah dicabut.
`[belum dipanen]`

**F-2. Apakah alat ini perlu mendukung permintaan diagnostik?** Nilai seperti resistansi
isolasi tidak pernah disiarkan berkala, jadi alat ini tidak akan pernah melihatnya.
Menambah kemampuan meminta berarti **mengirim**, dan itu membatalkan jaminan yang membuat
alat ini boleh dipasang di kendaraan orang lain. Kalau memang dibutuhkan, tempatnya alat
kedua yang terpisah. `[belum dipanen]`

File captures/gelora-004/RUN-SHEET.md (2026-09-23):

# Lembar run gelora-004: uji kecepatan DFSK Gelora E

Tanggal: 23 Sep 2026
Alat: GELORAE-TEST-01, 250 kbps, listen-only, aliran WiFi ke laptop

## Sebelum berangkat (dari foto)

| | |
|---|---|
| Odometer | 30423 |
| SOC | 74,0 % |
| Tegangan pack | 350 V |
| Arus | 1 A (mentah 1001) |
| SOH | 97 % |
| Suhu baterai maks / min | 31 / 30 °C |
| Suhu controller | 26 °C |
| Sel tertinggi / terendah | 3911 / 3650 mV |
| Jam panel instrumen | 18:46 (tidak disetel) |
| Jam head unit | 14:18 |

## Tahapan

| Jam laptop | Tahap | Catatan |
|---|---|---|
| 14:27:41 – 14:28:07 | **penanda: rem 5 kali** | jendela pengamatan 25 detik |
| 14:34:41 – 14:35:53 | **20 km/jam ditahan** (panel 10–12 mph, ~16–19 km/jam) | |
| 14:35:53 – 14:36:54 | **berhenti penuh** (jendela nol) | |
|  | 40 km/jam ditahan |  |
|  | berhenti penuh |  |
|  | 60 km/jam ditahan |  |
|  | akselerasi kuat |  |
|  | pengereman regeneratif |  |
|  | jalan lurus 2 km |  |

## Kejadian selama run

- 14:44:14: alat sempat hilang dari jaringan, rekaman terputus lalu tersambung lagi. Uptime alat saat kembali: 1655 s.
- 14:46:47: mulai berhenti penuh kedua (jendela nol setelah sambungan pulih)
- 15:06:45: uji arus: mulai melaju dari nol, lalu melambat sendiri tanpa rem
- 14:56:05 – 14:58:35: pengemudi menyebutkan kecepatan lewat pesan tiap ~5 detik (`speed-ref.csv`)

## Hasil rekaman

| | |
|---|---|
| Rentang | 14:23:40 – 15:10:23, 46,7 menit |
| Frame tersimpan | 1.525.681, 34 identifier, rata-rata 544 frame/detik |
| Ukuran | 97 MB, `can-000.log` … `can-379.log` |
| Tautan putus | 30 kali lebih dari 1 detik, total 418 detik (**14,9 % waktu tidak terekam**) |
| Lubang terbesar | 15:07:04 selama 121 detik; 14:39:45 selama 118 detik |

Penyebab lubang: laptop terlalu jauh dari alat dan dari hotspot. Untuk run
berikutnya, dekatkan keduanya dan tutup dashboard di HP.

## Setelah berhenti (dari bus, bukan foto)

| | |
|---|---|
| Odometer | 30427 (naik 4 km; layar sempat terbaca 30426 saat masih berjalan) |
| SOC | 71,0 % (turun 3,0 poin) |
| Tegangan pack | 348 V, sempat melorot ke 333 V saat arus puncak |
| Arus | −36 A sampai +133 A sepanjang sesi |
| Suhu baterai maks / min | 32 / 30 °C |
| Suhu controller | 26 °C, **tidak berubah sama sekali** |
| Kecepatan tertinggi | 48 km/jam |
| Putaran motor tertinggi | 4143 rpm |

Analisisnya di [`docs/evidence/gelora-004.md`](../../docs/evidence/gelora-004.md).

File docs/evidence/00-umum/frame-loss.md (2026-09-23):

# Kenapa frame hilang saat merekam, dan apa yang bisa dilakukan

Temuan 22 September 2026, dari panel Health yang menyatakan **Overworked** pada
pengujian DFSK Gelora E.

## Angka yang terukur

Pada satu sesi berdurasi 948 detik di bus 250 kbps yang mengalir sekitar 644
frame per detik:

| | |
|---|---|
| Frame diterima | 578.035 |
| **Hilang: `rx_overrun`** (FIFO hardware meluap) | **31.548** |
| Hilang: `rx_missed` (antrean driver penuh) | 95 |
| Total hilang | 4,9 % dari seluruh frame di bus |
| Kehilangan saat flash menganggur, diukur 25 detik | **nol** |

Perbandingan penting: **99,7 % kehilangan berjenis `rx_overrun`**, bukan
`rx_missed`. Keduanya berbeda asal:

- `rx_missed` berarti tugas pembaca terlambat mengambil dari antrean driver.
  Diperbaiki dengan memperbesar antrean.
- `rx_overrun` berarti **rutin interupsi tidak sempat jalan sama sekali**,
  sehingga FIFO di dalam controller CAN meluap. Memperbesar antrean software
  tidak menolong sedikit pun.

## Penyebabnya

Framework yang dipakai, arduino-esp32 2.0.17, dikirim dengan sdkconfig yang
memuat baris berikut:

```
# CONFIG_TWAI_ISR_IN_IRAM is not set
```

Artinya rutin interupsi TWAI berada di flash. Pada ESP32, setiap kali flash
ditulis atau dihapus, cache instruksi dimatikan, dan kode yang berada di flash
**tidak bisa dieksekusi** sampai operasi itu selesai. Rutin interupsi CAN ikut
berhenti. FIFO penerima di controller hanya menampung beberapa frame, jadi pada
644 frame per detik ia penuh dalam hitungan milidetik.

Jadi perekam ini melewatkan frame **justru ketika sedang merekam**, dan juga
saat berkas capture diunduh lewat WiFi, karena keduanya menyentuh flash yang
sama dengan tempat kode berada.

Bukti yang menguatkan: penghitung `loop ever` pernah mencatat jeda **1.727 ms**
pada tugas housekeeping, yang hanya masuk akal kalau seluruh inti tertahan oleh
operasi flash.

## Yang sudah dikerjakan

`CAN_RX_QUEUE_LEN` dinaikkan dari 64 ke 256. Ini hanya menghapus jenis
kehilangan yang kecil (95 frame), dan sengaja dilakukan karena murah: sekitar
8 KB heap dari 176 KB yang menganggur. **Ini bukan perbaikan untuk masalah
utamanya**, dan komentarnya di `Config.h` menyatakan hal itu.

## Terbukti: mengalirkan lewat WiFi menghapus kehilangan itu

Diuji 22 Sep 2026 pada kendaraan yang sama, bus mengalir sekitar 640 frame per
detik, dua fase berturut-turut masing-masing 30 detik:

| Fase | Frame diterima | Frame hilang | Rasio |
|---|---|---|---|
| Perangkat menulis ke flash sendiri | 16.627 | 2.898 | **14,8 %** |
| Dialirkan ke laptop lewat WiFi, penulisan flash dijeda | 19.337 | **0** | **0,0 %** |

Di laptop tersimpan 19.303 frame dari 19.332 yang dikirim perangkat. Sembilan
dibuang oleh perangkat karena buffer soket sempat penuh, dan sisanya masih di
jalan saat soket ditutup. Keduanya terhitung, bukan hilang diam-diam.

Ini juga menjelaskan kenapa angka 4,9 % sebelumnya lebih kecil: laju bus saat
itu lebih rendah. Semakin ramai bus, semakin besar bagian yang hilang.

**Karena penulisan flash itu sendiri penyebabnya, perekaman flash harus dijeda
selama mengalirkan.** `tools/stream_capture.py` melakukannya sendiri di awal
dan mengembalikannya di akhir, termasuk saat prosesnya dihentikan paksa.

## Diukur ulang di kendaraan yang hidup, 23 Sep 2026

Pengukuran sebelumnya membandingkan dua fase berturut-turut. Yang ini lebih
langsung: satu alat, satu kendaraan hidup, satu saklar ditekan, dan penghitung
yang sama dibaca sebelum dan sesudah.

| | Frame diterima | Overrun | Hilang |
|---|---|---|---|
| Merekam ke flash, 123 detik sejak boot | 67.828 | 11.573 | **14,6 %** |
| Perekaman dimatikan, 12 detik sesudahnya | 7.843 | 16 | **0,20 %** |

Tujuh puluh tiga kali lebih baik, dan yang berubah hanya satu saklar.

Sisa 0,20 % itu **belum dijelaskan**. Jumlahnya kecil dan tidak mengubah
kesimpulan, tetapi ia bukan nol, jadi jangan ditulis sebagai nol. Dugaan yang
belum diuji: metadata LittleFS, jurnal catatan, atau permintaan dashboard yang
kebetulan menyentuh flash.

### Kenapa pengukuran ini baru muncul sekarang

Karena cacatnya baru terlihat sekarang. Pilihan perekaman **tidak bertahan
melewati reboot**: perangkat selalu menyala dengan perekaman hidup, dan di
kendaraan reboot terjadi setiap kali kontak diputar. Saklar di dashboard
dibatalkan lebih cepat daripada sempat dipakai.

Operator BMT menemukannya dengan cara paling sederhana: melihat status masih
Overworked setelah saklar itu dimatikan. Diperbaiki dengan menyimpan pilihan
terakhir ke berkas dan membacanya saat boot.

## Pilihan perbaikan yang sebenarnya

| Pilihan | Efek | Biaya |
|---|---|---|
| **Kartu microSD** untuk capture | Menulis ke SD lewat SPI **tidak mematikan cache**, jadi interupsi CAN tetap jalan. Sekaligus menghapus batas 12 MB | Perlu slot SD di PCB. Masuk ke rev B |
| **Bangun ulang framework** dengan `CONFIG_TWAI_ISR_IN_IRAM=y` | Perbaikan tepat sasaran di akar masalah | Tidak bisa dengan paket Arduino siap pakai; perlu ESP-IDF dengan Arduino sebagai komponen |
| **Rekam dalam format biner**, bukan teks | Satu frame kini memakan sekitar 44 byte teks. Bentuk biner sekitar 17 byte, jadi lalu lintas flash turun 2,6 kali, dan jeda cache ikut turun sebanding | Perubahan format, konverter harus menyesuaikan |
| **Jangan mengunduh saat merekam** | Menghilangkan satu sumber jeda | Gratis, tinggal disiplin kerja |

Rekomendasi: **kartu microSD di PCB rev B**. Itu menyelesaikan kehilangan frame
dan batas kapasitas sekaligus, tanpa menyentuh framework.

## Sampai itu ada, ini yang berlaku

Rekaman dari alat ini adalah **sampel, bukan salinan lengkap bus**. Pada Gelora E
sekitar 5 % frame tidak tercatat; pada Honda HR-V yang busnya jauh lebih padat
(sekitar 1.000 frame per detik) kehilangannya 22 sampai 26 %.

Konsekuensinya berbeda menurut pemakaian:

- **Survei identifier, periode, dan pemetaan nilai**: tetap sah. Nilai yang
  disiarkan berkala akan muncul berkali-kali, jadi kehilangan sebagian tidak
  mengubah kesimpulan. Seluruh pemetaan `gelora-001` berdiri di atas ini.
- **Analisis yang bergantung pada urutan antar-frame**, misalnya pencacah
  bergulir, checksum, atau protokol multi-frame: **tidak bisa dipercaya**. Frame
  yang hilang di tengah tidak ditandai apa pun di berkas.

Panel Health menyatakan ini apa adanya: angka **Frames lost by driver** berisi
`rx_missed + rx_overrun` dalam satuan frame. Kalau ia tidak nol, rekaman yang
sedang berjalan sedang berlubang, dan itu harus dicatat di lembar run.

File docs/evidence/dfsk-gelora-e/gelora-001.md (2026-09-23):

# gelora-001: DFSK Gelora E, 22 Sep 2026

Rekaman pertama dari kendaraan listrik, dan pertama kali angka panel bisa
dicocokkan ke byte CAN dalam satu sesi yang sama.

## Asal-usul

| | |
|---|---|
| Kendaraan | DFSK Gelora E (van listrik) |
| Kondisi | mesin mati, kunci kontak ON, kendaraan diam sepanjang rekaman |
| Firmware | env `gelora-e-250k`, unit `GELORAE-TEST-01`, listen-only |
| Bitrate | **250 kbps** |
| Ditarik | 22 Sep 2026 lewat WiFi dari `10.215.81.4`, `tools/fetch_captures.py` |
| Berkas | `captures/gelora-001/can-000.log` … `can-052.log`, 194.219 frame |
| Keutuhan | ukuran tiap berkas cocok dengan yang dilaporkan alat, semua baris terbaca |

Rekaman berhenti sendiri saat mencapai batas 12 MB. Alat terus menerima frame
(608.917 saat terakhir dicek) tetapi tidak lagi menulis, persis seperti yang
dirancang setelah perbaikan 22 Sep. Tidak ada frame yang rusak karena flash penuh.

## Bitrate: 500 kbps salah, 250 kbps benar

Percobaan pertama di 500 kbps menghasilkan **1.579.745 bus error dalam 378 detik**
(sekitar 4.200 per detik) dan **nol frame**. Dashboard menyebutnya
"Wrong bitrate, most likely", dan itu tepat.

Setelah di-flash ke 250 kbps: 34 identifier, nol bus error.

Ribuan error itu tidak mengganggu mobil. Mode listen-only pada TWAI tidak pernah
mengirim bit dominan, termasuk error frame, jadi kesalahan bitrate hanya tercatat
di sisi alat.

## Bentuk bus

Semua 34 identifier memakai **29-bit extended**, bergaya J1939 seperti kendaraan
niaga, bukan 11-bit seperti mobil penumpang. Byte terakhir ID adalah alamat
sumber: terlihat ECU `01`, `02`, `03`, `06`, `8F`, `A6`, `D0`, `D5`, `F5`.

## Sinyal yang dipetakan

Rujukannya adalah layar CarInfo head unit dan panel instrumen, difoto pada
sesi yang sama.

| Nilai di layar | ID | Byte | Rumus | Cakupan |
|---|---|---|---|---|
| Odometer **30410** | `0x18FEDCD5` | b1–b2 LE | apa adanya | 2.997 / 2.997 |
| SOC **89,5 %** | `0x0CFF7D03` | b1 = 179 | % = nilai × 0,5 | 15.142 / 15.163 |
| Tegangan pack **357 V** | `0x0CFF7E03` | b2–b3 LE | volt apa adanya | 14.887 / 14.892 |
| SOH **97 %** | `0x0CFF7E03` | b1 = 97 | apa adanya | 14.892 / 14.892 |
| Suhu baterai **maks 30 °C** | `0x0CFF7E03` | b6 = 70 | °C = nilai − 40 | tetap |
| Suhu baterai **min 29 °C** | `0x0CFF7E03` | b7 = 69 | °C = nilai − 40 | tetap |
| Suhu controller **26 °C** | `0x0CFF1601` | b2 = 26 | apa adanya | 307 / 307 |
| **Tegangan 90 sel** | `0x0CFF8203` | b1 nomor sel, 3 × 16-bit LE | mV | cocok sel per sel dengan foto |
| **Suhu 30 sensor** | `0x0CFF8303` | b1 nomor sensor, 3 × 16-bit LE | °C = nilai − 40 | 29–30 °C, cocok |

Enam ID itu sudah diberi nama di alat lewat `POST /api/note`, jadi tampil di
kolom Name pada dashboard dan tercatat di `/notes/GELORAE-TEST-01/journal.log`.

### Frame BMS yang multiplex, dan bukti yang saling mengunci

`0x0CFF8203` membawa tegangan sel, dengan **b1 sebagai nomor sel awal** (1, 4, 7,
sampai 88) lalu tiga nilai 16-bit little-endian dalam milivolt. `0x0CFF8303`
berbentuk sama untuk suhu: b1 nomor sensor, tiga nilai, °C = nilai − 40.

Ini bukan lagi kecocokan angka statis, karena tiga hal saling mengunci:

1. **Cocok sel per sel dengan foto.** Indeks 1 memberi 3,979 / 3,980 / 3,973 V,
   sedangkan layar menampilkan sel 1–3 = 3,979 / 3,980 / 3,972 V. Indeks 4
   memberi 3,980 / 3,977 / 3,979 V melawan 3,979 / 3,977 / 3,979 V di layar.
   Enam nilai berurutan, meleset paling jauh 1 mV.
2. **Jumlahnya sama dengan tegangan pack.** Sembilan puluh sel dijumlahkan
   menghasilkan **357,0 V**, dan layar menampilkan 357 V. Dua pemetaan yang
   ditemukan terpisah saling membuktikan.
3. **Sel maksimum dan minimum di frame SOC cocok dengan isi frame sel.**
   `0x0CFF7D03` b6–b7 = 3778 mV, dan sel terendah yang sebenarnya adalah sel 7
   = 3778 mV, persis seperti yang ditunjuk b5 = 7. Untuk sisi maksimum, b3–b4 =
   3991 mV cocok dengan nilai tertinggi, tetapi b2 = 44 sedangkan sel 3991 mV
   yang ditemukan ada di posisi 46. Kemungkinan ada beberapa sel bernilai sama,
   atau penomorannya berbeda. Belum dipastikan.

Jadi susunan `0x0CFF7D03` adalah: SOC, lalu nomor dan nilai sel tertinggi, lalu
nomor dan nilai sel terendah.

### Temuan tentang kendaraannya, bukan tentang alat

Paket ini **tidak seimbang**. Sel 7 berada di 3,778 V sementara mayoritas sel di
kisaran 3,96–3,99 V, jadi selisihnya sekitar 200 mV. Sel 54 menyusul di 3,822 V.

| Sel | Tegangan |
|---|---|
| 7 | 3,778 V |
| 54 | 3,822 V |
| 89 | 3,913 V |
| 85 | 3,921 V |

Pada paket lithium, sel terendah yang menentukan kapasitas dan batas pengisian.
Layar CarInfo hanya menampilkan enam sel pertama box 1, semuanya sehat, sehingga
selisih ini tidak terlihat dari layar mobil. Ini perlu disampaikan ke pemilik
kendaraan, dan sebaiknya dipantau apakah selisihnya melebar.

### Belum pasti

- ~~**Arus 0 A** → `0x0CFF7E03` b4–b5 LE = 1000~~. **Sudah terbukti** di
  `gelora-004`: saat pedal dilepas pada 46 km/jam, nilainya jatuh dari +133
  menjadi −36 dalam satu detik. Offset 1000 memang untuk menampung arus
  regeneratif yang negatif. Rumusnya A = nilai − 1000.
- **Nomor sel tertinggi** → `0x0CFF7D03` b2 = 44, sedangkan sel bernilai 3991 mV
  ada di posisi 46. Nilainya sendiri sudah terbukti; yang belum jelas hanya
  penomorannya. Sisi minimum tidak punya masalah ini: b5 = 7 menunjuk tepat ke
  sel 7.

### Tidak ditemukan

Resistansi isolasi **7480 kΩ** tidak ada di seluruh 34 identifier, pada skala
mana pun yang dicoba. Kemungkinan besar nilai itu diminta head unit lewat
permintaan diagnostik, bukan disiarkan berkala. Alat ini tidak pernah meminta.

## Kenapa semuanya masih hipotesis (sudah terjawab, lihat gelora-004)

Kendaraan **diam** sepanjang rekaman, jadi tidak satu pun nilai ini bergerak.
Field mana pun yang kebetulan berisi angka yang benar dan diam akan terlihat
sama meyakinkannya.

Pembuktiannya, di run berikutnya sambil berjalan:

| Kandidat | Terbukti kalau | Hasil di `gelora-004` |
|---|---|---|
| Odometer | naik sesuai jarak yang ditempuh | **terbukti**, 30423 → 30427 |
| SOC | turun mengikuti angka di layar | **terbukti**, 74,0 → 71,0 % |
| Arus | keluar dari 1000, dan berbalik arah saat regeneratif | **terbukti**, +133 A → −36 A dalam satu detik |
| Suhu | ikut naik setelah pemakaian | **terbukti**, baterai 31 → 32 °C |
| Tegangan sel | ikut turun saat akselerasi berat | **terbukti** lewat tegangan pack, 350 → 333 V lalu pulih |

Uji jalan 23 Sep 2026 juga menambah dua sinyal baru yang tidak terlihat saat
diam: **kecepatan** dan **putaran motor**. Semuanya ada di
[`gelora-004.md`](gelora-004.md).

## Catatan jam

Jam di panel instrumen menunjukkan 23:18, sedangkan head unit menunjukkan 18:48
pada sesi yang sama. Salah satu dari keduanya tidak disetel. Ini perlu diingat
kalau nanti jam kendaraan dipakai untuk menyelaraskan rekaman dengan video.

## Batas pemakaian

Ini temuan tentang **DFSK**. Armada memakai Wuling, jadi tidak satu pun ID di
sini boleh masuk `signals.cfg` armada. Yang bisa dibawa adalah **caranya**:
bitrate 250 kbps, identifier extended, dan susunan frame BMS yang menaruh SOC,
tegangan pack, SOH, dan suhu dalam beberapa frame proprietary berdekatan.

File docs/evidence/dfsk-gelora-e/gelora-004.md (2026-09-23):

# gelora-004: DFSK Gelora E sambil berjalan, 23 Sep 2026

Rekaman pertama dengan kendaraan **bergerak**. Ini yang menaikkan status
pemetaan `gelora-001` dari dugaan menjadi terbukti, karena nilai yang diam tidak
membuktikan apa pun: field mana pun yang kebetulan berisi angka benar dan tidak
berubah akan terlihat sama meyakinkannya.

## Asal-usul

| | |
|---|---|
| Kendaraan | DFSK Gelora E (van listrik), dikemudikan di jalan umum |
| Firmware | env `gelora-e-250k`, unit `GELORAE-TEST-01`, listen-only |
| Bitrate | 250 kbps |
| Cara merekam | **dialirkan lewat WiFi ke laptop di dalam mobil**, penulisan flash dijeda |
| Waktu | 14:23:40 – 15:10:23 waktu laptop, 46,7 menit |
| Berkas | `captures/gelora-004/can-000.log` … `can-379.log`, 97 MB |
| Isi | **1.525.681 frame**, 34 identifier, rata-rata 544 frame/detik |
| Lembar run | `captures/gelora-004/RUN-SHEET.md` |

Delapan kali lipat isi rekaman `gelora-001` yang berhenti di batas 12 MB flash,
dan tanpa kehilangan frame akibat penulisan flash. Itu memang alasan cara
merekam ini dibuat (lihat `frame-loss.md`).

## Lubang di rekaman, dinyatakan di muka

Tautan WiFi putus **30 kali** dengan jeda lebih dari satu detik, total **418
detik**, atau **14,9 % dari rentang waktu sesi**. Empat lubang terbesar:

| Mulai | Lama |
|---|---|
| 15:07:04 | 121 detik |
| 14:39:45 | 118 detik |
| 14:38:17 | 59 detik |
| 14:42:06 | 46 detik |

Setiap putus ditandai baris `# LINK` di dalam berkas, tidak pernah ditutup
diam-diam. Konsekuensinya jujur: **rekaman ini sampel, bukan salinan utuh
perjalanan.** Untuk memetakan nilai yang disiarkan berkala hal itu tidak
mengubah kesimpulan, dan setiap bukti di bawah ini disusun supaya tahan terhadap
lubang tersebut. Untuk analisis yang bergantung pada urutan antar-frame, rekaman
ini tidak layak dipakai.

Penyebab yang sudah diketahui: laptop berada agak jauh dari alat dan dari
hotspot. Pada run berikutnya, dekatkan keduanya.

## Yang berhasil dibuktikan

### 1. Kecepatan: `0x18FEDCD5` b0, satuan km/jam

Buktinya berdiri sendiri, tanpa perlu foto maupun laporan pengemudi: **kecepatan
diintegrasikan terhadap waktu, lalu dibandingkan dengan odometer di bus yang
sama.**

| | |
|---|---|
| Kecepatan diintegrasikan sepanjang rekaman | **4,031 km** |
| Odometer CAN naik | 30423 → 30427, yaitu **4 km** |
| Kalau field itu mph, integralnya jadi | 6,49 km, butuh odometer naik 6–7 |

Angka odometer bertambah satu pada 14:29:41, 14:35:11, 14:56:35, dan 15:09:47.
Karena 14,9 % waktu tidak terekam, 4,031 km adalah **batas bawah**, dan
jarak sebenarnya ada di antara 4 dan 5 km. Pembacaan km/jam muat di situ,
pembacaan mph tidak. **Satuannya km/jam, dan mph tertolak.**

Perhatikan bahwa ini sekaligus membuktikan **odometer** `0x18FEDCD5` b1–b2 LE:
angkanya bergerak, arahnya benar, dan lajunya cocok dengan kecepatan di frame
yang sama.

Rentang terukur: 0 sampai **48 km/jam**.

### 2. Kecepatan halus: `0x18FFDC01` b4–b5 LE dibagi 256

Field kedua yang membawa kecepatan yang sama dengan resolusi 1/256 km/jam.
Korelasi terhadap field bulat **r = 0,9998**, kemiringan 256,1 per km/jam.

Yang menguatkan bahwa ini bukan kebetulan: maksimumnya **48,02 km/jam**
sementara field bulat berhenti di 48, dan integrasinya menghasilkan 4,031 km
melawan 3,66 km dari field bulat. Selisih 0,37 km itu persis sebesar bias
pembulatan ke bawah yang memang harus ada pada field bulat. Dua field saling
menjelaskan kesalahan masing-masing.

Untuk TDS, **field inilah yang dipakai**, bukan yang bulat: 1/256 km/jam cukup
halus untuk mendeteksi kendaraan mulai bergerak dan berhenti dengan rapi.

### 3. Putaran motor: `0x0CFF7902` b4–b5 LE dikurangi 12000

Ini yang paling tajam buktinya, karena ada satu angka di layar untuk diadu.

Foto panel instrumen pukul **15:09** menunjukkan **2045 rpm**. Di rekaman, pada
**15:09:07**, field itu bernilai mentah 14046, yaitu **2046 rpm**. **Meleset
satu rpm.**

Offsetnya ditentukan dengan regresi terhadap kecepatan yang sudah terbukti,
bukan dengan mencocok-cocokkan ke satu foto:

```
rpm_mentah = 87,77 x kecepatan + 12002,8      (11.765 pasangan)
nilai saat kendaraan diam   = 11.955 .. 12.109, rata-rata 12.000
```

Jadi **rpm = nilai − 12000**, dan 87,8 rpm motor per km/jam. Rentang terukur
−45 sampai **4143 rpm**; nilai negatif kecil itu getaran saat diam, dan tidak
ada satu pun sampel di bawah −100, jadi rekaman ini tidak pernah memuat mundur.

Pemeriksaan kewajaran mekanis: dengan ban 185/65R15 (keliling sekitar 1,90 m),
87,8 rpm per km/jam berarti rasio reduksi **10,0 : 1**. Itu angka yang lazim
untuk EV satu kecepatan. Ukuran ban di sini adalah asumsi, jadi perhitungan ini
hanya penguat, bukan bukti.

### 4. Arus: `0x0CFF7E03` b4–b5 LE dikurangi 1000, satuan ampere

Di `gelora-001` ini belum pasti, karena arusnya tetap 1000 sepanjang rekaman.
Sekarang terbukti, dan yang membuktikannya adalah **arah**:

| Jam | Kejadian | Arus | Kecepatan |
|---|---|---|---|
| 15:06:54 | menarik | **+133 A** | 47 km/jam |
| 15:06:55 | pedal dilepas | **−36 A** | 46 km/jam |

Satu detik, dari menarik penuh ke arus **berbalik arah**. Tidak ada tafsiran
lain untuk itu selain **pengereman regeneratif**, dan itu sekaligus menjelaskan
kenapa offset 1000 ada: supaya arus negatif muat dalam bilangan tanpa tanda.
Arus negatif tercatat pada 4,6 % waktu.

Rentang sepanjang sesi: −36 A sampai +133 A.

### 5. Yang ikut bergerak dan cocok

Semuanya dari `gelora-001`, sekarang terlihat berubah ke arah yang benar:

| Nilai | Awal | Akhir | Arah |
|---|---|---|---|
| SOC `0x0CFF7D03` b1 × 0,5 | 74,0 % | 71,0 % | turun karena dipakai |
| Tegangan pack `0x0CFF7E03` b2–b3 LE | 350 V | 348 V | turun sampai 333 V saat menarik |
| Suhu baterai maks `0x0CFF7E03` b6 − 40 | 31 °C | 32 °C | naik setelah dipakai |
| SOH `0x0CFF7E03` b1 | 97 % | 97 % | memang harus tetap |

Tegangan pack yang **melorot ke 333 V saat arus memuncak lalu pulih** adalah
perilaku baterai yang benar, dan itu mengunci pemetaan tegangan dan arus
sekaligus.

## Referensi lisan pengemudi: tidak dipakai

Selama uji, pengemudi menyebutkan kecepatan lewat pesan setiap sekitar 5 detik
(tersimpan di `speed-ref.csv`, 23 titik). Data itu **tidak dipakai sebagai
bukti**, dan alasannya perlu dicatat supaya tidak diulang:

- Korelasi terbaik hanya **r = 0,72**, dan baru tercapai setelah digeser 20
  detik. Jeda antara membaca panel, mengetik, dan pesan sampai tidak tetap.
- Kemiringannya keluar 0,64 terhadap mph yang dilaporkan, sedangkan km/jam
  menuntut 1,61 dan mph menuntut 1,00. Tidak memutuskan apa pun.

Pelajarannya untuk prosedur: **referensi kecepatan harus direkam, bukan
diketik.** Video panel instrumen dengan jam laptop terlihat di layar akan jauh
lebih berguna daripada 23 pesan. Sementara itu, odometer di bus yang sama
ternyata referensi yang lebih baik daripada manusia, dan gratis.

## Ringkasan status setelah run ini

| Sinyal | ID | Rumus | Status |
|---|---|---|---|
| Kecepatan | `0x18FEDCD5` b0 | km/jam apa adanya | **terbukti** |
| Kecepatan halus | `0x18FFDC01` b4–b5 LE | km/jam = nilai ÷ 256 | **terbukti** |
| Odometer | `0x18FEDCD5` b1–b2 LE | km apa adanya | **terbukti** |
| Putaran motor | `0x0CFF7902` b4–b5 LE | rpm = nilai − 12000 | **terbukti** |
| Arus | `0x0CFF7E03` b4–b5 LE | A = nilai − 1000 | **terbukti** |
| SOC | `0x0CFF7D03` b1 | % = nilai × 0,5 | **terbukti** |
| Tegangan pack | `0x0CFF7E03` b2–b3 LE | volt apa adanya | **terbukti** |
| Suhu baterai maks/min | `0x0CFF7E03` b6 / b7 | °C = nilai − 40 | **terbukti** |
| SOH | `0x0CFF7E03` b1 | % apa adanya | tetap, belum diuji |
| Suhu controller | `0x0CFF1601` b2 | °C apa adanya | **tetap 26 °C sepanjang sesi, dugaan** |
| Tegangan 90 sel | `0x0CFF8203` | multiplex, mV | terbukti di `gelora-001` |
| Suhu 30 sensor | `0x0CFF8303` | multiplex, °C − 40 | terbukti di `gelora-001` |

Suhu controller perlu dicatat: nilainya **tidak bergerak sama sekali** selama 47
menit berkendara, termasuk saat arus 133 A. Kalau benar itu suhu controller,
seharusnya naik. Statusnya turun kembali menjadi dugaan.

## Paket baterai: selisih sel melebar

`gelora-001` mencatat sel 7 di 3,778 V melawan mayoritas di 3,96–3,99 V. Foto
sebelum uji jalan ini menunjukkan sel terendah **3,650 V** dan tertinggi 3,911 V,
jadi selisihnya kini sekitar **260 mV**, naik dari sekitar 200 mV sehari
sebelumnya.

Ini temuan tentang kendaraannya, bukan tentang alat, dan sebaiknya disampaikan
ke pemilik. Layar CarInfo hanya menampilkan enam sel pertama, semuanya sehat,
jadi selisih ini tidak terlihat dari dalam mobil.

## Batas pemakaian

Sama seperti `gelora-001`: ini temuan tentang **DFSK**. Armada memakai Wuling,
jadi tidak satu pun ID di sini boleh masuk `signals.cfg` armada. Yang terbawa ke
TDS adalah **caranya membuktikan**, dan itu yang paling berharga dari run ini:

1. **Integrasi kecepatan terhadap odometer di bus yang sama** memutuskan satuan
   tanpa perlu referensi manusia sama sekali.
2. **Arah, bukan nilai**, yang membuktikan arus. Satu peristiwa melepas pedal
   lebih kuat daripada satu jam data yang tenang.
3. **Regresi terhadap sinyal yang sudah terbukti** memberi offset yang bulat dan
   masuk akal, dan foto hanya dipakai untuk memeriksanya, bukan untuk
   menurunkannya.

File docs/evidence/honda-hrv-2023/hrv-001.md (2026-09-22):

# hrv-001: Honda HR-V capture, recovered 20 Sep 2026

The only recording of the HR-V bus, pulled off the device flash three
weeks after the run, before the device was reflashed for anything else.

## Provenance

| | |
|---|---|
| Vehicle | Honda HR-V, test run of 8 Sep 2026 (photos in `bmt-can-bus-telemetry/foto-dokumentasi`) |
| Recorded by | firmware `2bcaabe`, unit id still `AVANZA-TEST-01` |
| Bitrate | 500 kbps, listen-only |
| Pulled | 20 Sep 2026 over WiFi from `192.168.100.41`, `tools/fetch_captures.py` |
| Files | `captures/device-2026-09-20/can-000.log` … `can-033.log`, 8,786,358 B |
| Converted | `captures/hrv-001.csv` (webCAN), `--stop-ms 229600` |

`captures/` is git-ignored: these files live on the work machine and need a
backup elsewhere. They cannot be recreated.

## Where the copies are

| Copy | Verified |
|---|---|
| Work machine, `captures/device-2026-09-20/` (git-ignored) | all 34 SHA-256 digests matched the device, 22 Sep |
| Work machine, `D:\Wahyu\captures\hrv-001-backup-2026-09-20.zip` | SHA-256 `e8a1500e...94581f1c`, identical to the zip it was copied from |
| Google Drive, the operator's own account (not the BMT account) | by the operator; not checked from this machine |

Both machine copies sit on the same physical SSD, so the Drive copy is the only
one that survives the loss of the laptop.

**The device copy was deleted on 22 Sep 2026** (`clearcaptures`, 35 files) to
make room for the DFSK Gelora E run, after the three copies above existed.

The two HR-V identifier notes the device held (`0x294` odometer, `0x324` outside
temperature) are **not** in the zip; they were archived after it was made, to
`captures/device-2026-09-20/notes-hrv/` on the work machine. Their full text is
also recorded in [hrv-001-candidates.md](hrv-001-candidates.md), which is in
the repository, so they survive the laptop too.

## What the recording contains

One continuous run. `millis()` climbs from 35,816 to 239,050 without a
restart, across all 34 segments: **3 min 23 s**, 180,416 frames, ~888 frames/s.

**The last 9.4 s are not vehicle data.** At 229.6 s the bus emits a burst of
39 identifiers never seen before, including extended and RTR frames with
all-zero payloads. Before that moment the recording holds **exactly 40
identifiers**, which is the number the dashboard displayed during the run
(photo of 16:06). The burst is the signature of the connector being unplugged.

So the evidence splits cleanly:

| Window | Frames | Identifiers | Use |
|---|---|---|---|
| 35.8 s → 229.6 s | 174,273 | 40 | **the vehicle** |
| 229.6 s → 239.1 s | 6,143 | 77 | disconnection noise, ignore |

`hrv-001.csv` contains the first window only. The raw logs keep both: raw
evidence is never edited (D-015), it is cut at the point of use.

## Integrity

- Every file's byte count matched the size the device reported.
- Every line parses; 61 lines (0.03%) are RTR frames printed with eight zero
  bytes, which is how the logger writes them, not corruption.
- No zero-byte padding anywhere.
- Two files were downloaded a second time; both SHA-256 digests matched.

### The serial console corrupts bulk transfers

First attempt used the console (`cat` over USB serial at 115200). The result
was **larger** than the original: `can-000.log` arrived as 286,184 B against
262,191 B on the device, padded with runs of zero bytes and duplicated
half-lines. The same duplication appears in the boot log, where one
`WIFI CONNECTED` line repeats seventeen times, and it silently ate a digit of
the device's own IP address (`192.168.100.4` for `.41`).

USB serial has no retransmission. **Do not pull evidence through it.** The
corrupt files are kept at `captures/serial-corrupt/` as the demonstration.
`tools/fetch_captures.py` (HTTP) is the supported path; `tools/pull_captures.py`
exists only for a device with no WiFi, and it size-checks every file.

## What this data can and cannot answer

**Can:** which identifiers the HR-V bus carries, their cycle times, which
bytes move, which byte is a rolling counter or a checksum. That is the survey
stage of `cansub-reverse-engineering`, and it can run today.

**Cannot:** what any value means. There is no reference series to correlate
against. GNSS had no fix (antenna fault, see the run photos), and OBD-II PID
polling is out of the question on a listen-only device. The recording also has
no `boot_epoch` header, because that came with `fd386ba`, so its timeline is
relative seconds, not wall clock.

The missing piece is a **video of the instrument cluster** on the next run,
which the skill's VISION mode reads into a reference series. Until then, any
signal claim about this data is a guess.

The dashboard photo of the same day shows odometer 069620 km, trip A 1459.6 km
and 29 °C. Those values were searched for across the ten payloads visible in
the screenshots and not found, which proves nothing either way; the full search
over all 40 identifiers is now possible against `hrv-001.csv`.

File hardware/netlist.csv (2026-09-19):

net | connections
+3V3 | C9.1 J10.1 J10.2 J4.1 JP4.2 R12.2 R14.2 R4.2 R6.2 U3.5 U3.8
+4V0 | C5.1 JP1.1 L2.2 R1.1 TP4.1
+5V | C3.1 C4.1 C8.1 D3.2 J3.1 JP3.1 L1.2 TP3.1 U1.4 U3.3
+5V_ESP | D3.1 J10.21
BTN | J11.14 SW1.1
CANH | D4.1 J2.1 R5.1 U3.7
CANL | D4.2 J2.2 JP2.2 U3.6
CAN_RX | J10.4 U3.4
CAN_TX | J10.5 R3.1
DHT_DATA | J10.8 J4.2 R6.1
FAN_G | Q1.1 R7.2 R8.1
FAN_IO | J10.19 R7.1
FAN_SW | D5.2 J5.2 Q1.2
FAN_V | D5.1 J5.1 JP3.2
FB4 | R1.2 R2.1 U2.4
GND | C1.2 C2.2 C3.2 C4.2 C5.2 C6.2 C7.2 C8.2 C9.2 D2.2 D4.3 D6.2 D7.2 D8.2 J1.2 J10.22 J11.1 J11.21 J11.22 J2.3 J3.2 J4.3 J6.2 J6.3 JP5.2 Q1.3 Q2.1 R16.2 R2.2 R8.2 SW1.2 TP2.1 U1.3 U1.5 U2.3 U2.5 U3.2
GPS_TXD | J10.11 J3.3
LED_G_A | D6.3 R10.2
LED_G_IO | J11.17 R10.1
LED_R_A | D6.1 R9.2
LED_R_IO | J11.18 R9.1
MDM_RXD_LV | J6.5 Q4.2 R13.1
MDM_RX_3V3 | J10.9 Q3.3 R12.1
MDM_TXD_LV | J6.4 Q3.2 R11.1
MDM_TX_3V3 | J10.10 Q4.3 R14.1
MDM_VREF | J6.7 JP4.1 Q3.1 Q4.1 R11.2 R13.2
MODEM_PWR | C6.1 C7.1 J6.1 JP1.2
PWRKEY | J6.6 JP5.1 Q2.3
PWRKEY_G | Q2.2 R15.2 R16.1
PWRKEY_IO | J10.20 R15.1
SW4 | D8.1 L2.1 U2.2
SW5 | D7.1 L1.1 U1.2
TERM | JP2.1 R5.2
TXD_T | R3.2 R4.1 U3.1
VIN_F | D1.2 D2.1 F1.2
VIN_P | C1.1 C2.1 D1.1 JP1.3 JP3.3 TP1.1 U1.1 U2.1
VIN_RAW | F1.1 J1.1

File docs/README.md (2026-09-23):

# docs/

Dokumentasi teknis alat diagnostik CAN. Pembacanya engineer atau agent.

Lapisan serah-terima project ada di `ProjectDocs/`, dan ia **merutekan** ke sini, bukan
menyalin isinya. Kalau keduanya berselisih, yang ada di `docs/` yang benar, karena di
sinilah isinya tinggal.

## Kalau kamu akan menyentuh kendaraan

Baca dua ini sampai habis, berurutan:

| Berkas | Isi |
|---|---|
| [RUN-PROCEDURE.md](RUN-PROCEDURE.md) | prosedur perekaman apa pun, termasuk yang diam |
| [PROSEDUR-TEST-JALAN.md](PROSEDUR-TEST-JALAN.md) | prosedur perekaman sambil berjalan, dengan laptop ikut di mobil |

Lalu [evidence/00-umum/frame-loss.md](evidence/00-umum/frame-loss.md), supaya kamu tahu
sejauh mana rekaman yang kamu hasilkan boleh dipercaya.

## Kalau kamu memakai dashboard

[DASHBOARD-TDS.md](DASHBOARD-TDS.md) menjelaskan tiga mode penyaring identifier,
panel Vehicle, dan cara menandai sebuah sinyal dengan `#tds` supaya ia muncul di
situ. Termasuk satu hal yang mudah disalahpahami: penyaring itu **tidak**
memperbaiki frame yang hilang, dan **tidak** menyaring perekaman.

## Kalau kamu akan memetakan sinyal

Prosesnya ada di skill **`bmt-can-signal-mapping`**, dan contoh lengkap yang sudah jadi
ada di [evidence/dfsk-gelora-e/gelora-004.md](evidence/dfsk-gelora-e/gelora-004.md).

## Arsip bukti, per jenis kendaraan

| Kendaraan | Folder | Status pemetaan |
|---|---|---|
| DFSK Gelora E | [evidence/dfsk-gelora-e/](evidence/dfsk-gelora-e/) | **terbukti** lewat uji jalan |
| Honda HR-V 2023 | [evidence/honda-hrv-2023/](evidence/honda-hrv-2023/) | kandidat, belum diuji jalan |
| Lintas kendaraan dan uji meja | [evidence/00-umum/](evidence/00-umum/) | |

Aturan penamaan folder, penamaan run, dan tingkat status sebuah pemetaan ada di
[evidence/README.md](evidence/README.md). **Mulailah dari README folder kendaraannya**,
bukan dari berkas run, karena README itu yang memuat tabel sinyal yang berlaku sekarang.

## Rujukan lain

| Berkas | Isi |
|---|---|
| [CAN-REFERENCES.md](CAN-REFERENCES.md) | rujukan luar tentang CAN dan reverse engineering |
| [PHASE-2-DASHBOARD.md](PHASE-2-DASHBOARD.md) | dashboard fase 2 dan jawaban atas masukan CEO |

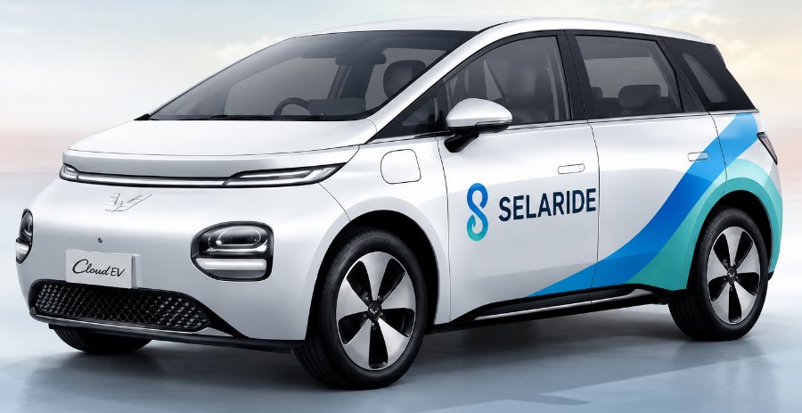
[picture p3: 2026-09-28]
web-argo/assets/car.jpg

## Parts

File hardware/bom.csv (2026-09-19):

fit | qty | refs | value | part / MPN | footprint | notes
ALL | 1 | C1 | 100uF 50V |  | Capacitor_THT:CP_Radial_D8.0mm_P3.50mm | Electrolytic, 105 C
ALL | 1 | C2 | 100nF 50V |  | Capacitor_THT:C_Disc_D5.0mm_W2.5mm_P5.00mm | Ceramic X7R
ALL | 1 | C3 | 1000uF 16V |  | Capacitor_THT:CP_Radial_D10.0mm_P5.00mm | Electrolytic low-ESR, 105 C
ALL | 3 | C4 C8 C9 | 100nF |  | Capacitor_THT:C_Disc_D5.0mm_W2.5mm_P5.00mm | C4: Ceramic | C8: VCC decoupling, at U3 pin 3 | C9: VIO decoupling, at U3 pin 5
ALL | 2 | D1 D7 | 1N5822 | 1N5822 | Diode_THT:D_DO-201AD_P15.24mm_Horizontal | D1: Schottky 3 A 40 V, series reverse-polarity block | D7: Catch diode
ALL | 1 | D2 | 1.5KE27A | Littelfuse 1.5KE27A | Diode_THT:D_DO-201_P15.24mm_Horizontal | TVS 1500 W, unidirectional. Clamps surges; conducts on reverse polarity so F1 trips
ALL | 2 | D3 D5 | 1N5819 | 1N5819 | Diode_THT:D_DO-41_SOD81_P10.16mm_Horizontal | D3: Stops USB 5 V back-feeding this board when the DevKit is plugged into a PC | D5: Fan flyback
ALL | 1 | D4 | PESD2CAN | Nexperia PESD2CAN | Package_TO_SOT_SMD:SOT-23 | CAN bus ESD protection
ALL | 1 | D6 | LED R/G CC |  | LED_THT:LED_D5.0mm-3 | 5 mm bicolour, common cathode. CHECK the pin order of the LED you buy
ALL | 1 | F1 | MF-RX160/72 | Bourns MF-RX160/72 |  | Resettable fuse, 1.6 A hold, 72 V, radial
ALL | 1 | J1 | 12V IN | Phoenix MKDS 1,5/2-5.08 (or any 5.08 mm 2-way) | TerminalBlock_Phoenix:TerminalBlock_Phoenix_MKDS-1,5-2-5.08_1x02_P5.08mm_Horizontal | Switched 12 V from an ACC fuse tap. NEVER OBD-II pin 16
ALL | 1 | J10 | DevKitC-1 J1 | 2.54 mm female socket 1x22 | Connector_PinSocket_2.54mm:PinSocket_1x22_P2.54mm_Vertical | Socket for ESP32-S3-DevKitC-1 (N16R8) header J1
ALL | 1 | J11 | DevKitC-1 J3 | 2.54 mm female socket 1x22 | Connector_PinSocket_2.54mm:PinSocket_1x22_P2.54mm_Vertical | Socket for ESP32-S3-DevKitC-1 (N16R8) header J3
ALL | 1 | J2 | OBD-II CAN | Phoenix MKDS 1,5/3-5.08 | TerminalBlock_Phoenix:TerminalBlock_Phoenix_MKDS-1,5-3-5.08_1x03_P5.08mm_Horizontal | To OBD-II pin 6 (CANH), 14 (CANL), 5 (signal GND). No pin 16 position exists
ALL | 1 | J3 | GPS NEO-6M |  | Connector_PinHeader_2.54mm:PinHeader_1x04_P2.54mm_Vertical | GY-GPS6MV2 module. Its RX stays unconnected: GPIO19 is USB D- on the S3
ALL | 1 | J4 | DHT22 |  | Connector_PinHeader_2.54mm:PinHeader_1x03_P2.54mm_Vertical | DHT22 / AM2302
ALL | 1 | J5 | FAN |  | Connector_PinHeader_2.54mm:PinHeader_1x02_P2.54mm_Vertical | Fan connector
ALL | 1 | JP2 | TERM BENCH ONLY |  | Connector_PinHeader_2.54mm:PinHeader_1x02_P2.54mm_Vertical | OPEN in a vehicle (it is already 60 R). CLOSED on a two-node bench
ALL | 1 | JP3 | FAN VOLTAGE |  | Connector_PinHeader_2.54mm:PinHeader_1x03_P2.54mm_Vertical | 1-2: 5 V fan. 2-3: 12 V fan
ALL | 1 | L1 | 100uH 3A |  |  | Power inductor 100 uH, >= 3 A saturation (toroid or drum)
ALL | 1 | Q1 | IRLZ44N | IRLZ44N | Package_TO_SOT_THT:TO-220-3_Vertical | Fan low-side switch (as on the proven prototype)
ALL | 1 | R3 | 1k |  | Resistor_THT:R_Axial_DIN0207_L6.3mm_D2.5mm_P10.16mm_Horizontal | Series, GPIO5 to TXD
ALL | 2 | R4 R6 | 10k |  | Resistor_THT:R_Axial_DIN0207_L6.3mm_D2.5mm_P10.16mm_Horizontal | R4: TXD held recessive | R6: DHT22 data pull-up
ALL | 1 | R5 | 120R |  | Resistor_THT:R_Axial_DIN0207_L6.3mm_D2.5mm_P10.16mm_Horizontal | Terminator, bench only
ALL | 3 | R7 R9 R10 | 330R |  | Resistor_THT:R_Axial_DIN0207_L6.3mm_D2.5mm_P10.16mm_Horizontal | R7: Gate series | R9: LED red | R10: LED green
ALL | 1 | R8 | 100k |  | Resistor_THT:R_Axial_DIN0207_L6.3mm_D2.5mm_P10.16mm_Horizontal | Gate pull-down: fan off while the ESP32 boots
ALL | 1 | SW1 | BUTTON |  | Button_Switch_THT:SW_PUSH_6mm | 6 mm tactile. GPIO0: held at power-up it enters download mode
ALL | 1 | TP1 | VIN_P |  | TestPoint:TestPoint_THTPad_D2.0mm_Drill1.0mm | Test point
ALL | 1 | TP2 | GND |  | TestPoint:TestPoint_THTPad_D2.0mm_Drill1.0mm | Test point
ALL | 1 | TP3 | +5V |  | TestPoint:TestPoint_THTPad_D2.0mm_Drill1.0mm | Test point
ALL | 1 | U1 | LM2576HVT-5.0 | TI LM2576HVT-5.0 | Package_TO_SOT_THT:TO-220-5_P3.4x3.7mm_StaggerOdd_Lead3.8mm_Vertical | Buck 5 V 3 A, 60 V input. FB senses the output on the fixed version
ALL | 1 | U3 | TJA1051T/3 | NXP TJA1051T/3 | Package_SO:SOIC-8_3.9x4.9mm_P1.27mm | CAN transceiver. S tied HIGH = Silent mode: the transmitter is off in silicon
FLEET | 1 | C5 | 1000uF 10V |  | Capacitor_THT:CP_Radial_D10.0mm_P5.00mm | Electrolytic low-ESR
FLEET | 1 | C6 | 2200uF 10V |  | Capacitor_THT:CP_Radial_D12.5mm_P5.00mm | Low-ESR bulk AT the modem connector (fleet 01-PINOUT)
FLEET | 1 | C7 | 100nF |  | Capacitor_THT:C_Disc_D5.0mm_W2.5mm_P5.00mm | Decoupling
FLEET | 1 | D8 | 1N5822 | 1N5822 | Diode_THT:D_DO-201AD_P15.24mm_Horizontal | Catch diode
FLEET | 1 | J6 | A7670C |  | Connector_PinHeader_2.54mm:PinHeader_1x07_P2.54mm_Vertical | To the A7670C board. MATCH THIS TO THE BOARD YOU BUY before ordering the PCB
FLEET | 1 | JP1 | MODEM SUPPLY |  | Connector_PinHeader_2.54mm:PinHeader_1x03_P2.54mm_Vertical | 1-2: 4.0 V to a bare-module VBAT. 2-3: 12 V to a breakout with its own regulator
FLEET | 1 | JP4 | VREF=3V3 |  | Connector_PinHeader_2.54mm:PinHeader_1x02_P2.54mm_Vertical | CLOSE only if the modem board's UART is 3.3 V and has no VREF output of its own
FLEET | 1 | JP5 | AUTO-ON |  | Connector_PinHeader_2.54mm:PinHeader_1x02_P2.54mm_Vertical | Fit OPEN. Closing it holds PWRKEY low for auto power-on, which the A7670 manual does not promise: test on the real module first
FLEET | 1 | L2 | 100uH 3A |  |  | Power inductor 100 uH, >= 3 A saturation. Modem bursts reach ~2 A
FLEET | 1 | Q2 | 2N7000 | 2N7000 | Package_TO_SOT_THT:TO-92_Inline | Pulls PWRKEY low on command (GPIO14)
FLEET | 2 | Q3 Q4 | BSS138 | BSS138 | Package_TO_SOT_SMD:SOT-23 | Q3: Level shift modem TXD -> GPIO16 | Q4: Level shift GPIO17 -> modem RXD
FLEET | 1 | R1 | 2k2 1% |  | Resistor_THT:R_Axial_DIN0207_L6.3mm_D2.5mm_P10.16mm_Horizontal | Feedback top
FLEET | 4 | R11 R12 R13 R14 | 10k |  | Resistor_THT:R_Axial_DIN0207_L6.3mm_D2.5mm_P10.16mm_Horizontal | R11: Pull-up, modem side | R12: Pull-up, ESP32 side
FLEET | 1 | R15 | 1k |  | Resistor_THT:R_Axial_DIN0207_L6.3mm_D2.5mm_P10.16mm_Horizontal | Gate series
FLEET | 1 | R16 | 100k |  | Resistor_THT:R_Axial_DIN0207_L6.3mm_D2.5mm_P10.16mm_Horizontal | Gate pull-down
FLEET | 1 | R2 | 1k 1% |  | Resistor_THT:R_Axial_DIN0207_L6.3mm_D2.5mm_P10.16mm_Horizontal | Feedback bottom
FLEET | 1 | TP4 | +4V0 |  | TestPoint:TestPoint_THTPad_D2.0mm_Drill1.0mm | Test point
FLEET | 1 | U2 | LM2576HVT-ADJ | TI LM2576HVT-ADJ | Package_TO_SOT_THT:TO-220-5_P3.4x3.7mm_StaggerOdd_Lead3.8mm_Vertical | Buck 3.94 V for modem VBAT: 1.23 x (1 + 2k2/1k)
ALL | 1 | - | ESP32-S3-DevKitC-1 N16R8 | Espressif | plugs into J10/J11 | the module already in use
ALL | 4 | - | M3 mounting hole |  | MountingHole:MountingHole_3.2mm_M3 | corners

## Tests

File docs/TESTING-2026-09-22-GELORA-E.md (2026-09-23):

# Laporan pengujian DFSK Gelora E, 22 September 2026

Sesi pertama pada kendaraan listrik, dan sesi pertama yang berhasil memetakan
angka di layar kendaraan ke byte CAN dalam satu hari yang sama.

Kondisi: mesin mati, kunci kontak ON, kendaraan diam sepanjang perekaman.
Alat dalam mode listen-only permanen.

---

## 1. Hasil utama

### Bitrate bus: 250 kbps, bukan 500

Percobaan pertama di 500 kbps menghasilkan **1.579.745 bus error dalam 378 detik**
dan **nol frame**. Dashboard menyebutnya "Wrong bitrate, most likely", dan itu
tepat. Setelah diganti ke 250 kbps: 34 identifier, nol bus error.

Ribuan error itu tidak mengganggu kendaraan. Mode listen-only tidak pernah
mengirim bit dominan, termasuk error frame.

### Bentuk bus berbeda dari mobil penumpang

Seluruh 34 identifier memakai **29-bit extended**, bergaya J1939 seperti
kendaraan niaga, bukan 11-bit seperti Honda HR-V. Byte terakhir ID adalah
alamat ECU: terlihat `01`, `02`, `03`, `06`, `8F`, `A6`, `D0`, `D5`, `F5`.

### Sinyal yang berhasil dipetakan

| Nilai di layar kendaraan | ID | Byte | Rumus |
|---|---|---|---|
| Odometer 30410 | `0x18FEDCD5` | b1–b2 LE | apa adanya |
| SOC 89,5 % | `0x0CFF7D03` | b1 | × 0,5 |
| Tegangan pack 357 V | `0x0CFF7E03` | b2–b3 LE | apa adanya |
| SOH 97 % | `0x0CFF7E03` | b1 | apa adanya |
| Suhu baterai maks/min 30/29 °C | `0x0CFF7E03` | b6, b7 | − 40 |
| Suhu controller 26 °C | `0x0CFF1601` | b2 | apa adanya |
| **Tegangan 90 sel** | `0x0CFF8203` | b1 nomor sel, 3 × 16-bit LE | mV |
| **Suhu 30 sensor** | `0x0CFF8303` | b1 nomor sensor, 3 × 16-bit LE | − 40 |
| Sel tertinggi dan terendah + nomornya | `0x0CFF7D03` | b2, b3–4, b5, b6–7 | mV |

Dua frame terakhir berbentuk **multiplex**: satu byte menyatakan nomor awal,
tiga nilai menyusul.

### Kenapa pemetaan ini kuat

Tiga pemeriksaan yang saling mengunci, bukan sekadar satu angka yang kebetulan
cocok:

1. **Cocok sel per sel dengan foto layar.** Indeks 1 memberi 3,979 / 3,980 /
   3,973 V melawan 3,979 / 3,980 / 3,972 V di layar. Indeks 4 cocok untuk tiga
   sel berikutnya. Meleset paling jauh 1 mV.
2. **Jumlah 90 sel = 357,0 V**, dan layar menampilkan tegangan pack 357 V. Dua
   pemetaan yang ditemukan terpisah membuktikan satu sama lain.
3. **Sel terendah di frame SOC cocok dengan isi frame sel**: 3778 mV di sel 7,
   persis seperti yang ditunjuk penomorannya.

### Yang tidak ditemukan

Resistansi isolasi 7480 kΩ tidak ada di identifier mana pun. Kemungkinan besar
diminta head unit lewat permintaan diagnostik, bukan disiarkan berkala. Alat ini
tidak pernah meminta apa pun.

---

## 2. Temuan tentang kendaraannya

**Paket baterai tidak seimbang.** Sel 7 berada di 3,778 V sementara mayoritas
sel di 3,96–3,99 V, selisih sekitar 200 mV. Sel 54 menyusul di 3,822 V.

Layar CarInfo hanya menampilkan enam sel pertama box 1, semuanya sehat, jadi
selisih ini **tidak terlihat dari dalam kendaraan**. Pada paket lithium, sel
terendah yang menentukan kapasitas dan batas pengisian.

Ini temuan yang perlu disampaikan ke pemilik kendaraan, dan perlu dipantau
apakah selisihnya melebar.

---

## 3. Temuan tentang alat kita sendiri

**Alat kehilangan frame justru ketika merekam.** Terukur 4,9 % di Gelora E, dan
22 sampai 26 % di Honda HR-V yang busnya jauh lebih padat.

Penyebabnya bukan CPU, yang hanya terpakai beberapa persen. Framework yang
dipakai dikirim dengan `CONFIG_TWAI_ISR_IN_IRAM` tidak aktif, sehingga rutin
interupsi CAN berada di flash. Setiap kali flash ditulis, cache instruksi mati,
interupsi berhenti, dan FIFO controller meluap. Terbukti dari perbandingan:
**31.548 dari 31.643 frame hilang berjenis `rx_overrun`** (FIFO hardware), dan
saat flash menganggur kehilangannya **nol** pada 644 frame per detik.

Artinya untuk pekerjaan pemetaan: survei ID dan pemetaan nilai tetap sah, karena
nilai disiarkan berulang. Yang tidak bisa dipercaya adalah analisis yang
bergantung pada urutan antar-frame.

Rinciannya di [`evidence/frame-loss.md`](evidence/frame-loss.md).

---

## 4. Yang dibangun selama sesi ini

**Dashboard**

- Kolom **Name** kosong di sebelah ID, siap diisi saat pengujian dan tersimpan
  di alat.
- Catatan bisa berisi **rumus hidup**: ditulis `SOC {b1*0.5} %`, tampil sebagai
  `SOC 89.5 %` dan ikut berubah tiap frame. Nilai mentahnya tetap ditampilkan
  di sebelahnya, supaya setiap angka bisa ditelusuri balik ke byte.
- Tiap byte tampil hex di atas, desimal di bawah. Tabel muat satu layar.
- Panel Health yang menyatakan kondisi alat apa adanya, termasuk yang
  menemukan masalah kehilangan frame di atas.

**Firmware**

- Satu env PlatformIO per kendaraan: `hrv`, `gelora-e`, `gelora-e-250k`. Nama
  unit dan bitrate ikut env, tidak lagi diedit tangan.
- Catatan ID dipisah per kendaraan, karena nomor ID berulang antar merek.
- Penomoran segmen melanjutkan dari yang terakhir, dan anggaran rekaman memakai
  sisa ruang yang sebenarnya. Sebelumnya rekaman baru bisa menempel di berkas
  run lama dengan basis waktu berbeda.
- **Aliran frame lewat WiFi** ke laptop, plus tombol jeda, lanjut, dan kosongkan
  flash lewat HTTP.

**Alat bantu**

| Berkas | Gunanya |
|---|---|
| `tools/fetch_captures.py` | menarik rekaman lewat WiFi, memeriksa ukuran dan isi tiap berkas |
| `tools/stream_capture.py` | menerima aliran langsung dan menulisnya sebagai berkas capture |
| `tools/match_dashboard.py` | mencocokkan angka di layar ke seluruh posisi byte di semua ID |
| `tools/capture_to_webcan.py` | dua bug diperbaiki: basis waktu dan deteksi boot |

**Perangkat keras**

Rancangan PCB rev A selesai, dan rev B mendapat satu tambahan wajib: **slot
microSD**, karena menulis ke SD lewat SPI tidak mematikan cache.

---

## 5. Data dan tempatnya

| Rekaman | Isi | Tempat |
|---|---|---|
| `hrv-001` | Honda HR-V, 8 Sep, 194 ribu frame | laptop, dua salinan, plus Google Drive |
| `gelora-001` | Gelora E, 22 Sep, 194.219 frame, 34 ID | laptop, `captures/gelora-001/` |

Rekaman Gelora E **belum punya cadangan di luar laptop**. Ini yang paling
mendesak setelah laporan ini.

---

## 6. Yang belum terbukti

Seluruh pemetaan di atas diambil saat **kendaraan diam**, jadi nilainya tidak
bergerak. Pembuktiannya menuntut satu kali jalan:

| Kandidat | Terbukti kalau | Hasil uji jalan 23 Sep |
|---|---|---|
| Odometer | naik sesuai jarak tempuh | **terbukti**, 30423 → 30427 |
| SOC | turun mengikuti layar | **terbukti**, 74,0 → 71,0 % |
| Arus, `0x0CFF7E03` b4–b5 LE = 1000 | keluar dari 1000 saat akselerasi, berbalik saat regeneratif | **terbukti**, +133 A lalu −36 A dalam satu detik |
| Suhu | naik setelah pemakaian | **terbukti**, 31 → 32 °C |
| Tegangan sel | ikut turun saat akselerasi berat | **terbukti** lewat tegangan pack, 350 → 333 V lalu pulih |

Uji jalan itu dilakukan 23 September 2026 dan menambah dua sinyal yang tidak
mungkin terlihat saat kendaraan diam: **kecepatan** (`0x18FEDCD5` b0 dalam
km/jam, dan `0x18FFDC01` b4–b5 LE dengan resolusi 1/256 km/jam) serta
**putaran motor** (`0x0CFF7902` b4–b5 LE dikurangi 12000, meleset satu rpm dari
angka di panel instrumen). Laporan lengkapnya di
[`docs/evidence/gelora-004.md`](evidence/gelora-004.md).

---

## 7. Batas pemakaian

Ini temuan tentang **DFSK**. Armada memakai Wuling, jadi tidak satu pun ID di
sini boleh masuk `signals.cfg` armada. Yang berpindah adalah **caranya**, bukan
angkanya: cara menemukan bitrate, bentuk frame BMS yang multiplex, dan cara
membuktikan pemetaan lewat jumlah sel melawan tegangan pack.

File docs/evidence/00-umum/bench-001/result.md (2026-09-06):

# bench-001 — Firmware bring-up on the bench

**Status:** PASS (firmware only — no CAN bus, no peripherals wired yet)
**Date:** 2026-08-24
**Board:** ESP32-S3 (QFN56) rev v0.2, 16 MB flash, 8 MB embedded PSRAM
**MAC:** 14:c1:9f:cb:2d:98
**Port:** COM6, FTDI FT232R (VID:PID 0403:6001)

## What this run proves

The firmware compiles, flashes, boots, and brings up CAN in listen-only mode on
real silicon. Nothing more — no CAN bus was attached and no peripherals were
wired.

## Setup

| | |
|---|---|
| Toolchain | PlatformIO, espressif32 |
| Build | 0 warnings, 0 errors at `-Wall -Wextra` |
| RAM | 17.8% (58,472 / 327,680 B) |
| Flash | 38.2% (800,081 / 2,097,152 B app partition) |
| LittleFS | 14,272 KB |
| CAN bitrate | 500 kbps |
| Module 120 Ω terminator | not yet checked — bench, no bus attached |

## M1A acceptance evidence (D-003)

Present verbatim in `serial-log.txt`:

```
[CAN] Driver initialized
[CAN] Bitrate: 500000
[CAN] Mode: LISTEN_ONLY
[CAN] TX: DISABLED (listen-only)
```

Plus `listen-only locked: YES`.

## Result at 30 s

```
CAN   RUNNING @ 500 kbps LISTEN-ONLY=LOCKED
      rx=0 drop=0 missed=0 err=0 rec=0 ids=0 silence=no frames yet
CAP   sink=2 frames=0 bytes=0 path=/capture/can-000.log
GPS   fix=NO sats=0 sog=0.0 km/h sentences=0 badcrc=0
TEMP  enclosure=-- fan_sensor=45.0 C fan=AUTO/OFF run=0 s
WIFI  CONNECTING ip=0.0.0.0 rssi=0 dBm  web_requests=0
```

Every one of those is the correct reading for a board with nothing attached:

- `rx=0`, `silence=no frames yet` — no CAN bus connected
- `sentences=0` — GPS module not wired
- `enclosure=--` — DHT22 not wired; the fan correctly **fell back to the SoC die
  sensor** (45.0 °C) rather than guessing. That fallback path is now confirmed
  on hardware.
- `WIFI CONNECTING` — `Secrets.h` still holds the placeholder SSID

Nothing fabricated a value it did not have. That is the behaviour the whole
design is built around.

## Defects found and fixed during this run

1. **Flash configured as 8 MB on a 16 MB chip.** `esptool flash_id` reported
   16 MB; the partition table only spanned half of it, leaving ~6 MB for
   captures instead of ~14 MB. New `avanza_test_16mb.csv`; LittleFS now
   14,272 KB.
2. **GPIO19 pin conflict.** The blueprint pinout puts GPS TX on GPIO19, which
   is `USB_D-` on the ESP32-S3. With the native USB port in use the GPS UART and
   the USB peripheral contend for one pin, and it presents as a broken GPS
   module. `GPS_TX_PIN` is now -1; the firmware only listens to NMEA, so the pin
   was never needed.
3. **Upload failed on the native USB port.** Auto-reset there depends on the
   running firmware cooperating. Switched to the COM port (FTDI bridge, physical
   auto-reset) and `ARDUINO_USB_CDC_ON_BOOT=0`, which also keeps the console
   alive if the firmware crashes.
4. **Monitor filters corrupted the stream.** `time` + `esp32_exception_decoder`
   fragmented the output and repeated one line ~150,000 times, which initially
   looked like a boot loop. Filters removed from the default.
5. **`silence=4294967295 ms`** — the "never received a frame" sentinel printed
   raw. Now prints `no frames yet`.

## Known issues

None outstanding for this stage.

## Next action

Bench CAN reception with a second transmitting node, both 500 and 250 kbps,
with correct bench termination (~60 Ω across CANH–CANL, module terminators
kept). Then GPS and DHT22 wiring. Only then the vehicle.

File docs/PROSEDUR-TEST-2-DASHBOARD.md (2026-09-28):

# Prosedur test jalan dua dashboard

Untuk uji jalan 29 September 2026 di DFSK Gelora E, atas instruksi Direktur BMT
28 September: alat menampilkan dua dashboard sekaligus dan lokal dulu, dan tombol
mulai/akhiri argo dipencet manual, orang yang memencet berperan sebagai penumpang.

Ini melengkapi `PROSEDUR-TEST-JALAN.md`, bukan menggantikannya. Yang di sana
tentang merekam bus; yang di sini tentang menonton hasilnya hidup-hidup.

## Apa yang berubah di alat

| | Alamat | Untuk siapa | Isinya |
|---|---|---|---|
| Dashboard teknis | `http://<ip>/` | teknisi | status bus, semua identifier, frame mentah, panel Vehicle berisi nilai hasil rumus di catatan |
| Dashboard argo | `http://<ip>/argo` | pengemudi dan penumpang | layar SELARIDE: tarif, jarak isi, durasi, kecepatan, daya baterai, tombol trip |

Keduanya dari satu alat, dan boleh dibuka bersamaan dari dua gawai.

Endpoint baru: `GET /api/signals` (nilai ter-decode plus keadaan argo) dan
`POST /api/argo?action=start|stop`.

## Melihat kedua layar tanpa alat

Alat sering ada di mobil, sedangkan layarnya perlu dilihat di meja. `tools/fake_device.py`
adalah alat tiruan: satu berkas Python yang melayani kedua halaman dan semua endpoint
yang mereka minta, dengan satu kendaraan tiruan yang menyetir keduanya.

```
python tools/fake_device.py 8131 --lan
```

Tanpa `--lan` hanya bisa dibuka dari komputer ini. Dengan `--lan`, dua gawai di WiFi
yang sama bisa membuka dua alamat itu, persis susunan yang dipakai di jalan besok.

Kendaraan tiruannya menjalani satu rute pendek yang berulang: berangkat, jalan lepas,
macet, merayap di bawah ambang tunggu, lalu berhenti. Merayapnya sengaja ada, karena
"di bawah 5 km/jam tapi masih bergerak" adalah kasus yang tidak akan pernah muncul di
rute yang cuma berhenti mati.

Nilainya **dikodekan kembali menjadi byte CAN** seperti Gelora E mengirimnya, jadi panel
Vehicle di dashboard teknis benar-benar menjalankan rumus `{le16(4)/256}` dari
`notes.tsv`, bukan menerima angka jadi. Kalau rumus di catatan dan tabel di
`src/SignalDecoder.cpp` berbeda, pratinjau ini yang memperlihatkannya lebih dulu.

**Yang tidak bisa dijawab pratinjau ini:** beban CPU alat, `rx_overrun` saat dua gawai
membuka dua halaman sekaligus, dan bagaimana ponsel berlaku di kendaraan yang bergerak.
Itu semua hanya bisa diukur di jalan. Pratinjau ini menjawab "layarnya jalan dan
hitungannya benar", tidak lebih.

## Sebelum berangkat

1. **Pasang catatan identifier.** Panel Vehicle di dashboard teknis menghitung
   nilainya dari rumus yang ada di catatan, bukan dari firmware, jadi tanpa
   langkah ini panel itu kosong:

   ```
   python tools/apply_notes.py --host <ip alat> docs/evidence/dfsk-gelora-e/notes.tsv
   ```

2. **Buka kedua alamat, satu di tiap gawai.** Pastikan keduanya hidup sebelum
   kendaraan bergerak. Kalau salah satu tidak mau terbuka, periksa WiFi alat
   dulu, bukan halamannya.

3. **Jangan lupa rekamannya.** Uji ini soal tampilan, tetapi rekaman mentah tetap
   bukti. Nyalakan seperti biasa dari dashboard teknis.

4. **Cek angka pertama.** Di dashboard argo, sebelum argo dimulai, tarif harus
   `Rp 0` dan tulisannya `Argo berhenti, kilometer kosong tidak ditagih`. Kalau
   sudah ada angka sebelum dipencet, hentikan dan laporkan: itu bukan kesalahan
   tampilan, itu argo menagih tanpa penumpang.

## Urutan jalan

1. **Berangkat dengan argo mati.** Berkendara beberapa ratus meter. Ini kilometer
   kosong, dan tarifnya harus tetap `Rp 0`. Kalau bertambah, hentikan uji.
2. **Berhenti, pencet `Mulai trip`.** Tombolnya berubah jadi `Akhiri trip` dan
   pilnya berubah jadi `TERISI`.
3. **Jalan normal.** Perhatikan `Argometer` bertambah tiap 100 meter, tidak
   mulus. Memang begitu: yang ditagih adalah detak, bukan jarak berjalan.
4. **Berhenti di lampu merah atau macet.** Di bawah 5 km/jam, baris
   `Waktu tunggu` yang berjalan dan `Argometer` berhenti. Dua-duanya tidak boleh
   berjalan bersamaan. Ini yang paling perlu dilihat langsung.
5. **Merayap pelan, di bawah 5 km/jam tapi bergerak.** Waktu tunggu harus tetap
   berjalan, jarak tetap diam. Ambangnya kecepatan, bukan berhenti.
6. **Pencet `Akhiri trip`.** Angkanya berhenti di tempat dan tetap terbaca, karena
   di situlah penumpang membayar.
7. **Jalan lagi dengan argo mati**, pastikan tarifnya tidak bertambah.

## Yang dicatat, dan kenapa

| Yang dicatat | Kenapa |
|---|---|
| Odometer di panel kendaraan saat `Mulai` dan saat `Akhiri` | jarak isi di layar harus sama dengan selisihnya, dibulatkan ke bawah per 100 m |
| Tarif akhir, jarak isi, menit tunggu | kalikan sendiri: `km x 8.200 + menit x 5.000`. Kalau tidak sama, layar berdebat dengan dirinya sendiri |
| Apa yang terjadi saat dua gawai membuka dua halaman bersamaan | alat ini melayani satu permintaan pada satu waktu |
| `rx_overrun`, `rx_missed`, dan status kesehatan di dashboard teknis | dua dashboard hidup adalah beban baru yang belum pernah diukur |
| Apakah panel Vehicle dan layar argo menunjukkan angka yang sama | keduanya punya sumber rumus yang berbeda, lihat bagian di bawah |

## Dua sumber rumus, dan ini harus diawasi

Nilai di **panel Vehicle** dihitung dari rumus yang ditulis di catatan identifier,
di dalam alat, dan bisa diubah siapa pun dari halaman itu. Nilai di **layar argo**
dihitung oleh tabel di firmware (`src/SignalDecoder.cpp`), yang hanya berubah lewat
build baru.

Keduanya berasal dari bukti yang sama (`docs/evidence/dfsk-gelora-e/gelora-004.md`),
jadi seharusnya selalu sama. Kalau berbeda di jalan, yang salah bukan salah satunya
begitu saja: catat keduanya, jangan diperbaiki di tempat, dan bandingkan dengan
berkas bukti setelah di meja.

## Batas yang perlu diketahui sebelum, bukan sesudah

- **Argo tidak disimpan.** Alat reboot di tengah trip berarti tarifnya hilang dan
  harus dipencet `Mulai` lagi. Disengaja: alternatifnya menulis ke filesystem yang
  menyimpan rekaman CAN, dan tidak ada fitur tampilan yang sepadan dengan risiko itu.
- **Jarak ditagih dari odometer**, bukan dari integral kecepatan. Odometer DFSK
  beresolusi 1 km, jadi jarak isi bertambah dalam langkah 1 km, bukan mulus.
  Kalau ini terasa kasar di jalan, itu temuan yang bagus dan perlu dicatat, bukan
  bug.
- **Waktu tunggu Rp 5.000 per menit belum disahkan** Direktur dan Direktur Utama,
  dan layar menandainya. Angkanya berjalan supaya bisa dilihat, bukan supaya
  ditagihkan.
- **Identitas pengemudi di layar adalah contoh**, bukan data orang.
- **Semua angka ini milik DFSK Gelora E**, kendaraan uji. Armada memakai Wuling dan
  belum pernah dipetakan.

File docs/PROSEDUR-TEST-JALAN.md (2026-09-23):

# Prosedur test jalan

Untuk perekaman sambil berjalan, dengan laptop ikut di mobil dan frame
dialirkan lewat WiFi. Dua orang: satu menyetir, satu memegang laptop dan
kamera. **Pengemudi tidak menyentuh laptop.**

Tujuannya satu: membuat nilai-nilai **bergerak**, supaya pemetaan yang sudah
ditemukan bisa naik status dari dugaan menjadi terbukti. Nilai yang diam tidak
membuktikan apa pun.

---

## A. Sebelum berangkat, kendaraan masih mati

- [ ] **Alat terpasang di OBD-II**, kunci kontak mati saat mencolok.
- [ ] **Hotspot HP menyala**, 2,4 GHz, dan laptop tersambung ke hotspot yang sama.
- [ ] **Tutup dashboard di HP.** Setiap halaman yang terbuka ikut merebut WiFi
      yang sama dengan aliran frame.
- [ ] Buka dashboard **di laptop saja**, pastikan header menyebut `GELORAE-TEST-01`,
      bitrate 250 kbps, dan tulisan LISTEN-ONLY.
- [ ] **Letakkan laptop dekat dengan alat dan dekat dengan HP.** Jarak dan bodi
      mobil adalah penyebab paling umum frame terbuang di jalur WiFi. Pada run
      `gelora-004` hal ini membuat **14,9 % waktu tidak terekam sama sekali**,
      dengan dua lubang masing-masing dua menit. Ini kesalahan yang paling mahal
      dan paling mudah dihindari.
- [ ] **Siapkan kamera merekam video panel instrumen**, bukan mencatat angka
      lewat pesan. Pada `gelora-004`, 23 laporan kecepatan yang diketik hanya
      mencapai korelasi 0,72 dengan bus, dan tidak memutuskan apa pun. Arahkan
      kamera ke panel, dan sekali di awal tunjukkan jam laptop ke kamera supaya
      video dan rekaman bisa disejajarkan.
- [ ] **Foto layar kendaraan**, keduanya:
      panel instrumen (odometer, SOC, jam) dan layar CarInfo
      (tegangan pack, arus, SOC, SOH, suhu baterai, suhu controller).
- [ ] Catat waktu foto itu diambil.

## B. Mulai merekam

```
cd /d D:\Wahyu\BMT\bmt-avanza-iot-testing
python tools\stream_capture.py --host <ip alat> --out captures\gelora-003
```

Baris pertama harus berbunyi `device recording to flash: paused`. Itu benar:
menulis ke flash internal justru membuang sekitar 15% frame, jadi selama
mengalirkan, perekaman flash dijeda.

**Perhatikan dua angka di layar selama merekam:**

| Angka | Artinya | Harus |
|---|---|---|
| `frames` dan `/s` | yang sudah tersimpan di laptop | naik terus, sekitar 600 per detik saat diam |
| `device dropped` | frame yang dibuang alat karena WiFi tidak mengejar | **tetap 0** |

Kalau `device dropped` mulai naik dan muncul `LINK TOO SLOW`, hentikan
(Ctrl+C), perbaiki posisi laptop, lalu mulai lagi. Rekaman berlubang tidak
layak dipakai membuktikan apa pun.

## C. Urutan berjalan

Jalankan berurutan, dan **sebutkan dengan suara** setiap pindah tahap supaya
pemegang laptop bisa mencatat waktunya.

| # | Tahap | Lama | Yang dibuktikan |
|---|---|---|---|
| 1 | Kontak ON, kendaraan diam | 60 detik | garis dasar, semua nilai diam |
| 2 | Kendaraan READY, masih diam | 60 detik | sinyal yang berubah hanya karena sistem siap |
| 3 | Jalan pelan, 10–20 km/jam | 2 menit | kecepatan, dan arus keluar dari 1000 |
| 4 | Berhenti penuh sekitar 30 detik | | kecepatan harus kembali ke nol |
| 5 | Akselerasi agak kuat sekali saja | | arus melonjak, tegangan sel turun sesaat |
| 6 | Pengereman regeneratif yang jelas | | arus **berbalik arah** |
| 7 | **Jalan lurus tepat 2 km** | | odometer naik tepat 2 |
| 8 | Berhenti, kontak tetap ON | 60 detik | suhu masih naik setelah pemakaian |

Selama tahap 7, catat odometer di awal dan di akhir. Itu bukti paling kuat dan
paling mudah diperiksa.

## D. Setelah berhenti

- [ ] **Foto lagi kedua layar** seperti di bagian A, sebelum kontak dimatikan.
- [ ] **Ctrl+C** di jendela perekam. Jangan menutup jendelanya langsung: Ctrl+C
      yang menutup berkas dengan rapi dan mengembalikan alat ke mode merekam.
- [ ] Baca baris terakhir. Harus berbunyi
      `no frames dropped by the device: the recording is complete`.
      Kalau ada peringatan, catat angkanya di lembar run.
- [ ] Salin folder `captures/gelora-003` ke penyimpanan lain **hari itu juga**.
      Rekaman perjalanan tidak bisa diulang dengan kondisi yang sama.

## E. Yang dicatat di lembar run

Tulis apa adanya, termasuk yang gagal:

```
tanggal, jam mulai, jam selesai
kendaraan, kilometer awal, kilometer akhir
SOC awal, SOC akhir
cuaca, suhu luar
siapa menyetir, siapa memegang laptop
foto: nama berkas untuk sebelum dan sesudah
kejadian: setiap Ctrl+C, setiap putus WiFi, setiap tahap yang dilewati
```

## F. Batas dan keselamatan

- Alat **tidak pernah mengirim** ke bus. Itu dijamin saat firmware dibangun,
  bukan saat berjalan, dan tidak ada tombol yang bisa mengubahnya.
- **Pengemudi tidak menyentuh laptop.** Kalau ada yang perlu diperiksa, berhenti
  dulu di tempat yang aman.
- **Colok dan cabut alat hanya saat kendaraan mati.**
- Kalau dashboard menyebut `Wrong bitrate, most likely`, berarti alat memakai
  firmware kendaraan lain. Hentikan, jangan lanjutkan.

## G. Setelah di meja

```
python tools\capture_to_webcan.py captures\gelora-003\can-*.log -o captures\gelora-003.csv
python tools\match_dashboard.py captures\gelora-003 --value <odometer akhir> --scales 1 0.1
```

Yang dicari: apakah keenam kandidat di `docs/evidence/dfsk-gelora-e/gelora-001.md` **bergerak
mengikuti** angka di foto. Kandidat yang tidak bergerak tetap dugaan, dan harus
dinyatakan begitu.

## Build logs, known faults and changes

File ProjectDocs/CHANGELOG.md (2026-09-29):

# CHANGELOG: Alat Diagnostik CAN BMT

Riwayat versi dokumen dan temuan. Terbaru di atas. Riwayat perubahan **kode** ada di
`git log`, dan tidak diduplikasi di sini.

## 2026-09-28/29: Firmware di-flash ke alat, argometer bilangan bulat

- **Argometer bilangan bulat, waktu tunggu jadi stopwatch.** `ArgoMeter` kini
  menagih jarak satu kilometer penuh sekaligus dan mengirim waktu tunggu mentah
  dalam milidetik (`wait_ms`, mengganti `wait_min`), supaya layar menjalankannya
  sebagai stopwatch dan menagihnya dari angka yang sama yang dipajang. Keputusan
  tarifnya ada di `project-mdt-tds` D-014.
- `tools/fake_device.py` mengikuti bentuk JSON baru.
- **Firmware dua dashboard di-flash ke alat sungguhan** untuk pertama kali
  (D-010). `unit=GELORAE-TEST-01`, hash terverifikasi, kedua halaman terbukti
  menjawab lewat WiFi.
- Tiga temuan operasional dicatat di D-010: 13,3 MB rekaman lama belum ditarik
  dari alat, perekaman menyala otomatis tiap boot, dan membuka port serial
  dengan cara naif memicu reset ESP32.
- Prosedur uji: `python tools/apply_notes.py --host <ip alat> ...` dijalankan
  ulang tidak diperlukan kali ini karena catatan identifier tidak berubah sejak
  sebelumnya, sudah 8 catatan tetap tersimpan di alat setelah flash.

## 2026-09-28: Dua dashboard di alat, alat tiruan, dan panel Vehicle dirombak

- **Decoder sinyal di firmware.** `src/SignalDecoder.cpp` memuat delapan pemetaan
  DFSK Gelora E yang berstatus terbukti. Sebelum ini firmware tidak punya decoder
  sama sekali: yang bernama `speed` di `src/` adalah kecepatan GPS dari NMEA, bukan
  kecepatan kendaraan dari CAN. Sinyal yang tidak pernah datang mengeluarkan `null`,
  bukan nol.
- **Alat menyajikan dua alamat.** `/` dashboard teknis, `/argo` layar SELARIDE
  (D-008). Boleh dibuka bersamaan dari dua gawai.
- **Argometer di alat.** Menghitung kuantitas saja, kilometer isi dan menit tunggu;
  rupiah dihitung halaman dari `tariff.js`. Jarak dari selisih odometer, bukan dari
  integral kecepatan. Tidak disimpan: reboot di tengah trip menghilangkan tarifnya,
  dan itu disengaja supaya filesystem berisi rekaman CAN tidak perlu ditulisi.
- **`tools/fake_device.py`.** Alat tiruan yang menyajikan kedua halaman dan setiap
  endpoint yang mereka minta, dengan satu kendaraan tiruan yang nilainya dikodekan
  kembali menjadi byte CAN seperti Gelora E mengirimnya. Panel Vehicle karena itu
  benar-benar menjalankan rumus dari `notes.tsv`, bukan menerima angka jadi.
- **Panel Vehicle membawa riwayatnya sendiri**, empat puluh detik per kartu,
  disimpan di halaman dan bukan di alat.
- **Panel Vehicle jadi cluster** mengikuti gambar acuan Direktur: cincin daya di
  tengah, odometer kiri, kecepatan kanan. Penempatan ditentukan satuan bacaan,
  bukan identifier (D-009).
- **Satu percobaan susunan ditarik kembali.** Acuan kedua sempat dibangun lalu
  ditolak operator dan dikembalikan lewat `git revert`. Rinciannya di D-009.
- Prosedur uji dua dashboard: `docs/PROSEDUR-TEST-2-DASHBOARD.md`.

## 2026-09-23: Dashboard menyaring tampilan, dan panel nilai kendaraan

- Tiga mode penyaring identifier di dashboard: TDS, Named, All. Menyaring **apa
  yang ditampilkan**, tidak pernah apa yang diterima atau direkam (D-006).
- Panel Vehicle: nilai kendaraan sebagai angka besar, dibangun dari catatan
  bertanda `#tds` yang memuat rumus. Tidak ada identifier yang ditulis di dalam
  kode halaman.
- Penanda `#tds` adalah awalan di teks catatan, jadi tanpa penyimpanan baru dan
  tanpa perubahan format berkas.
- `tools/apply_notes.py` memasang satu berkas catatan per kendaraan sekali
  jalan, menolak berkas yang ada catatannya melewati batas, dan mencetak echo
  dari alat bukan teks yang dikirim.
- `docs/evidence/dfsk-gelora-e/notes.tsv`: delapan nama siap pasang, lima
  bertanda `#tds`.
- Diluruskan di dokumen: penyaring ini **bukan** perbaikan untuk frame yang
  hilang. Penyebabnya interupsi CAN di flash, dan itu tidak tersentuh.
- D-007 mencatat arah berpindah ke Orange Pi 5, berstatus PROVISIONAL, dengan
  empat hal yang belum dijawab: daya dan kontak, waktu siap, suhu kabin, dan
  bagaimana jaminan listen-only ditegakkan di SocketCAN.

## 2026-09-23: Skeleton ProjectDocs dibuat

- `ProjectDocs/` lahir lewat `bmt-project-onboarding`, sepuluh berkas.
- Isinya **merutekan** ke `docs/` yang sudah ada, bukan menyalinnya. `docs/` tidak
  dipindah, sehingga rujukan dari `project-mdt-tds` dan dari commit lama tetap hidup.
- Lima keputusan repo ini dicatat untuk pertama kalinya, D-001 sampai D-005. Sebelumnya
  repo ini merujuk 24 kali ke `D-XXX` tanpa punya decision log sendiri.
- Tabel keputusan yang **diwarisi** dari `bmt-can-bus-telemetry` dan `project-mdt-tds`
  dibuat, karena `D-006` sudah berarti dua hal berbeda di dua repositori.
- D-005: project ini tanpa sprint, laporan disusun per milestone.

## 2026-09-23: Uji jalan DFSK Gelora E, pemetaan naik status jadi terbukti

- Uji jalan 47 menit, 1.525.681 frame dialirkan lewat WiFi.
- Terbukti: kecepatan, kecepatan halus 1/256 km/jam, odometer, SOC, arus, tegangan pack,
  suhu baterai, dan putaran motor.
- Arus terbukti lewat arah, yaitu +133 A lalu -36 A dalam satu detik saat pedal dilepas.
- Suhu controller turun kembali jadi dugaan, tidak bergerak sedetik pun.
- Dicatat apa adanya: tautan WiFi putus 30 kali, 14,9 % waktu sesi tidak terekam.
- `docs/evidence/dfsk-gelora-e/gelora-004.md`.

## 2026-09-22: DFSK Gelora E, kandidat sinyal pertama dari kendaraan listrik

- Bus terbaca di 250 kbps, seluruhnya identifier 29-bit extended bergaya J1939.
- Dua belas nilai dicocokkan ke layar kendaraan, semuanya masih statis.
- Temuan tentang kendaraan: paket baterai tidak seimbang, sel terendah sekitar 200 mV di
  bawah mayoritas, dan itu tidak terlihat dari layar mobil.
- Temuan tentang alat: interupsi CAN berada di flash, sehingga merekam ke flash sendiri
  membuang 14,8 % frame. Mengalirkan lewat WiFi menghapusnya.
- `docs/evidence/dfsk-gelora-e/gelora-001.md`, `docs/evidence/00-umum/frame-loss.md`,
  `docs/evidence/dfsk-gelora-e/TESTING-2026-09-22.md`.

## 2026-09-20: Rancangan papan sirkuit rev A

- Skematik, netlist, dan BOM dibangkitkan dari satu berkas sumber tunggal.
- Pemeriksa terpisah membaca hasilnya kembali dan menguji 12 aturan keselamatan, diuji
  dengan tiga cacat yang sengaja disuntikkan.
- `hardware/README.md` §10 merekomendasikan slot microSD untuk rev B.

## 2026-09-08: Honda HR-V 2023, pengujian kendaraan pertama

- Alat terbukti bisa membaca bus kendaraan sungguhan di 500 kbps.
- Listen-only bertahan di kendaraan hidup.
- Kandidat sinyal dicatat, belum pernah diuji sambil berjalan.
- `docs/evidence/honda-hrv-2023/hrv-001.md`, `hrv-001-candidates.md`.

## 2026-09-06: Repo dimulai

- Firmware bring-up ESP32-S3 dengan SN65HVD230, dipisah dari firmware armada yang
  dibekukan.
- Penegakan listen-only tiga lapis sejak commit pertama.

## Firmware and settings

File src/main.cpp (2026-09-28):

// =============================================================================
//  Avanza CAN Bring-Up — PT Bali Mikro Teknologi
//
//  Diagnostic firmware for milestone M1C-ALT: prove that an ESP32-S3 with an
//  SN65HVD230 can passively read a real vehicle CAN bus, and show it live on a
//  phone over a WiFi hotspot.
//
//  ---------------------------------------------------------------------------
//  THE DEVICE IS LISTEN-ONLY, PERMANENTLY.
//
//  It reads the vehicle CAN bus and never writes to it — no data frames, no
//  remote frames, no ACK, no error frames. Enforced in three places:
//
//    1. the TWAI driver is installed with TWAI_MODE_LISTEN_ONLY and CanManager
//       refuses to start in any other mode;
//    2. CanBusSafety.h poisons the transmit entry points, so a call fails to
//       compile;
//    3. tools/check_listen_only.sh greps for both before a release build.
//  ---------------------------------------------------------------------------
//
//  WHAT THIS FIRMWARE IS NOT: it is not the fleet firmware. There is no modem,
//  no MQTT, no TLS, no offline buffer, no GNSS, and no signal decoding. Those
//  live in bligede/bmt-can-bus-telemetry. Every subsystem left out here is one
//  fewer variable when the answer turns out to be "no frames".
//
//  Avanza CAN IDs discovered with this tool prove the READING PATH. They are
//  not a signal map for the fleet vehicle and must never be treated as one.
//
//  Build with PlatformIO — see README.md.
// =============================================================================

#include <Arduino.h>
#include <LittleFS.h>
#include <freertos/FreeRTOS.h>
#include <freertos/task.h>
#include <freertos/queue.h>

#include "Config.h"
#include "Logger.h"
#include "CanManager.h"
#include "SignalDecoder.h"
#include "RawCanLogger.h"
#include "WifiManager.h"
#include "WebDashboard.h"
#include "SerialConsole.h"
#include "StatusLed.h"
#include "SystemHealth.h"
#include "NotesStore.h"
#include "FrameStream.h"
#include "WatchdogManager.h"
#include "GpsManager.h"
#include "EnvironmentManager.h"
#include "FanManager.h"
#include "ButtonManager.h"

static QueueHandle_t q_rawlog = nullptr;

// =============================================================================
//  CORE 0 — the only thing that runs there: read CAN.
//
//  It performs no filesystem I/O, no network I/O, and holds no lock that a
//  core 1 task can take. If everything on core 1 stalled, this would keep
//  receiving until the watchdog fired.
// =============================================================================
static void taskCanReader(void*) {
    WatchdogManager::subscribeCurrentTask("can_reader");
    LOG_I("CAN", "Reader task running on core %d", xPortGetCoreID());

    CanFrame frame;
    uint32_t queue_full_drops = 0;

    for (;;) {
        WatchdogManager::feed();
        CanManager::poll();

        // The 50 ms timeout keeps this task responsive to the watchdog on a
        // silent bus. It is not a poll interval — a frame wakes the task at
        // once.
        if (!CanManager::receive(&frame, 50)) continue;

        CanManager::survey(frame);

        // Named values off the bus, for both dashboards. A table lookup and at
        // most four stores; it runs here rather than on core 1 so the reading
        // is stamped with the frame's own arrival time and never waits behind
        // a filesystem write.
        SignalDecoder::feed(frame);

        // Best-effort hand-off to core 1. Losing a line from the capture file
        // is acceptable; the bus itself is unaffected and `rx` on the dashboard
        // still counts every frame received.
        if (q_rawlog != nullptr && xQueueSend(q_rawlog, &frame, 0) != pdTRUE) {
            RawCanLogger::noteQueueDrop();
            if ((++queue_full_drops % 500) == 1) {
                LOG_W("CAN", "Log queue full — %lu frames not written to the "
                             "capture (bus reception is unaffected)",
                      (unsigned long)queue_full_drops);
            }
        }
    }
}

// =============================================================================
//  CORE 1 — storage: capture writes and the dashboard's frame ring.
// =============================================================================
static void taskStorage(void*) {
    WatchdogManager::subscribeCurrentTask("storage");
    LOG_I("RAWLOG", "Storage task running on core %d", xPortGetCoreID());

    CanFrame frame;
    for (;;) {
        WatchdogManager::feed();
        // Depth is sampled just before each receive, when the queue is fullest.
        SystemHealth::noteQueueDepth(uxQueueMessagesWaiting(q_rawlog), CAN_RAWLOG_QUEUE_LEN);
        if (xQueueReceive(q_rawlog, &frame, pdMS_TO_TICKS(200)) == pdTRUE) {
            RawCanLogger::write(frame);
            FrameStream::write(frame);
            WebDashboard::noteFrame(frame);
        }
        // Accepting a receiver and flushing the socket happen on THIS task, the
        // only one that writes frames into the stream. One owner, no races.
        FrameStream::poll();
    }
}

// =============================================================================
//  CORE 1 — GNSS.
//
//  Above storage in priority: a dropped NMEA byte is unrecoverable, because the
//  UART buffer overruns and the sentence is lost. A delayed capture write is
//  not — the queue absorbs it.
// =============================================================================
#if ENABLE_GPS
static void taskGps(void*) {
    WatchdogManager::subscribeCurrentTask("gps");
    LOG_I("GPS", "Task running on core %d", xPortGetCoreID());

    for (;;) {
        WatchdogManager::feed();
        GpsManager::poll();
        vTaskDelay(pdMS_TO_TICKS(50));
    }
}
#endif

// =============================================================================
//  CORE 1 — housekeeping: console, LED, WiFi, environment, fan, button.
// =============================================================================
static void taskHousekeeping(void*) {
    WatchdogManager::subscribeCurrentTask("housekeeping");
    LOG_I("SYSTEM", "Housekeeping task running on core %d", xPortGetCoreID());

    uint32_t last_report = 0;
    uint32_t last_slow   = 0;

    for (;;) {
        WatchdogManager::feed();
        vTaskDelay(pdMS_TO_TICKS(LED_TICK_MS));
        SystemHealth::noteLoop();

        StatusLed::tick();
        SerialConsole::poll();
        WifiManager::poll();

        // GPIO0 is RESERVED: it reports, it never reconfigures anything.
        if (ButtonManager::poll() == ButtonEvent::ShortPress) {
            SerialConsole::printStatus();
        }

        const uint32_t nowMs = millis();
        if (nowMs - last_slow >= 1000) {
            last_slow = nowMs;
            EnvironmentManager::poll();   // rate-limited internally
            FanManager::poll();
            SystemHealth::sample();       // HEALTH_SAMPLE_MS is this same second
        }

        // ---- LED mapping for this diagnostic build --------------------------
        // StatusLed is copied verbatim from the fleet firmware, so the state
        // NAMES below are the fleet's. What each one MEANS here is defined by
        // this mapping and by the table in README.md.
        //
        // The rule: RED means something is broken. It does NOT mean "waiting".
        // An earlier version lit CanError whenever no frames were arriving,
        // which on a bench with no bus attached is always — so the LED sat
        // solid red and told you nothing about WiFi or GPS. Now "no frames
        // yet" falls through to the WiFi/GPS states, and red is reserved for a
        // CAN driver that actually failed.
        //
        // Highest priority wins:
        //   SystemError     filesystem dead        solid red
        //   CanError        CAN driver down        fast red blink
        //   CanOk           CAN frames arriving    green heartbeat
        //   GpsNoFix        GPS talking, no fix    green + red wink
        //   ModemConnecting WiFi connecting        fast green blink
        //   NetworkOk       WiFi up, no CAN yet    slow green blink
        const bool can_up   = CanManager::state() == CanState::Running;
        const bool can_live = can_up && CanManager::isAlive();
        const WifiState ws  = WifiManager::state();
        const bool wifi_try = (ws == WifiState::Connecting ||
                               ws == WifiState::Reconnecting);
        // "GPS talking" = sentences have been seen. A module that is not wired
        // at all should not claim a GPS fault; it simply never appears.
        const bool gps_talking = ENABLE_GPS && !GpsManager::isSilent() &&
                                 GpsManager::stats().sentences_ok > 0;

        StatusLed::set(LedStatus::Boot,            false);
        StatusLed::set(LedStatus::CanError,        !can_up);
        StatusLed::set(LedStatus::CanOk,           can_live);
        StatusLed::set(LedStatus::GpsNoFix,        gps_talking &&
                                                   !GpsManager::hasFreshFix());
        StatusLed::set(LedStatus::ModemConnecting, wifi_try);
        StatusLed::set(LedStatus::NetworkOk,       WifiManager::isConnected());

        // Wall clock, requested once the link is up.
        //
        // Every timestamp in the capture is millis() since boot. Matching those
        // against a run sheet that says "16:42:10 brake pressed" otherwise means
        // guessing an offset, and every reboot invalidates the guess. SNTP comes
        // from the Arduino core, not a library; the capture header records the
        // resulting boot epoch so the whole file can be converted afterwards.
        static bool s_sntp_asked = false;
        if (!s_sntp_asked && WifiManager::isConnected()) {
            s_sntp_asked = true;
            configTime(0, 0, "pool.ntp.org", "time.google.com");
            LOG_I("TIME", "SNTP requested (UTC)");
        }

        const uint32_t now = millis();
        if (now - last_report >= 30000) {
            last_report = now;
            SerialConsole::printStatus();
        }
    }
}

// =============================================================================
//  CORE 1 — the dashboard, at the lowest priority. A technician refreshing a
//  page must never delay anything else.
// =============================================================================
#if ENABLE_WEB_DASHBOARD
static void taskWeb(void*) {
    WatchdogManager::subscribeCurrentTask("web");
    LOG_I("WEB", "Dashboard task running on core %d", xPortGetCoreID());

    for (;;) {
        WatchdogManager::feed();
        WebDashboard::poll();
        vTaskDelay(pdMS_TO_TICKS(WEB_POLL_TICK_MS));
    }
}
#endif

// =============================================================================
//  setup
// =============================================================================
void setup() {
    Logger::begin(LOG_BAUD);
    SystemHealth::begin();              // idle hooks, before any task exists

    LOG_I("BOOT", "%s %s", FW_NAME, FW_VERSION);
    LOG_I("BOOT", "Chip %s rev %d, %d MHz, %lu KB flash",
          ESP.getChipModel(), ESP.getChipRevision(), ESP.getCpuFreqMHz(),
          (unsigned long)(ESP.getFlashChipSize() / 1024));
    LOG_I("BOOT", "Heap %lu B", (unsigned long)ESP.getFreeHeap());
    LOG_I("BOOT", "----------------------------------------------------");
    LOG_I("BOOT", "CAN MODE: LISTEN ONLY (permanent, enforced at build time)");
    LOG_I("BOOT", "This device never transmits to the vehicle bus.");
    LOG_I("BOOT", "----------------------------------------------------");
    LOG_W("BOOT", "DIAGNOSTIC FIRMWARE — bring-up only.");
    LOG_W("BOOT", "Not the fleet firmware. No modem, no MQTT, no decoding.");
    LOG_W("BOOT", "----------------------------------------------------");

    StatusLed::begin();
    SerialConsole::begin();
    ButtonManager::begin();

    // --- Filesystem ---------------------------------------------------------
    // Mounted before CAN so the capture can start with the very first frame.
    LOG_I("BOOT", "Mounting LittleFS...");
    const bool fsOk = LittleFS.begin(true);   // true = format if the mount fails
    if (fsOk) {
        LOG_I("BOOT", "LittleFS %lu KB total, %lu KB used",
              (unsigned long)(LittleFS.totalBytes() / 1024),
              (unsigned long)(LittleFS.usedBytes() / 1024));
    } else {
        LOG_E("BOOT", "LittleFS mount FAILED — file capture unavailable. "
                      "CAN reading continues.");
        StatusLed::set(LedStatus::SystemError, true);
    }

    // --- CAN, locked in listen-only ----------------------------------------
    const bool canOk = CanManager::begin(CAN_DEFAULT_BITRATE);
    if (!canOk) {
        LOG_E("BOOT", "CAN did not start — check wiring, bitrate, and whether "
                      "the transceiver module's 120R terminator is correct for "
                      "this stage (bench: keep it; vehicle: remove it)");
        StatusLed::set(LedStatus::CanError, true);
    }

    RawCanLogger::begin(fsOk ? RawCanLogger::restoreSink(RAWLOG_DEFAULT_SINK)
                             : RAWLOG_SINK_NONE);
    NotesStore::begin(fsOk);

    // --- Queue + core 0 task, as early as possible --------------------------
    q_rawlog = xQueueCreate(CAN_RAWLOG_QUEUE_LEN, sizeof(CanFrame));
    if (q_rawlog == nullptr) {
        LOG_E("BOOT", "Cannot allocate the log queue — restarting");
        delay(1000);
        ESP.restart();
    }

    TaskHandle_t hCan = nullptr;
    xTaskCreatePinnedToCore(taskCanReader, "can_reader", TASK_CAN_READER_STACK,
                            nullptr, TASK_CAN_READER_PRIO, &hCan, CORE_REALTIME);
    SystemHealth::watchTask(hCan, "can_reader", TASK_CAN_READER_STACK, CORE_REALTIME);
    LOG_I("BOOT", "CAN acquisition is running. Everything below is optional to it.");

    // --- Auxiliary sensors --------------------------------------------------
    // All optional to CAN. A dead GPS or an unplugged DHT22 clears its own
    // reading and touches nothing else.
    GpsManager::begin();
    EnvironmentManager::begin();
    FanManager::begin();

    // --- WiFi + dashboard ---------------------------------------------------
    // Started after CAN so the radio never competes with driver installation,
    // and so a WiFi failure can never delay acquisition.
    WifiManager::begin();
#if ENABLE_WEB_DASHBOARD
    WebDashboard::begin();
    FrameStream::begin();
#endif

    // --- Core 1 tasks -------------------------------------------------------
#if ENABLE_GPS
    TaskHandle_t hGps = nullptr;
    xTaskCreatePinnedToCore(taskGps, "gps", TASK_GPS_STACK,
                            nullptr, TASK_GPS_PRIO, &hGps, CORE_COMMS);
    SystemHealth::watchTask(hGps, "gps", TASK_GPS_STACK, CORE_COMMS);
#endif
    TaskHandle_t hStorage = nullptr, hHouse = nullptr;
    xTaskCreatePinnedToCore(taskStorage, "storage", TASK_STORAGE_STACK,
                            nullptr, TASK_STORAGE_PRIO, &hStorage, CORE_COMMS);
    SystemHealth::watchTask(hStorage, "storage", TASK_STORAGE_STACK, CORE_COMMS);
    xTaskCreatePinnedToCore(taskHousekeeping, "housekeeping",
                            TASK_HOUSEKEEPING_STACK, nullptr,
                            TASK_HOUSEKEEPING_PRIO, &hHouse, CORE_COMMS);
    SystemHealth::watchTask(hHouse, "housekeeping", TASK_HOUSEKEEPING_STACK, CORE_COMMS);
#if ENABLE_WEB_DASHBOARD
    TaskHandle_t hWeb = nullptr;
    xTaskCreatePinnedToCore(taskWeb, "web", TASK_WEB_STACK,
                            nullptr, TASK_WEB_PRIO, &hWeb, CORE_COMMS);
    SystemHealth::watchTask(hWeb, "web", TASK_WEB_STACK, CORE_COMMS);
#endif

    WatchdogManager::begin();

    LOG_I("SYSTEM", "READY");
    LOG_I("SYSTEM", "CAN=%s fs=%s capture=%s",
          canOk ? "OK" : "FAIL", fsOk ? "OK" : "FAIL",
          RawCanLogger::isCapturing() ? "ON" : "OFF");
    LOG_I("SYSTEM", "Type 'help' on this console. Dashboard URL appears once "
                    "WiFi connects.");
}

// =============================================================================
//  loop — deliberately empty.
//
//  Every responsibility belongs to a pinned FreeRTOS task with an explicit core
//  and priority. Work placed here would run at priority 1 on core 1 with no
//  watchdog supervision.
// =============================================================================
void loop() {
    vTaskDelay(pdMS_TO_TICKS(1000));
}

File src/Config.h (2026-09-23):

// =============================================================================
//  Config.h — every tunable for the Avanza bring-up firmware.
//
//  This is a DIAGNOSTIC build. It exists to answer one question:
//
//      Can an ESP32-S3 + SN65HVD230 passively read a real vehicle CAN bus?
//
//  It is not the fleet firmware. There is no modem, no MQTT, no TLS, no offline
//  buffer and no signal decoding — those live in bligede/bmt-can-bus-telemetry
//  and are deliberately absent, because every subsystem left out is one fewer
//  variable when the answer turns out to be "no frames".
//
//  GNSS, DHT22 and the fan ARE here. They are passive, sit on core 1 at low
//  priority, and touch the CAN path not at all — so the "fewer variables"
//  argument does not apply to them, while each retires an item from the fleet
//  project's NOT TESTED list.
//
//  Credentials live in Secrets.h, which is git-ignored.
// =============================================================================
#pragma once

#define FW_NAME         "Avanza CAN Bring-Up"
#define FW_VERSION      "0.1.0"

// -----------------------------------------------------------------------------
// 1. IDENTITY
// -----------------------------------------------------------------------------
// The vehicle actually under test, chosen by the PlatformIO env (see the end of
// platformio.ini). It is written into every capture header and names the notes
// folder, so it must be right BEFORE a run starts (D-015).
#if defined(VEHICLE_HRV)
  #define UNIT_ID       "HRV-TEST-01"
#elif defined(VEHICLE_GELORA_E)
  #define UNIT_ID       "GELORAE-TEST-01"
#else
  #error "No vehicle selected. Build with an env from platformio.ini, e.g. pio run -e gelora-e"
#endif

// -----------------------------------------------------------------------------
// 2. PIN MAP — SN65HVD230 transceiver
//    Same pins as the fleet device, so wiring notes transfer directly.
// -----------------------------------------------------------------------------
#define CAN_TX_PIN      5      // SN65HVD230 pin D  (never driven: listen-only)
#define CAN_RX_PIN      4      // SN65HVD230 pin R

// GNSS — GY-GPS6MV2 (u-blox NEO-6M), NMEA 0183
#define GPS_RX_PIN      18     // ESP32 RX  <- GPS TX   (the only one needed)

// ESP32 TX -> GPS RX. -1 = NOT CONNECTED, and that is the right default.
//
// Two reasons. First, this firmware only listens to NMEA; it never configures
// the receiver, so the pin does no work. Second, the blueprint pinout puts it
// on GPIO19 — which on the ESP32-S3 is USB_D- of the native USB peripheral.
// Assigning a UART to it while the native USB port is in use puts two
// peripherals on one pin, and the symptom looks like a broken GPS module
// rather than a pin conflict.
//
// Only set this to 19 if you are certain the native USB port is unused (i.e.
// ARDUINO_USB_CDC_ON_BOOT=0 and you are on the COM port) AND you actually need
// to send configuration to the receiver.
#define GPS_TX_PIN      -1

#define DHT_PIN         15     // DHT22 DATA
#define FAN_PIN         13     // 330R -> IRLZ44N gate

#define LED_RED_PIN     21
#define LED_GREEN_PIN   47
#define BUTTON_PIN      0      // RESERVED — status display only

// -----------------------------------------------------------------------------
// 3. CAN
// -----------------------------------------------------------------------------
// 500000 or 250000. A vehicle env may override it (platformio.ini). Decide on the
// bench, flash once. Do NOT switch bitrates repeatedly while connected to a live
// vehicle.
#ifndef CAN_DEFAULT_BITRATE
  #define CAN_DEFAULT_BITRATE   500000
#endif

// Frames the TWAI driver may hold before the reader task takes them. It only
// covers the reader being late; it CANNOT cover the hardware FIFO overrunning,
// which is what happens while flash is written (see docs/evidence/00-umum/frame-loss.md).
#define CAN_RX_QUEUE_LEN        256
// Deep enough to ride out a filesystem stall. At ~1,300 frames/s a 256-slot
// queue overflows after 200 ms of the writer being busy, which is well within
// what LittleFS takes to do wear-levelling bookkeeping. 1024 slots is ~20 KB
// of internal RAM against 17.9% used, and buys 800 ms.
#define CAN_RAWLOG_QUEUE_LEN    1024
#define CAN_SILENCE_TIMEOUT_MS  5000

// --- SAFETY ------------------------------------------------------------------
// Listen-only is compiled in, latched at init, and re-asserted on recovery.
// There is deliberately no symbol that disables it, and CanBusSafety.h makes a
// transmit call fail to compile.
//
// Optional belt-and-braces: leave the TWAI TX pin entirely unconfigured so the
// SoC cannot drive the transceiver's D input under any fault. Listen-only never
// needs TX. Pull GPIO5 high at the transceiver if you enable this.
#define CAN_DETACH_TX_PIN       0
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

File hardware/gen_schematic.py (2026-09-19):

#!/usr/bin/env python3
"""
gen_schematic.py - the BMT CAN logger board, as data.

This file is the single source of truth for the circuit. It writes:

    bmt-can-logger.kicad_sch   KiCad 7 schematic (EasyEDA Pro: File > Import > KiCad)
    bmt-can-logger.kicad_pro   minimal project file so KiCad opens it as a project
    netlist.csv                net -> ref.pin, for review and for manual entry
    bom.csv                    what to buy and solder

Edit PARTS below, run this, then run verify_schematic.py. Never edit the
generated files by hand: the next run overwrites them.

Connections are made with net labels on short wire stubs, not drawn wires.
Every pin that is not used carries an explicit no-connect flag, so "forgotten"
and "deliberately unused" can be told apart.

One board, two roles:
  - test device   fit everything except the MODEM section
  - fleet unit    fit the MODEM section too
"""

import csv
import json
import uuid
from pathlib import Path

HERE = Path(__file__).resolve().parent
NAME = "bmt-can-logger"
NS = uuid.UUID("6f1c2d4e-0b7a-4c1e-9a55-3b1f0e2d7c90")   # stable uuids across runs
G = 2.54


def uid(*parts):
    return str(uuid.uuid5(NS, "/".join(str(p) for p in parts)))


def f(v):
    """Coordinates are multiples of 1.27 mm; print them without float noise."""
    s = f"{round(v, 4):.4f}".rstrip("0").rstrip(".")
    return "0" if s in ("-0", "") else s


# --------------------------------------------------------------------------
# Symbols
#
# Box symbols: pins on the left and right, 2.54 mm pitch, pin length 2.54.
# Two-pin symbols: pin 1 left, pin 2 right, except diodes (KiCad convention:
# pin 1 = cathode, drawn on the right).
# --------------------------------------------------------------------------

FONT = "(effects (font (size 1.27 1.27)))"
FONT_HIDE = "(effects (font (size 1.27 1.27)) hide)"


class Sym:
    def __init__(self, name, pins, body, ref_prefix, hide_pin_text=False, box=None):
        self.name = name
        self.pins = pins            # list of (number, pin_name, x, y, angle)
        self.body = body            # list of graphic s-expressions
        self.ref_prefix = ref_prefix
        self.hide_pin_text = hide_pin_text
        self.box = box              # (half_w, top, bottom) for property placement

    def pin_xy(self, number):
        for n, _, x, y, a in self.pins:
            if n == number:
                return x, y, a
        raise KeyError(f"{self.name} has no pin {number}")

    def lib_sexpr(self):
        pn = "(pin_names (offset 0) hide) (pin_numbers hide)" if self.hide_pin_text \
            else "(pin_names (offset 1.016))"
        out = [f'    (symbol "bmt:{self.name}" {pn} (in_bom yes) (on_board yes)',
               f'      (property "Reference" "{self.ref_prefix}" (at 0 0 0) {FONT})',
               f'      (property "Value" "{self.name}" (at 0 0 0) {FONT})',
               f'      (property "Footprint" "" (at 0 0 0) {FONT_HIDE})',
               f'      (property "Datasheet" "" (at 0 0 0) {FONT_HIDE})',
               f'      (symbol "{self.name}_0_1"']
        out += [f"        {b}" for b in self.body]
        out.append("      )")
        out.append(f'      (symbol "{self.name}_1_1"')
        for n, nm, x, y, a in self.pins:
            out.append(f'        (pin passive line (at {f(x)} {f(y)} {a}) (length 2.54) '
                       f'(name "{nm}" {FONT}) (number "{n}" {FONT}))')
        out.append("      )")
        out.append("    )")
        return "\n".join(out)


def stroke(w=0.254):
    return f"(stroke (width {w}) (type default))"


def box_symbol(name, left, right, ref_prefix, width=15.24):
    """left/right: lists of (number, pin_name); None leaves a gap row."""
    rows = max(len(left), len(right))
    half_w = width / 2
    top = G * ((rows + 1) // 2)           # a multiple of G keeps every pin on grid
    bottom = top - G * (rows + 1)
    pins = []
    for side, lst in (("L", left), ("R", right)):
        for i, p in enumerate(lst):
            if p is None:
                continue
            y = top - G * (i + 1)
            if side == "L":
                pins.append((p[0], p[1], -(half_w + G), y, 0))
            else:
                pins.append((p[0], p[1], half_w + G, y, 180))
    body = [f"(rectangle (start {f(-half_w)} {f(top)}) (end {f(half_w)} {f(bottom)}) "
            f"{stroke()} (fill (type background)))"]
    return Sym(name, pins, body, ref_prefix, box=(half_w, top, bottom))


def two_pin(name, ref_prefix, body, diode=False):
    if diode:   # pin 2 = anode on the left, pin 1 = cathode on the right
        pins = [("2", "A", -5.08, 0, 0), ("1", "K", 5.08, 0, 180)]
    else:
        pins = [("1", "~", -5.08, 0, 0), ("2", "~", 5.08, 0, 180)]
    return Sym(name, pins, body, ref_prefix, hide_pin_text=True, box=(2.54, 1.27, -1.27))


def pl(*pts, w=0.254):
    xy = " ".join(f"(xy {f(x)} {f(y)})" for x, y in pts)
    return f"(polyline (pts {xy}) {stroke(w)} (fill (type none)))"


LEADS = [pl((-2.54, 0), (-1.27, 0)), pl((1.27, 0), (2.54, 0))]

SYMBOLS = {
    "R": two_pin("R", "R", [f"(rectangle (start -2.54 1.016) (end 2.54 -1.016) {stroke()} (fill (type none)))"]),
    "C": two_pin("C", "C", [pl((-0.508, 1.524), (-0.508, -1.524)), pl((0.508, 1.524), (0.508, -1.524)),
                            pl((-2.54, 0), (-0.508, 0)), pl((0.508, 0), (2.54, 0))]),
    "CP": two_pin("CP", "C", [pl((-0.508, 1.524), (-0.508, -1.524)),
                              f"(rectangle (start 0.508 1.524) (end 1.016 -1.524) {stroke()} (fill (type outline)))",
                              pl((-2.54, 0), (-0.508, 0)), pl((1.016, 0), (2.54, 0)),
                              pl((-1.778, 1.778), (-1.778, 0.762)), pl((-2.286, 1.27), (-1.27, 1.27))]),
    "L": two_pin("L", "L", [f"(rectangle (start -2.54 0.762) (end 2.54 -0.762) {stroke()} (fill (type outline)))"]),
    "D": two_pin("D", "D", [pl((-1.27, 1.27), (-1.27, -1.27), (1.27, 0), (-1.27, 1.27)),
                            pl((1.27, 1.27), (1.27, -1.27))] + LEADS, diode=True),
    "TVS": two_pin("TVS", "D", [pl((-1.27, 1.27), (-1.27, -1.27), (1.27, 0), (-1.27, 1.27)),
                                pl((0.762, 1.27), (1.27, 1.27), (1.27, -1.27), (1.778, -1.27))] + LEADS, diode=True),
    "PTC": two_pin("PTC", "F", [f"(rectangle (start -2.54 0.762) (end 2.54 -0.762) {stroke()} (fill (type none)))",
                                pl((-1.778, -1.524), (1.27, 1.524), (2.032, 1.524))]),
    "TP": Sym("TP", [("1", "~", -3.81, 0, 0)],
              [f"(circle (center 0 0) (radius 1.27) {stroke()} (fill (type none)))"],
              "TP", hide_pin_text=True, box=(1.27, 1.27, -1.27)),
}


def box(name, ref, left, right, width=15.24):
    SYMBOLS[name] = box_symbol(name, left, right, ref, width)
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

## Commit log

2026-09-06 Avanza CAN bring-up firmware — PlatformIO project
    Focused diagnostic firmware for the Avanza test, in its own repository. Not a
    subset of the fleet product: there is no modem, no MQTT, no TLS, no offline
    buffer, no GNSS and no signal decoding. Every subsystem left out is one fewer
    variable when the answer turns out to be "no frames".
    The listen-only guarantee carries over intact. CanManager, CanBusSafety,
    RawCanLogger, Logger, StatusLed, WatchdogManager and WifiManager are copied
    unmodified from bmt-can-bus-telemetry@7586b27, so the safety behaviour is
    identical rather than reimplemented. The provenance and the instruction to fix
    upstream and re-copy rather than diverge are recorded in th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
    [avanza_test.csv, avanza_test_4mb.csv]
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2026-09-06 Fix flash size, GPIO19 conflict and upload path; first hardware run
    Compiled, flashed and booted on real hardware. 14 sources, 0 warnings, 0 errors
    at -Wall -Wextra. RAM 17.8%, flash 38.2%. All four M1A acceptance lines (D-003)
    are emitted verbatim and listen-only reports LOCKED.
    Five defects surfaced by putting it on a board. None would have been found by
    reading the code.
    Flash was configured as 8 MB on a 16 MB chip. esptool flash_id reported 16 MB
    with 8 MB embedded PSRAM; the partition table spanned only half the device, so
    captures had ~6 MB instead of ~14 MB. Added avanza_test_16mb.csv, arithmetic
    verified. LittleFS now reports 14272 KB and RAWLOG_MAX_BYTES rises to 12 MB.
    PSRAM is l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
    [avanza_test_16mb.csv]
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2026-09-06 Count raw GPS bytes; the old counters could not tell dead from misconfigured
    Trying to diagnose a GPS module that reported "no data" exposed a defect in the
    instrument rather than the module.
    GpsManager counted only GGA/RMC sentences and bad checksums. Everything else -
    a module at the wrong baud emitting garbage, or one configured for GSV/GSA/VTG
    only - landed in the parser's Ignored bucket and was counted nowhere. The
    result read sentences=0, badcrc=0: byte-for-byte identical to a module that is
    not wired at all. On that basis I told the user there was no electrical signal.
    I could not actually have known that.
    GpsStats now carries bytes_received and lines_seen, counted before any
    interp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
    [GpsManager.cpp, SerialConsole.cpp]
2026-09-06 Make GPS silence detection rate-based; badge and diagnostic no longer disagree
    The dashboard was reporting SEARCHING for a module that had produced one byte
    in twelve minutes. That is not searching. It is a floating input picking up a
    spurious edge.
    isSilent() returned false as soon as a single byte had ever arrived, so one
    noise byte flipped the module from "not connected" to "searching" permanently.
    The badge read SEARCHING while the diagnostic line directly underneath it said
    "only 1 byte - that is line noise, not a module". Two halves of one panel
    contradicting each other is worse than either message alone.
    This is the same mistake twice. Last commit fixed the wording of the
    diagnostic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
    [GpsManager.cpp, SerialConsole.cpp]
2026-09-06 Redesign the dashboard around the BMT identity
    The page was a dark monospace card grid. It is read on a phone inside a car
    in daylight, where a dark surface loses to glare, so the surface is now bone
    with charcoal text. #00E640 on bone is about 1.8:1, so green is never text
    here: it is a fill carrying charcoal text, a rule, or the mark.
    The header carries the BMT mark and wordmark. The mark is three parallel bars
    whose slits are the header ground showing through, which is how the real logo
    is built — a single-colour mark stays legible at 34px. This is a reproduction
    from the raster assets on balimicrotechnology.com; the site publishes no
    vector, so swap it if an official SVG exists.
    Four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
2026-09-06 Dark theme, with the mark traced from the supplied logo file
    The operator asked for dark. Both colours now come from BMT.png itself rather
    than from the website CSS: green #04FB2D and dark #373435. The greys are warm,
    carrying the hue of the logo dark instead of a neutral grey, so the mark sits
    in the page rather than on it.
    This inverts the constraint the light build was designed around. There, green
    on bone was about 1.8:1 and could never be text. On #141314 it reaches about
    12:1, so green is legible as text here. It is still spent sparingly — the
    mark, the share bars, one rule, and badges meant to be found at a glance —
    because a page of green on black is a novelty, not an instrument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
2026-09-07 Fix the DHT22 driver: it was reading every frame one bit out of step
    The sensor was never faulty. The dashboard said "Sensor never answers" and I
    repeated it; both were wrong, and neither was a claim the counters could
    support, because read_errors lumped every failure together.
    Splitting it by stage answered the question in one read: idle high, no-response
    0, handshake 0 — the part was replying perfectly every time. Two real bugs were
    sitting behind that.
    1. The fortieth bit was always lost. Bit values were taken by timing the
    falling edge, and after the last bit the sensor releases the bus, so for
    that one bit no falling edge is coming and the wait always timed out. 39 of
    40 bi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
    [EnvironmentManager.cpp]
2026-09-07 Parse GSV, and put the whole LED legend on the dashboard
    Two things the page could not answer, both asked by the operator.
    GSV. Asked whether the GNSS module needed 5 V instead of 3.3 V, the honest
    answer was that the firmware could not tell: sats in GGA is satellites USED in
    a fix, so it reads zero whenever there is no fix and says nothing about
    reception. The number that answers it is in GSV — satellites in view and the
    carrier-to-noise on each — and the parser was discarding those sentences. The
    module was already sending them: 5,826 of 8,713 lines were GSV, GSA or VTG, so
    this needed no reconfiguration of the receiver at all.
    The parser now reports sats_in_view, how many are actual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
    [GpsManager.cpp]
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2026-09-08 Document the capture run procedure
    A recording of somebody driving normally is close to useless: forty identifiers
    change at once and nothing says which change belongs to which cause. What makes
    a capture analysable is the opposite — one thing changes, everything else stays
    still, and you know exactly when. The procedure exists to manufacture those
    windows.
    Three rules carry most of the value: a quiet gap after every action, values HELD
    rather than swept through, and every action called aloud on camera so the video
    becomes the annotation track. The five-brake-press sync marker ties the video
    clock to the capture's millis() timestamps.
    Phase A is the one that will get skipped and should n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
2026-09-08 Fix F-01, F-05 and F-14 from the bring-up review
    F-01 — the identifier table was losing about 47% of traffic silently. The
    review's arithmetic was right and every hypothesis about the cause was wrong.
    The survey holds 128, not 40, and never evicts. What actually happened: the
    state JSON filled up, appendIds stopped early, and the page reported the
    surviving row count as the identifier total. That is why "identifiers" sat at
    exactly 40 across three snapshots while its membership changed.
    The authoritative count already existed — CanStats::unique_ids_seen — and was
    simply never sent. It now goes out in the first object written, so it survives
    a truncation that cuts the array below it, a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
    [CanManager.cpp, Config.h, main.cpp]
2026-09-09 Catat masukan rekan BMT soal CAN, dan koreksi dua prasyarat yang sudah basi
    docs/CAN-REFERENCES.md. Bukan daftar tautan — kolom yang penting adalah apa
    yang berubah di kode kita, dan rujukan yang tidak mengubah apa pun dikatakan
    begitu.
    Tiga hal dari masukan itu berdiri sendiri sebagai temuan:
    Byte order. "Angka yang terlihat masuk akal tapi salah, bukan crash" adalah
    kelas cacat yang sudah memakan waktu kita kemarin di DHT22: frame lolos
    checksum dan terbaca 124 %RH karena tergeser satu bit. Pemeriksaan struktural
    yang lolos tidak membuktikan penafsirannya benar.
    Multiplexed signal. Pengintai sinyal di dashboard mengasumsikan satu CAN ID
    selalu bertata letak sama. Kalau ID yang diintai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
2026-09-13 Phase 2: web dashboard for decoding ECU identifiers
    - Per-ID note field, stored on the device apart from capture files (D-015)
    - Identifier table in one view: hex over decimal, changed bytes lit, stale rows dimmed
    - Health panel: heap, task stacks, queues, driver frame loss, loop lag, CPU estimate
    - Capture files downloadable over WiFi; converter to webCAN CSV for the RE skill
    - Web assets moved out of C++ into web/, gzipped at build by tools/embed_web.py
    - WebDashboard split into routes, StateJson, JsonWriter, NotesStore, SystemHealth, FrameRing
    - "missed" now counts frames from the TWAI driver, not RX_QUEUE_FULL alert events
    - README states the CanManager/RawCanLogger divergence from the f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
    [CanManager.cpp, Config.h]
2026-09-19 PCB rev A: one hand-soldered board for the test device and the fleet unit
    - Circuit kept as data in hardware/gen_schematic.py; writes a KiCad 7
    schematic for EasyEDA import, netlist.csv and bom.csv
    - TJA1051T/3 with S tied high: the CAN transmitter is off in silicon
    - OBD-II connector has three poles only (CANH, CANL, GND); power comes from
    a fused ACC feed, never pin 16
    - 60 V buck input behind PTC, TVS and reverse-polarity diode
    - A7670C section optional: 4.0 V buck, 1.8 V UART level shifters, 2200 uF bulk
    - verify_schematic.py rebuilds connectivity from geometry and checks the
    safety rules; it caught all three injected faults
    [bmt-can-logger.kicad_sch, bom.csv, netlist.csv]
2026-09-20 Recover the HR-V capture off the device, and stop trusting serial for it
    The only recording of the HR-V bus was still on the device flash. It is now
    on the work machine: 34 segments, 8.8 MB, one continuous 3 min 23 s run.
    - tools/fetch_captures.py pulls captures over HTTP and checks each file
    against the size the device reported, parses every line and refuses to
    call a short file complete
    - tools/pull_captures.py does the same over the serial console, for a device
    with no WiFi, and warns that the link is unreliable
    - capture_to_webcan.py gains --start-ms/--stop-ms, to cut the burst of junk
    identifiers a bus emits while the connector is unplugged
    - docs/evidence/hrv-001.md records pr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
    [capture_to_webcan.py, fetch_captures.py, pull_captures.py]
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2026-09-22 One env per vehicle: DFSK Gelora E next, HR-V kept
    - The vehicle is chosen by PlatformIO env (hrv, gelora-e, gelora-e-250k),
    not by editing Config.h. A build with no vehicle stops with an error.
    - Identifier notes live in /notes/<UNIT_ID>/. Identifier numbers repeat
    across makes: the HR-V's "odometer" note on 0x294 must not appear against
    0x294 on another car. mkdir is not recursive, so /notes is created first.
    - CAN_DEFAULT_BITRATE can be overridden per env. The Gelora E has not been
    measured, so a 250 kbps build is ready for when the dashboard reads
    "Wrong bitrate, most likely". Verified in the object code: the 250k build
    carries no 500000 constant.
    - Run procedure gains an EV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
    [Config.h]
2026-09-22 Capture: continue after the last segment, and stop before flash is full
    Two hazards the Gelora E run would have hit, both found recovering hrv-001:
    - Segment numbering restarted at can-000 on every boot, and segments open
    for append. A new run was written INSIDE the previous run's file, on a
    different millis() base. startFileCapture now continues after the highest
    can-NNN.log on flash.
    - The 12 MB ceiling counted only this boot's bytes. With 8.9 MB of the HR-V
    run still on a 14.6 MB filesystem, a new run would have filled the flash
    and failed mid-write. The budget is now the smaller of the ceiling and
    the space actually free, less a 512 KB reserve for notes and metadata.
    Verifi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
    [Config.h]
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2026-09-22 gelora-001: the Gelora E bus reads at 250 kbps, and six values are mapped
    First electric vehicle, and the first time the cluster numbers could be
    matched to bytes within one session.
    - 250 kbps, not 500: at 500 the device logged 1,579,745 bus errors in 378 s
    and zero frames. All 34 identifiers are 29-bit extended, J1939-style.
    - Mapped against the head unit's CarInfo screen and the cluster:
    odometer 30410 0x18FEDCD5 b1-2 LE
    SOC 89.5 % 0x0CFF7D03 b1, x0.5
    pack 357 V 0x0CFF7E03 b2-3 LE
    SOH 97 % 0x0CFF7E03 b1
    battery temp 30/29 0x0CFF7E03 b6, b7, minus 40
    controller 26 C 0x0CFF1601 b2
    - Unconfirmed: current (b4-5 LE = 1000, offse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
2026-09-22 gelora-001: the BMS frames decode, and the pack is unbalanced
    0x0CFF8203 is multiplexed cell voltage: b1 is the first cell number, then
    three 16-bit little-endian millivolts. 0x0CFF8303 is the same shape for
    temperature sensors, minus 40.
    Three independent checks lock it in, so this is no longer a static-value
    coincidence:
    - index 1 gives 3.979 / 3.980 / 3.973 V against 3.979 / 3.980 / 3.972 V on
    the head unit, and index 4 matches the next three the same way
    - the 90 cells sum to 357.0 V, and the screen reads 357 V
    - the SOC frame's minimum, 3778 mV at cell 7, is the real minimum of that
    set, exactly where its index byte points
    Finding about the vehicle: cell 7 sits at 3.778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
2026-09-22 gelora-001: six notes now, and the cell voltage is no longer a guess
2026-09-22 Notes can carry live formulas, and name why frames go missing
    Dashboard: a note may now hold {expressions} over the identifier's latest
    payload, so the Name column reads "SOC 89.5 % selmax 3990 min 3776 mV" and
    keeps "b1=179 le16(3)=3990 le16(6)=3776" beside it. The operands stay on
    screen on purpose: a decoded number nobody can trace back to a byte is a
    number nobody can check. It is a small parser, not eval(), because notes are
    untrusted text that travels to every browser that opens the dashboard.
    Helpers: b0..b7, le16/be16/le24/be24/le32/be32(i), dlc.
    Frame loss, measured on the Gelora E: 31,548 of 31,643 lost frames were
    rx_overrun (the controller FIFO), not rx_missed (the driver queue)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
    [Config.h, capture_to_webcan.py]
2026-09-22 Stream frames over WiFi, and write up the Gelora E session
    Streaming exists because writing to internal flash costs bus frames on this
    framework: the TWAI interrupt lives in flash, every write disables the cache,
    and the controller FIFO overruns. WiFi does not disable the cache.
    - src/FrameStream.{h,cpp}: TCP server on port 3333, one receiver at a time,
    byte-identical lines to what the file would hold, provenance header on
    connect. Never blocks the storage task: when the socket is behind, the
    frame is dropped and counted, because stalling there costs bus frames.
    - HTTP control, so a phone can do what needed a laptop and a serial cable:
    POST /api/sink?mode=off|file pauses and resumes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
    [Config.h, main.cpp]
2026-09-22 Two bugs that made the stream silent, found by testing it against the device
    The first attempt connected, counted the session, and delivered nothing.
    Firmware: flush() gated writes on WiFiClient::availableForWrite(). ESP32's
    WiFiClient never implements it, so it inherits Print's stub that returns 0,
    and the gate was shut forever. It now sends straight to the socket with
    MSG_DONTWAIT, which was the actual intent: never block the storage task,
    because a blocked storage task fills the CAN queue.
    Receiver: the capture file was buffered, so a run killed rather than exited
    wrote nothing at all. Opened unbuffered now. A recording that only reaches
    disk on a clean exit is a recording you lose when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
    [stream_capture.py]
2026-09-22 Stream: one owner task, because two of them rebooted the device
    The first streaming test with a live bus rebooted the ESP32 within seconds:
    uptime went backwards and every counter reset. poll() ran on housekeeping
    while write() ran on storage, so two tasks moved the same staging buffer and
    called send() on the same socket. memmove with a length another task had just
    changed is exactly the crash that produces.
    poll() now runs on the storage task, the only task that writes frames, so the
    stream has a single owner. A recursive mutex guards it as well, taken with no
    wait in write() (that path drains the CAN queue and must never block) and a
    short wait elsewhere.
    Found by testing against the ve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
    [main.cpp]
2026-09-22 Flash over WiFi, so the cable stops being the bottleneck
    Every fix this session cost a trip to the vehicle: unplug the device from the
    harness, carry it to the laptop, flash, carry it back. OTA removes that for
    everything except a partition change and a firmware that will not boot.
    - partitions/avanza_test_16mb_ota.csv: two 2 MB app slots so the bootloader
    can switch. LittleFS drops 14.3 MB -> 11.9 MB, which is affordable now that
    frames stream to a laptop instead of into flash.
    - ArduinoOTA, hostname = UNIT_ID, and capture stops the moment an update
    starts: flash writes stall the CAN interrupt, so frames recorded during an
    update would be a recording nobody should trust.
    - OTA runs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
    [avanza_test_16mb_ota.csv]
2026-09-22 Revert "Flash over WiFi, so the cable stops being the bottleneck"
    This reverts commit 281e585730aac0a2e4d1831bf3f48b5feeecb9fb.
    [avanza_test_16mb_ota.csv]
2026-09-22 Streaming proved: 14.8% of the bus lost to flash, 0% over WiFi
    Measured on the Gelora E at ~640 frames/s, two 30 s phases back to back.
    Writing to the device's own flash lost 2,898 of 19,525 frames. Streaming the
    same bus to the laptop with that writer paused lost none, and the device did
    not reboot, so the single-owner fix holds under real traffic.
    Because the flash writing is itself the cause, stream_capture.py now pauses
    the device's recorder on start and restores it on exit, including when the
    process is killed rather than interrupted: a run cut short used to leave the
    device paused, and the next person would find a recorder recording nothing.
    --keep-flash opts out for a deliberate comp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
    [stream_capture.py]
2026-09-22 Buffer the stream for a WiFi stall, and show the drops that were hidden
    The first field run streamed 39,000 frames with "drops 0" on screen while the
    device had quietly thrown away 3,090 of them, 7 % of the bus. Two faults, one
    in each half.
    Device: the staging buffer was 4 kB, about 140 ms at 640 frames/s, so any
    hotspot stall longer than that overflowed it. Throughput was never the issue;
    28 kB/s is nothing. It is 64 kB now, roughly 2.3 s of stall, and it flushes
    once 4 kB is waiting rather than at half the buffer.
    Receiver: the counter on screen was this end's link breaks, which cannot see a
    frame the device dropped before sending. It now polls the device every 5 s and
    prints "device dr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
    [Config.h, stream_capture.py]
2026-09-23 Stop treating a full lwIP buffer as a dead receiver
    The second field run reconnected 338 times in 30 seconds and lost about 40 %
    of the bus. The cause was one line: flush() ended the session on any send()
    error other than EWOULDBLOCK/EAGAIN. lwIP also returns ENOMEM and ENOBUFS when
    it is simply out of buffers, which is a "try again", not a broken pipe. Every
    reconnect also reset the drop counter, so the loss stayed invisible.
    Only EPIPE, ECONNRESET, ENOTCONN and EBADF end a session now. Everything else
    counts a stall and keeps the data.
    Two counters that survive a reconnect were added, drop_all and stalls, because
    a per-session counter cannot report a fault that reconnects.
    s_up caches t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
2026-09-23 ProjectDocs: a handover layer that routes to docs/ instead of copying it
    This repo had no ProjectDocs at all, and no decision log, while referencing
    D-XXX twenty-four times across code and docs. Those numbers belong to two other
    repositories, and they already collide: D-006 means "feature freeze" in
    bmt-can-bus-telemetry and "decode once at the gateway" in project-mdt-tds. Both
    are referenced from here by bare number.
    03 now carries five decisions that are this repo's own (permanent listen-only
    enforced in three places, one PlatformIO env per vehicle, streaming over WiFi
    with flash recording paused, OTA cancelled, no sprints) and an inheritance table
    naming the source repo for every decisio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
2026-09-23 Dashboard shows what a person came to read, and says what it is hiding
    Asked for before the next flash: stop showing identifiers the dispatch system
    does not consume and identifiers nobody has mapped, so the screen is readable
    and the ESP32 does less work.
    The first half is done. The second half needs correcting, and the correction is
    written into the code and the docs rather than only said once: the dashboard is
    not why the device reports Overworked. Frames are lost because the CAN interrupt
    lives in flash, so every flash write stalls it, measured at 14.8 % against 0.0 %
    when streaming. Hiding rows does not touch that. What does is not writing flash
    while receiving, and a microSD slot on r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
    [notes.tsv]
2026-09-23 A recording switch on the page, and one backlog instead of scattered notes
    Two things asked for: fix the Overworked reading rather than hide it, and put
    everything we cannot do yet somewhere it will not be lost.
    On Overworked, the instinct about storage was right and the measurement backs
    it. Frames are lost because the CAN interrupt lives in flash, so every flash
    write stalls it: 14.8 % of the bus lost while recording, nothing at all lost
    with flash idle. So the fix for a session that only needs to WATCH the mapped
    values is not to record at all. That already existed as POST /api/sink, which
    means it was reachable from a laptop and not from a vehicle. It is now a labelled
    control in the Ca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
2026-09-28 tools: alat tiruan supaya kedua dashboard bisa dilihat tanpa alat
    Alat ada di mobil, layarnya perlu dilihat di meja. fake_device.py melayani
    kedua halaman dan setiap endpoint yang mereka minta, dalam bentuk yang
    firmware betul-betul kirim.
    Satu kendaraan tiruan menyetir keduanya, dan nilainya dikodekan kembali
    menjadi byte CAN seperti Gelora E mengirimnya. Jadi panel Vehicle
    menjalankan rumus dari notes.tsv terhadap payload yang sama, bukan
    menerima angka jadi, dan kalau rumus di catatan berbeda dengan tabel di
    SignalDecoder.cpp, pratinjau ini yang memperlihatkannya lebih dulu.
    Kendaraannya berjalan di utas sendiri, bukan didorong oleh permintaan.
    Kendaraan yang hanya bergerak kalau ditany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
    [fake_device.py]
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2026-09-28 Revert "web: panel Vehicle mengikuti formasi acuan kedua dari Direktur"
    This reverts commit 82d603c48c32b782f3f3be552af36dd56409354e.
    [notes.tsv]
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
